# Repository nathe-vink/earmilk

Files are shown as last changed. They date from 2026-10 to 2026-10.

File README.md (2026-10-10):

# earmilk — handoff for renders and critic

Floorstanding hi-fi speaker shaped like a half-gallon gable-top milk carton. Concept is settled on the canvas; this repo exists to (1) produce photoreal renders the canvas cannot, (2) run the fresh-context critic against a studio bar, and (3) hold the spec so nothing drifts.

Canvas (source of truth for layout, copy and proportions): https://claude.ai/artifact/2XeD5nstYFumubxf6jdS1g

## The idea in four lines

- A serious passive three-way that is, unmistakably, a half gallon of milk — and a cabinet that outlives its skin. *Amended 2026-10-08: active, with a plate amplifier in the back; and a bookshelf sibling.*
- The treble fires forward from the throat of a concave bowl carved into the front gable panel. The bowl is the waveguide. *Amended 2026-10-08: the bowl is now a waveguide shaped by acoustic simulation, in an insert set into the roof.*
- The cabinet is birch; the carton is a two-piece sleeve of heavy printed board (tube + lid). Swap the sleeve, keep the speaker. *Amended 2026-10-02: no sleeve. The carton is the cabinet, finished in the flavour's colours; the colour is fixed per speaker. See Amendments, 2026-10-02.*
- Flavor is the colorway. Six flavors. One voicing. *(Five until 2026-10-08, when the owner added a green one: Matcha. Since 2026-10-09 a matcha-green body with British racing green on the gable, fin and plinth and in the tweeter's waveguide.)*

Voice: dairy deadpan. The spec sheet is an FDA-style Nutrition Facts panel. One joke per surface, maximum.

## Decisions already made (do not reopen)

- Tweeter lives in the gable, facing forward, set back in a **concave** bowl. Not square, not angled up, not sunk vertically.
- Gable and fin are the **same color as the body** (the lid covers them). Bare birch shows in exactly two places: the back window and the bowl's exploded/section views. *Amended 2026-10-01: on the white-board flavours (Whole, 2%, Skim) the lid is printed in the flavour's print colour; Chocolate and Oat stay one colour, lid included.* *Amended 2026-10-02: the same colours, now as a finish on the birch gable itself; the bare birch places are the back panel and the section views.*
- **No tuning concept.** No cap, no tuning plates, no swappable tweeter modules. Flavor = colorway only.
- Nutrition Facts are **engraved** on the birch back window, above the port, with the binding posts below. The printed label frame is a separate deliverable (the label artboard), not printed on the sleeve.
- The sleeve's back panel is a frame around the birch window. *Amended 2026-10-02: no sleeve; the birch panel stays, inset in the finished back, and carries the engraved wordmark above the Nutrition Facts.*
- Sleeve options are the five flavors; "Dairy / Kraft / Night" no longer exist as names. *Amended 2026-10-02: the five flavours are finishes, chosen once.*
- Pint (desk-size, six to a crate, crate = amp + charger) is **parked**. Render it only in the mixed-crate shot; do not design its electronics.

### Amendments, 2026-10-01

Made after the first render and critic rounds, from the explorations in `explore/`. They stand with the Decisions above.

- **Lids.** Whole, 2%, Skim and Matcha carry the lid (gable and fin) in the flavour's print colour. Chocolate and Oat stay one colour.
- **Band.** A printed band of the print colour, 110 mm tall, wraps the base of the sleeve (front and sides; on the back only the frame below the window). The wordmark sits in the band, reversed in the board colour, on the front and the right side. Nothing is printed under the gable.
- **Stand, optional.** A painted block in the print colour, 390 × 390 × 110, with a 6 mm reveal under the carton. It takes the band's job and its wordmark; a sleeve used on a stand is printed without the band. It does not swap with the sleeve. The speaker stays passive; if a version ever went active, the stand is where controls would live.
- **Owner's panel, optional.** A print-to-order "Have you heard me?" panel on the right side above the band, 300 × 330 mm, in the print colour: headline, a halftone portrait, four rows the owner fills in. Not on the default sleeve.
- **Dropped.** Print rings around the drivers and whole-side colour fields.
- Prices stay open: add `[STAND PRICE]` to the list.

### Amendments, 2026-10-02

Made on the v4 and v5 renders. They stand with the Decisions above and replace the 2026-10-01 amendments where the two disagree.

- **No sleeve.** The carton is the cabinet. The colourway is a finish on the birch: the body in the board colour, the gable and fin in the accent colour on Whole, 2%, Skim and Matcha, Chocolate and Oat one colour all over. The colour is fixed per speaker, so every edge and bevel takes it. Nothing swaps. `[SLEEVE PRICE]`, the board-stock question and the sleeve-swap shot go away.
- **Plinth.** The band and the stand are one thing: a built-in plinth, the bottom 110 mm of the cabinet on all four sides, in the accent colour, inside the 1,055 overall height, with a 3 mm shadow line where it meets the body. (The shadow line, and the plinth sitting inside the height rather than under it, are this repo's reading; say so if either is wrong.)
- **Wordmark.** On the front only, as cast metal letters: the wordmark itself standing in relief on the plinth's front, no plate behind it, the way the lettering sits on a La Marzocco machine. On the back, engraved in the birch above the Nutrition Facts panel. Nowhere else: not on the sides, not under the gable. *(A plate version was rendered first and withdrawn the same day.)*
- **Dropped.** The owner's panel. Other milk-themed marks that are not about the owner are explored in `explore/2026-10-02/` and are proposals, not spec.
- **Shots.** 07 (sleeve swap) is retired. 02 (two rooms) loses the swap that was its point; it is rendered meanwhile with the same Whole in both rooms and needs a new brief. In 03 the fold of the lid's die-cut becomes the finish's edge at the mouth; in 04 the sleeve frame becomes the finished back around the birch panel.
- Prices: `[PAIR PRICE]` and `[CRATE PRICE]` stay open. `[SLEEVE PRICE]` and `[STAND PRICE]` are gone.
- **Back panel, contained** *(later the same day)*. The bare birch field is the Nutrition Facts panel plus a 26 mm margin all round: `x` 36 → 354, `z` 504 → 796. The port, the binding posts and the engraved wordmark sit on the finish outside it; the wordmark is engraved through the lacquer and ink-filled in the panel's brown, baseline at `z` 812; the post plate moves up to `z` 150 so it clears the plinth's shadow line. The full-height field (`x` 26 → 364, `z` 140 → 830, the same 26 margin at the sides and above the plinth) is kept as an option; both are rendered in `explore/2026-10-02/r4-*`.
- **Marks** *(later the same day)*. Two carton lines are spec and nothing else is printed: OPEN OTHER SIDE with its arrow on the back slope of the gable, 27 mm caps in the gable's other colour (board colour on the white flavours, accent on Chocolate and Oat), and SHAKE WELL on the plinth's back face, 26 mm caps reversed in the body colour. The other proposals in `explore/` are dropped.
- **Facts border** *(later the same day)*. The engraved panel is 266 × 260: "Contains no milk." sits inside the border with the same 14 mm padding as every other side. The bronze plate grows with it to `z` 484 → 796.
- **Bronze plate** *(later the same day)*. The Nutrition Facts are an engraved bronze plate, not bare birch: the Facts panel plus a 26 mm margin (x 36 → 354, z 504 → 796), 3 mm thick, 1.5 mm proud of the finish, the engraving dark with patina. The wordmark above it is the same cast metal letters as the front (44 mm, 2.5 mm proud, centred at z 826). Bare birch now shows only in the section views.
- **Shot 02, rebriefed.** The two rooms are the same pair in two homes, years apart: a bright first apartment, then a darker older house. The point is no longer the swap but that the speaker outlives its rooms, the finish fixed and the birch back ageing with the house.

### Notes, 2026-10-03

Render notes, not product decisions. Nothing here changes the Geometry or the Decisions.

- **The render path is now path-traced.** Chat image models could not hold the carton (two hand-made attempts, in `explore/2026-10-03/`), and the free Gemini API tier refuses image calls. So the model built from `spec/geometry.md` is exported from the real-time scene and rendered in Blender's Cycles (`render/pathtrace.py`, the `-pt` frames): the same geometry and copy, real light. The real-time frames stay as the layout check.
- **Rooms and sets.** The three rooms are closed boxes now (ceiling, right wall, a wall behind the camera), so the only daylight is what the window admits; the studio floor sweeps up into a backdrop. Out of frame in every shot.
- **Eased arrises.** *Since 2026-10-07 the main arrises are rounded 3 mm in the model itself (Amendments 2026-10-07), and the shader eases what is left (the eave, the grooves' edges, the scoop's cut) by 1.5 mm.* Before that: the path tracer rounds the cabinet's edges by 6 mm in the shader (since v18; 4 mm from v15, about a millimetre before), the way lacquer on birch actually sits; the silhouette does not change. The radius scales with the cabinet: 1.5 mm on the pint (since v20; at 6 mm its 2 mm fin rounded right through and the cartons looked inflated). Since v18 each driver's hole in the finish sits 5 mm inside its flange, so the rounding no longer shades a grey ring round the driver. Until v16 the rounding never reached the corners: each panel of the finish is its own mesh and the bevel only sees its own object, so the path tracer now joins each cabinet's finish into one object first. The prompts' rule against softening edges is about the silhouette. *Say if the spec wants the arrises dead sharp.*
- **Critic notes that are spec, not render** (path-traced round 1): the spout reads as a lens barrel at room distance (02b); the crate's wall hides the pints' drivers (06); the chair is a massing model, not furniture (02a). None acted on.

### Notes, 2026-10-04: fabrication

Fabrication notes, not product decisions. Nothing here changes the Geometry or the Decisions.

- **`fab/` turns the spec into things a shop can make:** a parametric CAD model (STEP and STL for every part), DXF cut files for the 18 mm birch panels with a cut list and nesting (three 5 x 5 ft sheets for a pair), the gable as a laminated block split for 3-axis milling or as four printable pieces, the bowl test slice, a two-piece printed port, the cast-letter wordmark and its placing templates, the engraved Facts plate, the terminal plate, vinyl stencils for the two marks, shop drawings, an acoustic worksheet, a driver shortlist and a parts list. Start at `fab/README.md`.
- **The outside is the spec; the inside is proposed.** Joinery, the mid's 8.0 L chamber, the brace, the groove, the gable's split and the tweeter pocket are marked `PROPOSAL` in `fab/params.py` and listed in `fab/README.md`.
- **From the solids:** 88.1 L net for the woofer (inside the 85 to 90 L assumed), a 152 mm port for 32 Hz, 27 kg of wood per cabinet.
- **The label and the physics disagree on one line.** The engraved Facts say 91 dB; a woofer that reaches 32 Hz in this box is rated about 90 dB, and voiced flat on this baffle the speaker should measure 85 to 88 dB. Engrave after measuring. "8 ohm" may become 6: every tweeter that fits the bowl is 4 ohm. *2026-10-07: printed now, not engraved, and just as permanent under the clear, so print after measuring.*
- **The wordmark at 44 mm type is 172 mm wide,** as the renders show; geometry.md's "about 155" is an estimate the type size overrides. The fab files follow the type size.

### Amendments, 2026-10-05: the pint and the crate

Made by the owner on the v13 crate shot ("the top driver is missing … the crate itself can be improved"). They stand with the Decisions above; the pint stays parked otherwise.

- **The pint mirrors the floorstander's drivers.** A woofer low and a mid high on its face, the big one's heights scaled by the body ratio (woofer ø 68 at 67, mid ø 40 at 160, replacing the single full-range at 95), and a small dome tweeter at the throat of its bowl, as the floorstander's sits at the throat of its own: a faceplate filling the ø 17 throat and a dome of about ø 9. The owner chose this layout over keeping one driver on the face. Its electronics stay undesigned.
- **The crate is a dairy crate.** The same 340 × 250 × 130 and 2 × 3, now moulded in warm white instead of five boards: rounded corners, a rolled rim, latticed walls, a hand-hold in each short end, a floor. The long walls have one window per pint, sized and placed to frame each front pint's woofer whole, which the plain crate's wall hid (path-traced round 1 asked whether the wall should drop; the windows answer it without changing the height); the mids stand above the rim. Still a crate and nothing more: no ports, lights, cables or controls.
- **Render polish, not product decisions** (v14): the tweeters' faceplates carry a polished chamfer, so the driver deep in each bowl reads as a driver; the domes are coated textile, not black holes; the lacquer has a faint orange peel, the cones pressed paper, the floors grain and the walls plaster; the studio adds two tall strips behind the subject for edge lines; the chair is a dining chair, not a massing model.

### Amendments, 2026-10-06: the critics' design points

Made by the owner on four points the refinement critics raised (v14 to v16). They stand with the Decisions above.

- **Dark letters on the light plinths.** The cast letters on Chocolate's cream plinth and Skim's pale blue one are dark bronze (`#6B4A2C` faces, `#45301D` sides); polished, they read as white on white, as two critic rounds said of the line-up. The other three plinths keep polished letters. The back's letters are unchanged.
- **A polished lip at the scoop.** *Withdrawn 2026-10-07 (the owner): no lip, see below.* A stainless half-round lip rings the bowl's mouth over the finish's cut edge and the bowl's joint, 4.8 wide and 1.6 proud on the floorstander and scaled on the pint, the same on every flavour, so the opening reads as a made scoop and not a hole at room distance (every critic round read it as a hole, an eye or a lens).
- **A three-quarter back view.** Shot 04 has two frames: the straight-on back as before, and a three-quarter from the back-left with the gable's end, a side and the cabinet's shadow, which every critic round on the back asked for.
- **Chocolate's throat runs dark,** from the body brown at the mouth to a dark chocolate at the throat (`#5E3A1F` to `#2B170B`; it ran cream to tan, paler than the brown face around it).
- **Render polish, not product decisions** (v17): the tweeter's faceplate sits in a moulded ring where the throat ends (the close-up's critic saw no seat); the hero's window moves to the wall behind the camera so the sun takes the fronts; the bright room's window narrows so its beam lands on the cabinet; the older room's window widens so its patch shows on the back wall. v18 and v19: the hero's and the older room's back walls come nearer, so each cabinet's shadow climbs the wall in the sun's patch; the bright room gets a French door, so the cabinet's whole shadow lies on sunlit boards; the studio sweep turns to face the three-quarter back camera; the crate's rows sit 136 apart, so each woofer stands just behind its window; the tweeter's seat ring is satin metal (black, it vanished against the faceplate).

### Amendments, 2026-10-07: the Facts printed on the body

Made by the owner after the v17 to v19 critic rounds. They stand with the Decisions above and replace the 2026-10-02 bronze plate.

- **The Nutrition Facts are printed on the body, not on a bronze plate,** so the back reads like a real carton's. The same panel (266 × 260, top at z 770, the copy in `copy/label.md`) is printed directly on the back's finish: a warm near-black (`#1E1A17`) on the white flavours, the print colour on Chocolate (cream) and Oat (brown). The plate, its pocket and its patina go; the cast letters above and the port and posts below stay where they are.
- **It must not scratch off, so the ink goes under the clear.** The panel is printed on the cured colour coat and buried under the 2K clear that covers the whole cabinet, then flatted level, the way a guitar's headstock logo is sealed: a scratch has to cut through the clear before it reaches the ink. On the assembled cabinet that is a screen print with a catalysed (2K) ink, or a water-slide decal for a one-off; test the ink under the clear on a sprayed card first, as with the colours (`fab/README.md`, step 7). OPEN OTHER SIDE and SHAKE WELL are already in the paint, so all three printed marks now sit under the clear.
- **No lip at the scoop, and no bright metal.** The polished stainless lip of 2026-10-06 goes: the bowl's mouth is the finish's own cut edge, eased, and the tweeter's chamfer and seat are moulded black. Four options were rendered (`explore/2026-10-07/`); the owner chose this one, "it looks like a diner" being the polished lip's problem.
- **The edges are rounded in the model.** 3 mm on the body's four vertical corners and the gable's four hips, 1.5 mm on the fin's edges, scaled on the pint, so the corners catch a highlight and the outline softens by that much (it was dead sharp, with the rounding only in the shader; nearly every critic round called the edges knife-sharp). This replaces the render rule against softening edges.
- **A shadow line under the gable.** A 3 mm dark groove where the gable meets the body, `z` 857 → 860 on all four sides, like the plinth's at 110 → 113, so the gable reads as a separate, made part.
- **OPEN OTHER SIDE on the fin** (later the same day): the line and its arrow move from the back slope to the fin's back face, the top fold, centred on its visible height, the same 27 mm caps in the gable's other colour; the slope stays clean. Rendered both ways in `explore/2026-10-07/r7-*`; the owner chose the fin.
- **The back's letters centred between the edge and the Facts** (later the same day): set at `z` 813 (was 826), so their ink has 27 mm of white above it, to the shadow line under the gable, and 27 mm below, to the Facts' top border.
- The canvas still shows the bronze plate (since its version 13), the lip and sharp edges. It is not edited from here; say if it should be.
- **Render polish, not product decisions** (v22, v23): the rounds after the owner's geometry changed the sets, the lenses and how the finish is modelled, not the product. v22: one camera for both rooms of shot 02, as its brief asks, wider and level; the hero's camera further round and closer, its back wall 2.5 m behind the pair, so no carton's shadow climbs it; the bright room's sun lower, laying its patch on the wall behind the chair; the close-up's key a narrow strip and the bowl's paint flatter; the backs and the line-up on a darker set with the backdrop lit on its own; the crate whole on the left page. v23: the finish modelled as what it is, a colour coat with no gloss of its own under a full 2K clear (it was a glossy colour coat under a thin clear), and the clear takes the eased edges; AgX's very high contrast look in the studio, so the white reads white; an edge light on each corner the camera sees, seen only in reflections where a 3 mm round is a pixel or two wide; the straight-on back shot from 1.3 m, level, because from the panel's height the gloss roof mirrored the fin's OPEN OTHER SIDE upside down beneath it (a real lacquered carton would do the same); the port's tube a real black plastic's 3 % (it was 1 %, which read as a hole).

### Amendments, 2026-10-08: the critics' requirements

Made by the owner after the v21 to v23 critic rounds on the 2026-10-07 look ("address the additional critic requirements"): the five points those rounds raised and this repo put to the owner. They stand with the Decisions above.

- **The edges rounded 6 mm.** The body's four vertical corners and the gable's four hips 6 mm, the fin's edges 3 mm (3 and 1.5 on 2026-10-07): at room distance a 3 mm round is two pixels, and every critic in the batch still called the corners knife-sharp. Scaled on the pint.
- **The tweeter forward, on a seat.** The faceplate 125 behind the front face (it was 170) in a 74 throat (it was 66), whose end is a flat ring 6 wide in the throat's colour with the faceplate flush in it, its chamfer black. From 170, every camera off the axis saw the faceplate pushed into the far end of the mouth and cut by its rim, a lens or an eye. The mouth is unchanged, so the bowl is shallower: its lower lip still bounds the pattern, at about 17° below the axis (12° before); the upper lip no longer does (37° before). The tweeter reaches a seated listener 0.24 ms after the mid in the crossover model (0.37 before). The pint's bowl follows by its scaling rule (throat ø 19).
- **The drivers flush and finished.** Each frame sits in a rebate, a satin black trim ring over it and its screws, the ring's face level with the finish and a 0.8 reveal round it; the cones charcoal paper with pressed concentric ribs, the dust caps satin. Proud on bare frames with eight screws, every round read them as stock parts. The woofer moves up 30, to `z` 320, so its frame clears the plinth's shadow line by 52 (it was 22). The pint's woofer stays where its crate's windows frame it.
- **The cast letters 1.5 proud, their sides finished like their faces,** front and back (at 2.5 with darker satin sides they read as an extrusion with a drop shadow).
- **A recessed terminal cup.** The posts stand on the floor of a cup 18 deep; its 128 × 64 flange, 3 proud of the finish on four screws, is centred at `z` 175 (the flat plate at 150 sat 5 above the plinth's shadow line, its black post lost on it).
- **The Facts values in bold,** like the names (Regular read pale grey at every size short of full).
- **Two briefs change.** Shot 04a becomes a straight-on detail of the label, and shot 05 a raised three-quarter of the five with the frame's centre line between two cartons; every critic round asked for a three-quarter of each.
- **Render polish, not product decisions** (v24 to v26): every frame through Khronos PBR Neutral rather than AgX, whose looks turned a lit red salmon and a lit blue periwinkle; the indirect light clamped against fireflies; the studio's edge strips hidden from the camera, and in the line-up gone; figure in the floorboards' colour, broad enough to read across a room; lights seen only in reflections, placed where a round or a slope mirrors them into the camera, on the cartons' corners, the slopes and the cast letters (v26: thin lines, not bands); the clear polished (roughness 0.05, was 0.1) with less orange peel, so a light draws a line rather than a pink wash; the cast letters' planes cut down to their glyphs, so the denoiser draws no rectangle round them on a dark plinth; the label detail shot from 1.9 m, so the gloss slope no longer mirrors the fin's OPEN OTHER SIDE; the close-up on a 100 mm lens; in the rooms, a cool fill from the hero's camera side, the bright room's left wall given the skirting the back wall had, and the older room's back wall nearer, so the low sun lays a silhouette that reads as the carton. Found by the critics and fixed in the model: with 6 mm rounds the birch core's square corners stood through the finish, first at the rounds, then where the gable's shadow line meets them.

### Amendments, 2026-10-08 (later): active, the waveguide by simulation, the bookshelf

From the owner's request of 2026-10-08: the tweeter's job is to spread sound correctly, so its shape is optimised for
that whatever it looks like; build proofs of concept of a floorstander and a bookshelf; model the real equipment
that goes in them, built-in amplifiers included.

- **Active.** A Hypex FusionAmp plate amplifier in each speaker (FA253, three channels, in the floorstander; FA122,
  two, in the bookshelf) drives each driver from its own channel; its DSP is the crossover, delays and EQ. The plate
  sits flush in a rebate on the back, its module in its own sealed box. The passive network (`fab/crossover.py`) is
  gone; the DSP's starting setup is `fab/dsp.py`. The research is in `fab/research/amps.md`.
- **The waveguide replaces the bowl,** designed and checked by a boundary-element simulation of the whole roof
  (`fab/bem.py`): the floorstander's throat at 176 behind the face and 935 up holds about +-40 degrees horizontally
  from 2 to 8 kHz with the listening axis within a dB of the loudest direction; the owner's 125 / 903.5 beamed 30
  degrees up at 2 kHz. It is a separate insert in a pocket in the roof, the tweeter rear-mounted on it, held by
  magnets and unplugging at a connector in a bay behind it, so the tweeter can be serviced from the front.
  `fab/out/acoustics/waveguide/README.md`.
- **The drivers are named:** Dayton RSS315HF-4, SB Acoustics Satori MR16P-8 and TW29DN-B (its faceplate off) in the
  floorstander; SB Acoustics SB17NRX2C35-8 and Scan-Speak Illuminator D3004/602200 in the bookshelf
  (`fab/research/`). The renders' drivers and amplifier plates are modelled from their datasheets.
- **The bookshelf:** the same carton at 220 x 220 plan and 594 tall, a sealed two-way with the woofer high on the
  face, its own waveguide study (it crosses at 2.4 kHz), the Facts on its right side as on a real carton because the
  back holds the amplifier. Built from the same `fab/params.py` with `EARMILK_SIZE=bookshelf`, into
  `fab/out-bookshelf/`.
- **For the owner:** the Facts' "8 ohm" and "91 dB" mean nothing on an active speaker (the inputs are line level);
  the bookshelf's Facts already say power and inputs instead. Raising the mid to z 760 would widen the floorstander's
  vertical window at the crossover from about 14 to 20 degrees. Both are the owner's to decide.

### Notes, 2026-10-04: tools and the family

Tooling notes, not product decisions. Nothing here changes the Geometry or the Decisions.

- **From scratch.** `studio/setup.sh` installs every tool the repo uses on a bare machine (render/'s node modules, Blender's `bpy`, the CAD venv) and `python3 studio/doctor.py` runs each one for real. In a Claude Code cloud session the start hook does this before work begins. `studio/README.md` lists the tools: a path tracer for any product's scene, canvas-exact typesetting, a crossover designer, a product template.
- **Crossover, from models.** *Superseded 2026-10-08: the speakers are active and `fab/crossover.py` is gone; see the amendments above.* `fab/crossover.py` fits a three-way network to the shortlisted drivers (`fab/out/xover/`): Linkwitz-Riley targets at the label's 350 Hz and 2.2 kHz, 14 parts, the sum within about 2 dB from 150 Hz to 16 kHz in the model. Two numbers to carry: the tweeter, 170 mm back in the bowl, reaches a seated listener 0.37 ms after the mid; the network's impedance bottoms at 3.7 ohm, a 4 ohm speaker. *2026-10-08: 125 mm back, 0.24 ms and 3.5 ohm.* Fit the built network to measurements.
- **The family.** Two spin-offs are started in `spinoffs/`, each with its own brief, model, renders and critic log: **earworm**, wired headphones whose cable is an earthworm (the saddle is the remote), and **earwig**, earbuds whose flexible tails of overlapping plates end in forceps, with a case whose lid is split like an earwig's wing covers (the wig went, 2026-10-06). Proposals for the owner; neither touches earmilk's spec.

## Geometry (mm)

Floorstander — square plan, gable-top.
- Plan 390 × 390. Body 860 tall. Gable rise 150 (front edge → ridge). Fin 45 above the ridge, ~8 thick. Total height 1,055.
- Carton proportions match a US half gallon scaled ×4.1. Slope panel length along the slope: 246.
- Cabinet: 18 mm Baltic birch, braced. The gable is a solid carved birch block on top of the body (CNC).
- Front drivers (centers from floor, on the baffle centerline): 12 in woofer at 290 (frame ø ~310); 6.5 in mid at 690 (frame ø ~170). *Amended 2026-10-08: the woofer at 320; both flush, under satin black trim rings.*
- Tweeter: 1 in dome with a small faceplate (≤ 62 mm). Faceplate plane is 170 back from the front face; dome center height 903.5. *Amended 2026-10-08: 125 back.*
- Bowl: mouth is an ellipse on the front slope panel, 211 wide × 118 long along the slope, centered 79 up the 246 slope (from 20 to 138). Throat ø 66 around the faceplate at the 170 setback. Surface is a smooth loft from mouth ellipse to throat circle — no flats, no edges. As drawn the lower lip holds the pattern to ~12° below the tweeter axis and the upper lip to ~37° above. Deeper bowl = narrower; wider mouth = wider. *Amended 2026-10-08: throat ø 74 at the 125 setback, the faceplate seated flush on its flat floor; the lower lip holds the pattern to about 17° below the axis and the upper lip no longer bounds it.*
- Back (bare birch window inside the sleeve frame): window x 26→364, z 40→798. Engraved Nutrition Facts panel 266 wide × 240 tall, top at z 770 *(266 × 260 since 2026-10-02)*. Round port ø ~100 centered at z 405. Binding posts on a 128 × 64 plate centered at z 144. *Amended 2026-10-08: in a recessed terminal cup, its 128 × 64 flange centred at z 175.*
- Sleeve: tube 390 × 390 × 860 (open top and bottom, die-cut for woofer and mid, back panel is a frame), plus a lid covering gable + fin, die-cut at the bowl mouth. Both lock at the back seam. Board: heavy carton board / SBS, target ~1.2–1.5 mm; whether it holds a crisp fold at this size is an open test. *Amended 2026-10-02: no sleeve. The outer dimensions stay; the skin is the finish.*

Pint — 100 × 100 plan, body 200, gable 35, fin 12. Single full-range ø ~68 at 95; tiny bowl at the top. Crate 340 × 250 × 130, 2 × 3. *Amended 2026-10-05: a woofer ø 68 at 67 and a mid ø 40 at 160 on the face, a small dome tweeter at the bowl's throat; the crate is a moulded dairy crate whose windows frame the front pints' woofers.*

Stand (optional accessory, amended 2026-10-01) — 390 × 390 × 110 painted block, 6 mm reveal. With the stand: overall 1,171; tweeter axis 1,019.5. *Amended 2026-10-02: replaced by the built-in plinth, z 0 → 110 of the cabinet, accent colour, 3 mm shadow line at z 110 → 113; overall height stays 1,055.*

Wordmark on the plinth (amended 2026-10-02) — cast metal letters, no plate: Archivo Black at 44 mm type size, 2.5 mm proud (*1.5 since 2026-10-08*), centred on the plinth's front at z 55. Back wordmark engraved in the birch panel, 36 mm type size, baseline at z 788, centred; the birch panel now runs z 113 → 830 so it has room (x 26 → 364 as before).

## Target specs (label copy — marked as targets, not measured)

Sensitivity 91 dB (2.83 V / 1 m) · 32 Hz–20 kHz ±3 dB · 8 Ω · 40–250 W · crossover 350 Hz and 2.2 kHz · 36 kg each · 1,055 mm.
Footnote stays: "Contains no milk. Not a significant source of Bluetooth."

## Colorways (flavors)

White board unless noted. Print = wordmark on front and side. Throat = bowl interior, light at the mouth → dark at the throat. *Amended 2026-10-01: print = the lid on the white flavours, a 110 mm base band, and the wordmark in the band on the front and the right side; see Amendments.* *Amended 2026-10-02: "board" is the body finish and "print" is the accent finish (gable and fin on the white flavours, the plinth on all five); the wordmark is the badge and the back engraving, not print.*

| Flavor | Board | Print | Throat (mouth → throat) |
|---|---|---|---|
| Whole | #FFFFFF | #C62828 | #C62828 → #8E1B1B |
| 2% | #FFFFFF | #1F4FCF | #1F4FCF → #153792 |
| Skim | #FFFFFF | #6FA5DC | #8FBBE8 → #4F86BF |
| Matcha | #A4C26B matcha green | #004225 British racing green | the gable, fin, plinth and the tweeter's waveguide insert in the accent, as on the other flavours *(added 2026-10-08; the body matcha and the insert dark green since 2026-10-09, the owner)* |
| Chocolate | #5E3A1F (whole board) | #F1E3CC | #5E3A1F → #2B170B *(2026-10-06; was #E2CBA3 → #A97E4F)* |
| Oat | #D9BC92 unbleached | #2B2118 | #8E6A3E → #5C4224 |

Birch: #EAD8B0 face, #D4BE95 side, engraving #6B5232. Ground for flat compositions: #F8F7F4.

## Type

Archivo Black (wordmark, label title) over Archivo (everything else). The wordmark is lowercase "earmilk", tight tracking. Nutrition Facts panel follows FDA proportions: heavy title, 10 px rule, 1 px row rules, bold labels, right-aligned values.

## What this repo produces

### 1. Renders (image generation happens here, not in chat)

Photoreal, physically plausible materials: matte printed board with visible fold creases at the gable, birch end-grain at the back window, black paper cones, the throat as a smooth painted bowl. No grilles. No glossy plastic. Proportions exactly as the geometry above — the carton silhouette is the whole idea, so do not "improve" it.

Shot list, in priority order:
1. **Hero pair in a room.** Whole, late-afternoon window light, a chair or sofa arm in frame for scale, speakers ~2 m apart, 3/4 view, camera at 1.2 m with a ~50 mm look.
2. **Two rooms, years apart.** The same floor spot and the same speaker, once in Whole in a bright apartment, once in Oat in a darker, older room. This is the sleeve argument; it must read as one object that changed its skin. *Amended 2026-10-02: no sleeve, so no skin change. Rebriefed: the same pair in two homes, years apart, a bright first apartment and then a darker older house; the point is that the speaker outlives its rooms.*
3. **Bowl close-up.** Front 3/4 at gable height, the throat and the dome in focus, the fold of the lid's die-cut visible at the mouth edge. *Amended 2026-10-02: the mouth edge is the finish's edge on the carved gable.*
4. **Back.** Straight-on, engraved label legible, port and posts, the sleeve frame around the birch. *Amended 2026-10-02: the finished back with the bare birch field around the Facts panel only, the wordmark engraved above it, the port and posts on the finish below.* *Amended 2026-10-06: two frames, (a) straight-on as before and (b) a three-quarter from the back-left, about 33° off the back face and 10° up, with the gable's end, a side and the cabinet's shadow in frame.* *Amended 2026-10-07: the Facts printed on the finish, legible, no plate.*
5. **Six flavors lineup.** Flat ground, equal spacing, in flavor order.
6. **Mixed crate** on a desk, six pints, one of each flavor.
7. **Sleeve swap**, three frames: lid off, tube sliding, new flavor on. *Retired 2026-10-02: no sleeve.*

Keep every render's dimensions consistent; drift in the carton's proportions between shots is a failure.

### 2. Critic

Run after each render batch. Fresh context, screenshot only — the critic sees images, not the brief, not this file. Prompt it as a design-studio creative director with a shipping bar: name the three biggest gaps, say what a studio would fix first, score /10. Iterate at most three rounds per shot. Log each round in `critic/LOG.md` (shot, round, gaps, score, what changed).

### 3. Spec drift check

Before any render or edit, re-read the Geometry and Decisions sections. If a change to them seems necessary, stop and ask; do not improvise a new mechanism, a new flavor, or a new driver layout.

## Open questions (do not assume answers)

- Price points for the pair, a sleeve set, and the crate. Leave as `[PAIR PRICE]`, `[SLEEVE PRICE]`, `[CRATE PRICE]`, and since the amendments `[STAND PRICE]`. *Amended 2026-10-02: `[PAIR PRICE]` and `[CRATE PRICE]` only.*
- Driver selection and port tuning. The 32 Hz target assumes ~85–90 L net for the woofer; confirm before quoting it as more than a target. *2026-10-04: the CAD measures 88.1 L net; `fab/README.md` has a driver shortlist, the port (152 mm for 32 Hz) and a simulation. Proposals, not answers.*
- Whether the bowl works as a waveguide. The test is physical: one carved gable, one candidate tweeter, on/off-axis measurements vs. a flat baffle. Renders do not settle this. *2026-10-04: `fab/out/stl/gable-test-slice.stl` is that gable, printable in a weekend.*
- *Added 2026-10-04, from the crossover model:* whether the label's crossover points (350 Hz and 2.2 kHz) survive measurement, whether the 0.37 ms the bowl puts between mid and tweeter is handled passively or the tweeter comes forward, and whether the label can say 4 ohm. *2026-10-08: the tweeter came forward to 125 (the owner, for the look), which cuts it to 0.24 ms in the model.*
- *Added 2026-10-04, from fabrication:* whether the Facts should state targets or measured figures (91 dB and 8 ohm are unlikely as measured; the plate is permanent, and so is the print under the clear that replaced it on 2026-10-07); whether the gable may be printed and painted instead of carved birch; the letters' metal (silver as rendered: stainless or aluminium; or brass to sit with the bronze plate); whether the wordmark's width (172 mm at 44 mm type) or geometry.md's "about 155" is the one that matters.
- *Added 2026-10-03, from the path-traced critic rounds:* whether the pint crate's wall should drop so the drivers show; whether the spout's dome needs a different read at room distance (three rounds called it a lens barrel); whether the cast letters on Chocolate and Oat should be a darker metal, since polished metal on a cream plinth reads as blank in a pale studio; and whether the tweeter wants a visible flange in the bowl. All geometry or materials; none acted on in renders.
- *Added 2026-10-06, from the v17 to v19 critic rounds (the first two answered 2026-10-07: a 3 mm shadow line under the gable, and the arrises rounded 3 mm in the model):* a reveal where the gable meets the body (the plinth has its 3 mm shadow line; the gable has none), asked for in this batch and the last; whether the arrises may be eased in the model, rounding the silhouette by 6 mm (the render rules keep it sharp, and the shaded rounding has not cleared the critics' "knife edges" in any round); taller crate windows that also show the plinths, so each woofer reads as its carton's; whether the back's letters, polished on every flavour, should go dark on the white bodies as the light plinths' have; a narrower Facts table, since at a raking angle its right-aligned values read as one row low. The tweeter at the back of its throat has read as an eye, a lens or a webcam in most rounds since v14 (the 2026-10-03 question on the spout's dome stands). None acted on in renders.
- *Added 2026-10-08, from the critic rounds on the owner's 2026-10-07 look (v21 to v23):* the tweeter still reads as a lens or an eye from off its axis (the bright room: "the carton seems to watch the room"; the line-up: "pupil, pupil, pupil"), and in the line-up Chocolate's and Oat's darker throats hide it, so the row reads as two models; the woofer's frame sits close to the plinth's shadow line, which the critics call bottom-heavy; the cast letters' 2.5 mm sides read as a drop shadow on the light plinths; and the edges: at room distance a 3 mm round is two pixels, every critic in the batch still called the corners knife-sharp, and about 6 mm is what would read (3 mm was my recommendation). All spec, so left as they are. *Answered the same day by the owner: see Amendments, 2026-10-08.*
- *Added 2026-10-08, from the v24 to v26 rounds on the owner's answers:* the tweeter, seated 125 back, still sits against the scoop's upper lip from any camera above its axis (the crate from 21 degrees above: "a pupil rolled up"; the bright room: "a webcam lens or an eye"), because the throat's end is 15 mm behind the upper lip and from above projects at the top of the mouth; whether the close-up (03) and the label detail (04a) may be briefed as whole cartons on a floor, which every critic of both asked for in every round; the wordmark's tight tracking, at which the a's bowl all but touches the r's stem (cast letters that touch are cast as one, or the tracking opens a little); the Facts' band under the title, empty as drawn on the canvas, which a critic read as a missing row; Skim's dark bronze letters, which the line-up's critic read as Chocolate's brown.
- *Added 2026-10-10, from the engine's critic rounds:* the woofer's cone. The spec (2026-10-08) asks for charcoal paper cones with pressed concentric ribs; the floorstander's shortlisted woofer, Dayton's RSS315HF-4 (chosen for its Qts and Vas against the 88 L box and its excursion, `fab/research/drivers-floorstander.md`), has an aluminium cone, and the renders show that cone (critics have read it as anodised metal, blue or bronze by turns, from what it mirrors). Either the paper look moves to a paper-coned woofer (the research's alternative is the DS315-8, coated paper, with far less excursion) or the spec takes the aluminium cone. The trim rings, which rendered as a gunmetal the critics read slate-blue, were put back to the spec's satin black the same day.
- Board stock for the sleeve and whether the lock survives repeated swaps. *Gone 2026-10-02 with the sleeve. In its place: the finish system (lacquer, paint or laminate over the birch) and the badge's metal are open.*

## Suggested layout

```
spec/        geometry.md (this file's numbers, expanded), colorways.json
copy/        label.md, hero.md
prompts/     one file per shot, versioned
renders/     YYYY-MM-DD/shot-NN-vN.png
critic/      LOG.md
render/      the model, the real-time and path-traced renderers
fab/         fabrication: CAD, cut files, drawings, acoustics, crossover, parts list (fab/README.md)
studio/      the tools for any product: setup, doctor, path tracer, typesetting, crossover designer, template
spinoffs/    the rest of the family, one folder each: earworm (wired headphones), earwig (earbuds)
.claude/     the cloud session's start hook and the project skills (new-product, pathtrace, critic-round, fab-package)
```

## Deliver pass already applied (for context)

Cut: the cap and all tuning concepts; the four-way treble study (replaced by one section); printed Nutrition Facts on the side panel (now engraved on the back; side carries the wordmark); the flavor word under the wordmark; the Gallery sleeve; the Ingredients footnote; duplicate engravings; the full-carton sleeve (now tube + lid); the Dairy/Kraft/Night skins (folded into flavors).

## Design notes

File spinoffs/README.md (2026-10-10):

# The earmilk family

Products that share earmilk's rule: one joke, said once per surface, on a product that would be good without it.
Each folder holds a brief (`README.md`), its numbers (`params.py`), a parametric model (`model.py`, build123d), a
scene for the path tracer (`scene.py`), renders and a critic log. All of it is a proposal until the owner signs it.

| Product | What it is | The joke | Status |
|---|---|---|---|
| [earmilk](../README.md) | floorstanding three-way speaker | a half-gallon milk carton | spec, renders, fabrication package |
| [earworm](earworm/README.md) | wired over-ear headphones | the cable is an earthworm; its saddle is the remote | concept: model, printable cups, renders, critic |
| [earwig](earwig/README.md) | true-wireless earbuds | flexible tails of overlapping plates ending in forceps (pinch to play); a lid split like wing covers | concept: model, renders, critic |
| [earnest](earnest/README.md) | valve amplifier, by the pack of 6, 12 or 24 | an egg crate whose eggs are the valves; a white egg turns the volume | concept: model, renders |
| [barkhorn](barkhorn/README.md) | two-way hybrid horn loudspeaker, after Friendly Pressure | none: birch bark or eucalyptus bark, each horn painted from its bark's colours | concept: fab package (studio/fabkit), proof renders |

Start the next one with `python3 studio/new_product.py NAME --title NAME --kind "What it is"`, then follow the
`new-product` skill (`.claude/skills/new-product/SKILL.md`).

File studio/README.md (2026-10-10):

# studio: the tools, for any product in the family

Everything here works from a bare container: `studio/setup.sh` installs it and `python3 studio/doctor.py` proves it
runs. In a Claude Code cloud session the start hook (`.claude/hooks/session-start.sh`) runs `setup.sh` for you.

| Tool | What it does | Runs on |
|---|---|---|
| `setup.sh` | Installs everything the repo needs: render/'s node modules, Blender's `bpy` with numpy 1, the CAD venv `.venv-fab` with build123d, ezdxf, HarfBuzz, matplotlib, scipy. Idempotent: a few seconds when nothing is missing. `--doctor` runs the doctor after. | bash |
| `doctor.py` | Runs every tool for real at a tiny size: Chromium draws WebGL 2, Cycles renders a cube, build123d builds and exports a solid and HarfBuzz sets the wordmark, earmilk's spec check passes. Exits non-zero on any failure. | system Python |
| `fabkit/` | A fabrication package for any concept from one product file: each part a solid with how it is made (cut from sheet, printed, machined, bought) and finished. The kit reads the cut files (DXF layers by operation, nested on stock), checks clashes and print walls, writes the parts list with budgets, an A3 drawing set (arrangement, section, exploded view, every panel with a feature table, printed parts) and the render model with a proof shot for the engine. Speaker helpers: drivers from datasheet numbers, Thiele-Small boxes, horn profiles. See `fabkit/README.md`; the worked example is `fabkit/example/product.py`. | `.venv-fab` |
| `new_product.py` | Starts a product from `template/`: `python3 studio/new_product.py earworm --title earworm --kind "Wired headphones"` makes `spinoffs/earworm/` with a brief, `params.py`, `model.py`, `shots.json` and a critic log. | system Python |
| `engine/` | The render engine: a product's CAD (a GLB of named parts) and a shot file of named settings in, a photograph out, with the resolved settings, each part's place in the frame and a part-id mask beside it, so a critic can measure by part and prescribe changes the next render applies. Rooms and sweeps, sun, sky, lamps and glints, materials by part name, prints as decals under the finish, exploded views, cutaways, several products in one frame. See `engine/README.md`. | system Python (bpy) |
| `pathtrace.py` | Path-traces a product scene described in JSON with Blender's Cycles: CAD meshes, generated tubes (cables and worms: grooved rings or overlapping segments like a jointed toy snake, blended bands, radius by distance, flattening on a floor), Python hooks (hair), material presets, light rigs that size themselves to the subject with strips and pins, cameras with depth of field. | system Python (bpy) |
| `poses.py` | Lays small parts down on a floor: a part's up and length vectors, a heading, and it tilts until both ends rest (earbuds on a table). Returns the scene's translate and rotate, and maps points on the part into the world (where a cable leaves a bud). | any Python |
| `typeset.py` | Sets text exactly as the canvas does (HarfBuzz shaping, canvas-style tracking) and writes SVG, DXF and vector PDF: wordmarks, plates, stencils, debossed lettering in CAD. | `.venv-fab` |
| `xover/xover.py` | Passive crossover design: drivers from FRD/ZMA measurements or Thiele-Small models, any R/L/C network by nodal analysis, delays from where the drivers sit, a least-squares fit to Linkwitz-Riley or Butterworth targets, values snapped to parts you can buy, plots and a parts list. See `xover/README.md`. | `.venv-fab` |
| `template/` | The skeleton `new_product.py` copies. | |

Why two Pythons: Blender 5's `bpy` wheel needs numpy 1 and build123d needs numpy 2. `bpy` stays on the system Python
and the CAD stack lives in `.venv-fab`. Installing build123d into the system Python breaks the path tracer;
`setup.sh` puts numpy 1 back if that happens.

The workflows are written up as project skills in `.claude/skills/`: `new-product`, `pathtrace`, `critic-round` and
`fab-package`.

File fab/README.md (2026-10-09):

# Fabrication

Everything needed to have earmilk made, in two sizes, from one file of numbers (`params.py`): the **floorstander**, a
three-way, and the **bookshelf**, its two-way little sibling. Both are active: a Hypex FusionAmp plate amplifier in
the back drives each driver from its own channel, and its DSP is the crossover. Change a number, run `build.sh`, and
every cut file, model, drawing, chart and the renders' model follow. `fab/out/` holds the floorstander,
`fab/out-bookshelf/` the bookshelf.

The outside is the spec (`spec/geometry.md`; the bookshelf is the same carton at 0.564 scale with its own plinth and
type sizes). What is inside, and how it goes together, is this folder's **proposal**, marked `PROPOSAL` in `params.py`;
the bought parts' sizes are the research's, marked `PLACEHOLDER` until the parts are in hand.

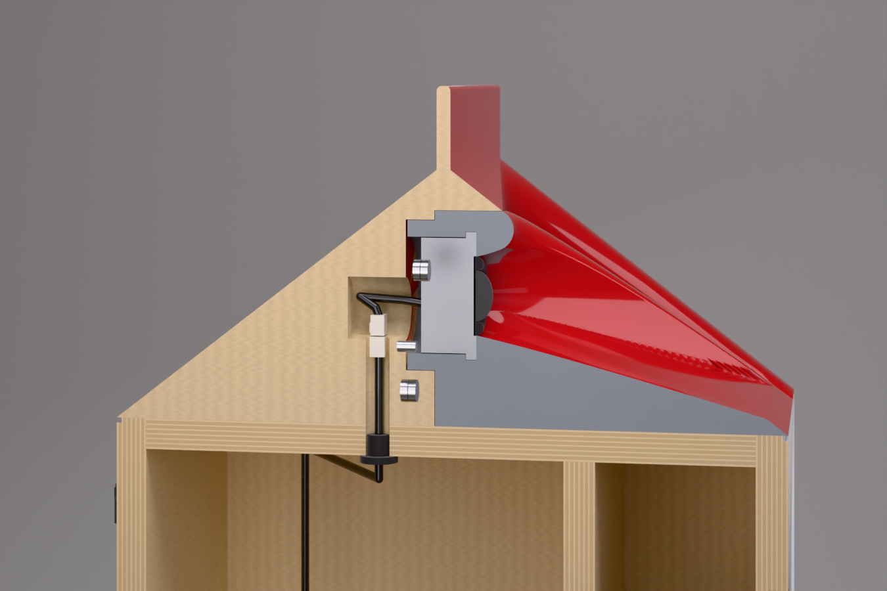
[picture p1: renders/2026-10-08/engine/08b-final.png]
The roof in section: the waveguide insert, the tweeter rear-mounted on it, the connector bay and the cable down to the amplifier


## The two speakers

| | Floorstander | Bookshelf |
|---|---|---|
| Size | 390 x 390 mm, 1,055 tall | 220 x 220 mm, 594 tall |
| Ways | three, active | two, active |
| Woofer | Dayton Audio RSS315HF-4, 12 in, in 81 L vented to 32 Hz (port 171 mm): f3 about 28 Hz | SB Acoustics SB17NRX2C35-8, 6.5 in, in 9.2 L sealed: f3 63 Hz, a DSP shelf takes it to 45 Hz |
| Mid | SB Acoustics Satori MR16P-8, 6.5 in, in its own 7.6 L sealed chamber | none |
| Tweeter | SB Acoustics Satori TW29DN-B, its faceplate off, rear-mounted on the waveguide insert | Scan-Speak Illuminator D3004/602200, its 62 mm faceplate on the insert's back |
| Waveguide | C22: throat 176 behind the face, 935 up; holds about +-40 degrees horizontally from 2 to 8 kHz | BkD: throat 95 behind the face, 517 up; about +-56 degrees at 2.5 kHz, +-32 from 6.3 kHz |
| Amplifier | Hypex FusionAmp FA253: 250 + 250 + 100 W into 4 ohm, DSP, on its side across the back's foot | Hypex FusionAmp FA122: 2 x 125 W into 4 ohm, DSP, upright on the back |
| Crossovers | 300 Hz and 2.8 kHz, Linkwitz-Riley 24 dB/octave | 2.4 kHz, Linkwitz-Riley 24 dB/octave |
| Wood | 24.8 kg of 18 mm Baltic birch | 6.0 kg |
| Drivers and amplifier, the pair | about $2,520 | about $1,330 |

The figures are simulations and datasheets (below); measure the built speakers before printing the Facts.

## Read this before ordering anything

- **Measure the bought parts first.** Every cutout, rebate and the tweeter's counterbore comes from the research
  (`research/`), which could not open the makers' drawings from this environment: the TW29DN-B's size with its
  faceplate off, the woofers' flanges, the FusionAmps' screw patterns. Buy one of each, measure, edit `params.py`, run
  `build.sh`. The CAD checks its own clearances on every build (`cad.json`, "checks") and stops if a change makes two
  parts collide.
- **The Facts' "8 ohm" and "91 dB" mean nothing on an active speaker.** Its inputs are line level, so impedance and
  sensitivity are not the buyer's business. The bookshelf's Facts already say power and inputs instead; the
  floorstander's should too (an owner's decision).
- **The floorstander's port runs out of air at full power.** At the amplifier's full 250 W near 30 Hz the port's air
  reaches about 50 m/s and will chuff; at a loud 100 dB it is 12 m/s and silent. Set the DSP's high-pass at about
  25 Hz and its limiter to the woofer's excursion.
- **The bookshelf's bass shelf costs excursion.** Its +8.3 dB shelf to 45 Hz needs a 35 Hz high-pass in the DSP.
- **Print the waveguide insert fine and tough.** Its walls are the acoustic surface the simulation was run on: 0.1 mm
  layers or finer, in a tough (ABS-like) SLA resin or MJF nylon, which hold the tweeter's screws in 2 mm walls; filled
  and sanded smooth before the paint. One piece from a service; the floorstander's halves only on a desktop printer.
- **The wordmark is 172 mm wide** at the spec's 44 mm type size (the spec says "about 155"); say if 155 matters and
  the type shrinks to 39.6 mm.

## The build, in order

The two sizes are built the same way; only the numbers differ. Drawings: `out*/drawings/earmilk-sheets.pdf`, nine
A3 sheets per size, numbered EM-FS-001 to 009 (floorstander) and EM-BS-001 to 009 (bookshelf), first-angle: (1) the
general arrangement, (2) the centre section, (3) the waveguide insert and the tweeter's mount and wiring, (4) the back,
the amplifier and the wiring, (5) the exploded view and the parts list, (6) the inner panels' details and the trim
rings' sections, (7) to (9) the notes, all 2.5 mm high: what to measure first (M1, M2, ...), what may be cut now, and
sheet 1's notes by number (1.1, 1.2, ...) on sheet 7; sheets 2 and 4 to 6's notes, the glue-up order (G1 to G7) and
the fixings (F1 to F3) on sheet 8; sheet 3's notes, fitting the tweeter and the insert, on sheet 9. Each sheet names the notes sheet its numbers point to.

0. **Buy and measure first.** Buy the drivers, the tweeters and the amplifiers (`bom.csv`) and the ply, and measure
   them before anything is cut or printed. Sheet 7's "Measure first" table lists every value the drawings assume and
   what it sets: the ply's thickness (the sides and inner panels are the plan less twice it); each driver's flange
   (the rebate is the flange + 1.0 of gasket + 3.0 of ring), frame, cut-out, hole circle and surround at its glue line
   (the trim ring's bore is that + 2); the TW29DN-B's front ring and motor (the insert's bore and the retaining cap), or the
   D3004/602200's faceplate, its hole circle and body, and whether its front is flat from ø34 to ø62 with the grille
   off; the dome and surround's diameter (the throat); the amplifier's plate, its corner radius, and its module offered
   to a test cut-out in scrap. Edit `params.py`, run `build.sh`, and check `cad.json`'s "checks" all pass.
1. **Prove the tweeter and its waveguide (a weekend).** First print the test bay (`stl/connector-test-bay.stl`), the
   gable block round the connector's bay: the boss's bore behind the pocket's back wall, the bay (ø36 x 35 for the
   floorstander, ø32 x 22 for the bookshelf) and its ø14 channel below. Hold it at the back of a box as deep as the
   pocket (200 for the floorstander, 113 for the bookshelf) and mate the Mini-Fit Jr. pair in it and release its latch by hand through the pocket, and measure the mated
   length (sheet 7, the connector's M): over the drawn 24, enter it and rebuild before the gable is printed. Print the gable (`stl/gable-print/`: six pieces for the
   floorstander, four for the bookshelf, each 120 or less on one side for a resin printer's 218 x 123 x 220, keyed by
   ø4 x 20 pins bonded with epoxy in ø4.2 holes 10.5 deep each side) and the insert (`stl/waveguide-insert.stl`) in a tough (ABS-like) SLA resin or MJF
   nylon, not standard resin and not MDF: the cap's screws and the bookshelf's knurled inserts need it. One piece from
   a print service is the default, with no seam in the waveguide. The floorstander's also comes in halves for a desktop
   printer (`-left`, `-right`, split at the centre plane and printed tilted, about 209 x 117 x 213), joined by two
   ø3 x 16 steel dowel pins epoxied in ø3.2 holes 8.5 deep each side, the seam filled and sanded flush (sheet 3). Dry-fit every
   pinned joint closed before mixing the epoxy: each hole is 0.5 deeper than half its pin, room for the epoxy. Hollow the gable's pieces to 3 mm walls
   with two ø3 drain holes each in the slicer, only in the outer slopes or the end faces, plugged with resin and filled before
   paint: none in the base, a joint face, the cable channel, the bay or the pocket, where a hole would let the woofer's box
   leak round the channel's seal. Bond every joint's full rim and seal the channel halves' seam along its length. The insert
   prints solid in MJF; in SLA solid, or hollow to 4 mm walls with two ø3 drain holes in its base face between the pins
   (sheet 9, the last of sheet 3's notes). Mount the tweeter on the insert (step 7), set the gable on a box of the
   right plan, and measure on the axis and every 15 degrees horizontally and vertically with a calibrated USB microphone
   and REW. Compare with `out*/acoustics/waveguide/*-polar.png`. If it holds, carry on; the simulation's levers are the
   throat's depth and height (`WAVEGUIDE` in `params.py`, then `bem.py`).
2. **Cut the panels.** `out*/dxf/` to a local CNC cabinet or sign shop or a makerspace ShopBot: front, back, two
   sides, top, bottom, the amplifier box's floor, lid and front; the floorstander adds the window brace and the mid
   chamber's shelf and divider. Each DXF layer names its operation (through cuts, the 3 mm shadow-line and rebate
   pockets, the drivers' and amplifier's rebates, the lid's gland holes and the counterbores for their nuts, cut from
   its underside). The amplifier's cut-out has R3 inside corners: a 6 mm cutter or smaller. No instant online service
   cuts 18 mm plywood.
3. **Glue up the box** (sheet 8, G1 to G7; G1 to G4 on the bookshelf), the front last, so every inner panel slides in
   from the open front. Lay the back face down and glue both sides and the bottom to it; then the amplifier's box, its
   lid's gland nuts epoxied into their counterbores first (20 AF or less), its floor, front and lid between the sides,
   the joints sealed; the floorstander's window brace at z 500; its mid chamber's shelf and divider to marks on the
   sides (the shelf's underside 554 above the bottom panel, the divider's front face 90 behind the sides' front
   edges), the chamber lined with 10 mm felt; the top panel, slid in from the front; and last the front, its M4 T-nuts
   pressed into its inside face first (flanges 12 or less across, or DIN 1624's 15 ground flat 6.0 from the centre on
   the side facing the cut-out; barrels 8, 6 and 7 or less for the floorstander's woofer and mid and the bookshelf's woofer). Titebond II or III, a clamp across the sides at every step
   and front to back at the last; check the diagonals. Cut the shadow lines across the front and back panels' edges
   at the side corners and round the four vertical corners (6 mm on the floorstander, 4 on the bookshelf).
4. **Make the gable.** Printed (step 1's pieces), filled and painted, or laminated birch (`dxf/gable-layer-*.dxf`)
   milled to `step/gable-block.step`. The insert's pocket is a prism along the depth and mills from the front with the
   block on its back, but its back wall is 200 deep and the connector bay 250: a 3-axis router needs that much reach
   (a long-series cutter or a 5-axis machine), or print the block. The pocket's profile corners may be R3; where its
   back wall meets the walls, sharp (a flat-ended cutter), as the insert's back edges are. Round the hips and the fin's edges. Before it goes
   on, sand the front panel's top edge flush with the top panel to within 0.1: the insert sits on both. Fix it on four
   10 x 28 mm dowels (holes 10 deep in the top panel, 20 in the block): a birch block with wood glue, a printed one
   with epoxy (3M DP420) on its scuffed base and the dowels, as wood glue does not hold cured resin.
5. **Finish, before anything is fitted.** Fill the grain and edges, 2K high-build primer, block flat, the body colour
   everywhere, mask the marks with the vinyl stencils (`out*/marks/`), the accent colour on the plinth and gable, peel;
   then the Nutrition Facts (`marks/facts-print.pdf`, on the back of the floorstander and the right side of the
   bookshelf) as a screen print in a 2K ink or a water-slide decal, and 2K clear over everything, flatted until the
   print's edge disappears. The insert is painted with the gable but on its face only: mask its sides, base and back,
   its seat, its magnet and pin holes, the pocket's walls and its floor, so the fit (the pocket +0.2/0, the insert
   0/-0.15) survives the paint. The trim rings satin black. Let the clear cure before step 6.
6. **Run the tweeter's cabinet lead** (sheets 3 and 4): round-sheathed 2 x 1.0 mm2, fed down the channel from the
   connector bay through the empty pocket and caught through the woofer's cut-out (it cannot be pushed up from inside),
   through the brace's window (floorstander, 30 mm in from its back edge) to its own gland in the amplifier box's lid.
   Its socket stands on the bay's floor: a Molex Mini-Fit Jr. two-circuit receptacle (39-01-2020, female terminals
   39-00-0077), the lead's end 77 mm above the top panel's underside (40 on the bookshelf), 10 past the floor. Seal the
   channel round the cable with 20 mm of neutral-cure silicone pushed in from the bay.
7. **Mount the tweeter and fit the insert** (sheet 3). Solder the tweeter's own lead to its tabs, 320 mm (220 on the
   bookshelf) of 2 x 0.75 mm2 silicone-insulated flex, twisted, with the connector's plug crimped on its end (39-01-2021,
   male terminals 39-00-0041), pin 1 red +. The
   floorstander's tweeter goes in from behind through its bore, its front ring on a 0.5 mm gasket on the throat's
   seat, held by the printed retaining cap bearing on its motor's back (`stl/tweeter-retainer.stl`) and three 3.0 x 12 thread-forming pan
   heads in the boss's back face (one on the horizontal at the speaker's right, the others 120 degrees on). The
   bookshelf's tweeter screws through its faceplate's own holes into three M2.5 knurled inserts bonded in the seat,
   M2.5 x 8 button heads. The magnets in the insert's back and their partners in the pocket's back wall, epoxied,
   opposite poles out; the two pins bonded in; a ribbon loop glued at the back of the groove under the insert's front
   edge, folded back into it between times. Hold the insert just clear of its pocket, reach in and plug its lead into
   the socket in the bay, and slide it home, feeding the spare into the bay as a loop.
8. **The glands, the cables, the drivers and the fill** (sheet 4). Screw the M16 glands' bodies into their nuts in the
   lid from above, one per cable. Inside the amplifier's box cut each of Hypex's harness pairs to about 150 mm and
   butt-splice the mid's and the tweeter's to their round cables (crimped splices under heat-shrink): only round cable
   passes the glands. Leave the woofer's cable end free in the box for step 9. Feed each cable through its own gland
   and tighten it: the woofer's box must be airtight, and the insert's pocket is open to the room through its 0.3 mm
   seam. Feed each run through the loose ties on the cable-tie mounts the glue-up left (floorstander note 4.6: eight a
   speaker, the highest about 180 above the woofer's cut-out, reached through it and the brace's window; bookshelf
   note 4.5) and pull them tight; putty the mid's cable into the divider's hole. Fill the woofer chamber lightly
   (about 150 g of polyester fibre, 60 g in the bookshelf), kept a port's diameter from the port's inner end and off
   the amplifier's box. The drivers on 1.5 mm foam gaskets in their rebates, M4 x 20 low-profile button heads (1.6
   high and 8 across or less) into the T-nuts, the trim rings over them on three dots of silicone (the floorstander's
   woofer and its ring after step 9).
9. **The port's tuning, then the amplifier** (sheet 2, note 2.5). The floorstander's port is tuned in the sealed box,
   with every other hole closed. Its tube (printed 10 mm long) is pushed in from the back dry, and its flare collar is
   slipped on from inside through the woofer's cut-out. Then the woofer goes in. Close the amplifier's cut-out with a
   scrap 360 x 135 board on the EPDM, and clip a DATS V3 (or a sound-card impedance jig) to the woofer cable's free end
   inside the amplifier's box, its leads out through a ø4 hole in the scrap sealed with putty. The minimum between the
   two impedance peaks is the port's tuning. To trim, take the woofer out (its 8 screws), the collar off and the tube
   out of the back, cut 2 mm off the tube's inner end, and refit, until that minimum sits at 32 Hz; then bond the
   collar on with epoxy, glue the flange to the finish, and fit the woofer and its ring for good. **The amplifier**:
   butt-splice its CH1 pair to the woofer's cable; its module goes through the back's cut-out into its sealed box, the
   plate on 3 mm EPDM tape flush in its 4.5 mm rebate; drill its holes ø3.5 through the 13.5 left under the rebate,
   from the plate in hand, and fix it with 4.3 x 16 self-tapping pan heads (8 or 10, to suit the plate; Hypex's
   4.3 x 25 kit also works).
10. **Metal.** The letters (each size's own `out*/metal/wordmark-letters.dxf`, polished stainless or aluminium,
    1.5 mm for the floorstander and 1.2 mm for the bookshelf; four sets of eight pieces a pair) glued on with epoxy
    from the size's own 1:1 templates (`out*/metal/wordmark-template-*.pdf`).
11. **Tune it** (`out*/dsp/*.md`). Load the channels and crossovers into Hypex Filter Design over USB (a USB mini-B
    cable, not supplied), then measure each driver on the tweeter's axis at 1 m (REW, a UMIK-1), set levels and delays
    from the measurements, check the reverse null at each crossover, and EQ the sum flat on axis. The files' numbers
    are where to start.

## Files and who gets them

| File (in `out/` and `out-bookshelf/`) | What | Goes to |
|---|---|---|
| `step/earmilk-*.step` | the whole speaker, every part in place | anyone, any CAD program |
| `dxf/*.dxf`, `dxf/sheet-*.dxf`, `dxf/sheets.svg` | flat panels, one per file, layers by operation; nested sheets | CNC shop or makerspace |
| `cutlist.csv` | every panel, size and operation for a pair | the shop, and you |
| `step/gable-block.step`, `dxf/gable-layer-*.dxf` | the gable: the milled block and its glue-up layers | CNC millwork or pattern shop |
| `stl/gable-print/` | the gable for printing | a printer |
| `stl/waveguide-insert*.stl`, `step/waveguide-insert.step` | the insert with the waveguide, the tweeter's bore, magnet and pin holes (the floorstander's halves too) | an SLA (tough resin) or MJF service |
| `stl/tweeter-retainer.stl`, `stl/trim-ring-*.stl` | the floorstander's tweeter retaining cap; the drivers' trim rings | a print service; a printer (the woofer's ring needs a 320 bed) |
| `stl/port-*.stl`, `step/port-tube.step` | the floorstander's port, two pieces | a printer |
| `drawings/earmilk-sheets.pdf` | the nine A3 sheets, from the same solids | the builder |
| `acoustics/waveguide/` | the waveguide study: candidates, polar maps, the choice | you |
| `dsp/*.md`, `dsp/*.json` | the DSP's starting setup: channels, crossovers, delays, levels, EQ | you, at Hypex Filter Design |
| `acoustics.json`, `acoustics/` | the box: volumes, port, simulated response | you |
| `marks/facts-print.pdf`, `marks/stencil-*.svg` | the Facts at 1:1; vinyl masks for the two marks | a screen printer or decal paper; a sign shop or Cricut |
| `metal/` | the letters and their 1:1 templates | SendCutSend, OSHCut, Xometry |
| `render/` (not in git) | the renders' model, one named part each (`render_model.py`) | the studio engine |
| `../bom.csv` | parts for a pair, both sizes, prices and sources | you |
| `../research/` | the sourcing research behind every bought part | you, before ordering |

## Proposals (not decisions)

None of these changes the outside; each is a choice someone had to make.

- **Joinery:** butt joints, plain 2D cuts any shop can make.
- **The waveguide insert:** the waveguide is a separate printed part in a pocket in the roof, so the waveguide's
  surface can be made finer than milled birch and the tweeter can be serviced: it slides out level, like a drawer,
  held by four magnets and located by two pins, with the tweeter on it and its lead unplugging at a connector in a bay
  behind it.
- **The amplifier's box:** FusionAmps are not airtight, so each module sits in its own sealed box of three 18 mm
  panels behind the plate, its leads out through a gland. In the bookshelf it also does the brace's job.
- **The floorstander's mid chamber:** a shelf and a divider close a 7.6 L sealed box behind the mid.
- **The brace:** one window brace in the floorstander (z 500); none in the bookshelf (above).
- **The drivers flush:** each frame in a rebate as deep as its flange plus a 3 mm printed trim ring over its screws,
  the ring level with the finish.
- **The bookshelf's Facts on its right side,** as on a real carton, because its back holds the amplifier.

## Acoustics

**The woofers.** From the solids, the floorstander's woofer chamber holds 85.1 L of air after the inside panels, the
port and the amplifier's box; less the driver, 81.1 L net. The RSS315HF-4 vented there at 32 Hz simulates to an f3
of 28 Hz at 90.7 dB/2.83 V (Dayton quotes 90.3). The bookshelf's 9.5 L is 9.2 L net: the SB17NRX2C35-8 sealed in it
has fc 73 Hz at Qtc 0.83 and f3 63 Hz, and a Linkwitz transform in the DSP moves the corner to 45 Hz (+8.3 dB).
`acoustics.py`, results in `out*/acoustics.json`.

**The waveguides.** The tweeter's waveguide is shaped for how it spreads sound, not for its looks: a boundary-element
simulation (`bem.py`, bempp-cl) of each candidate in the roof of the whole cabinet, at frequencies from 1 to 10 kHz,
for the horizontal and vertical response and the directivity index (`wg_study.py` compares candidates; `wg_polar.py`
draws the maps). The roof's slope tips the sound upward below about 2 kHz in the floorstander and 3.5 kHz in the
bookshelf; a deeper, higher throat brings control lower, and tipping the axis down did nothing. Each size crosses
where its waveguide's directivity comes nearest the cone below it and the listening axis is within about 1 dB of the
loudest direction: 2.8 kHz in the floorstander, 2.4 kHz in the bookshelf. Details:
`out/acoustics/waveguide/README.md` and `out-bookshelf/acoustics/waveguide/README.md`.

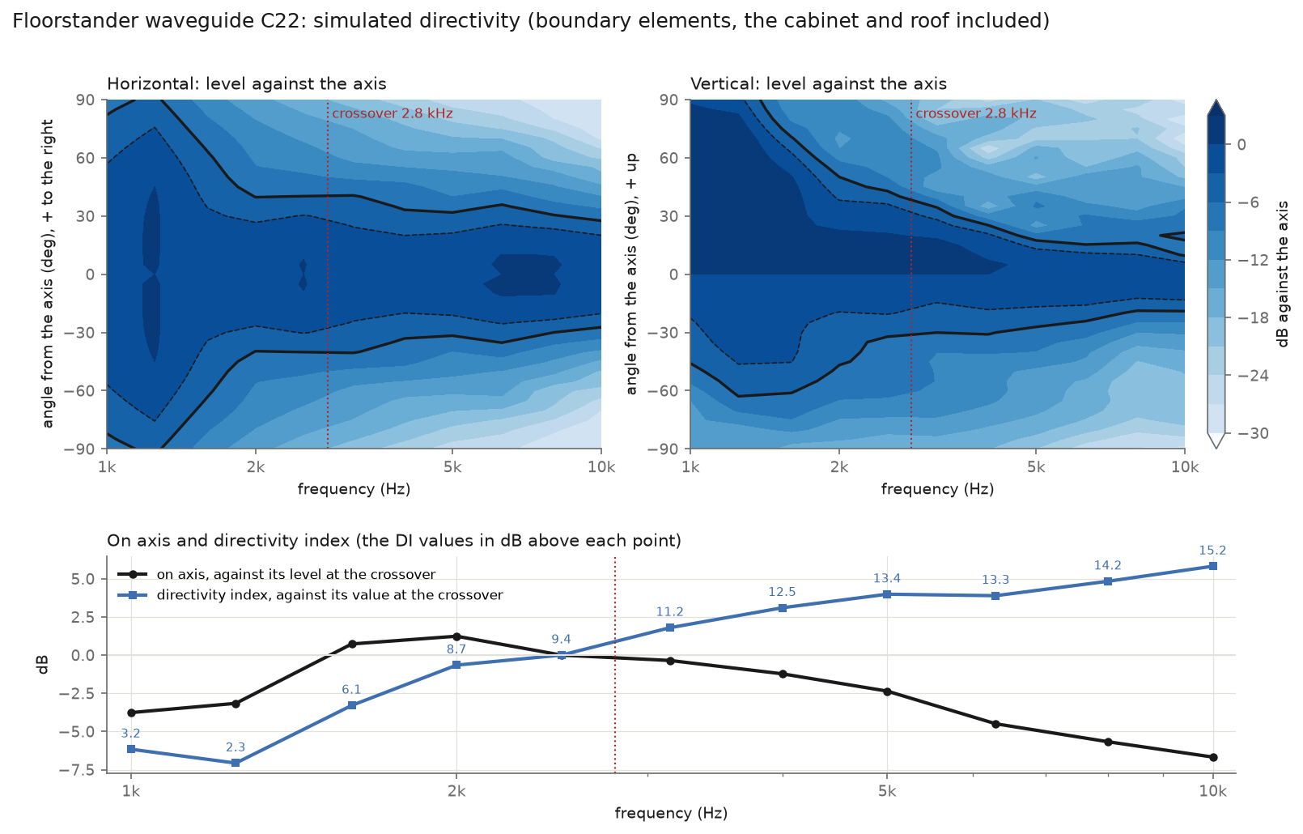
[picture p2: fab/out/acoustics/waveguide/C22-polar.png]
Floorstander waveguide

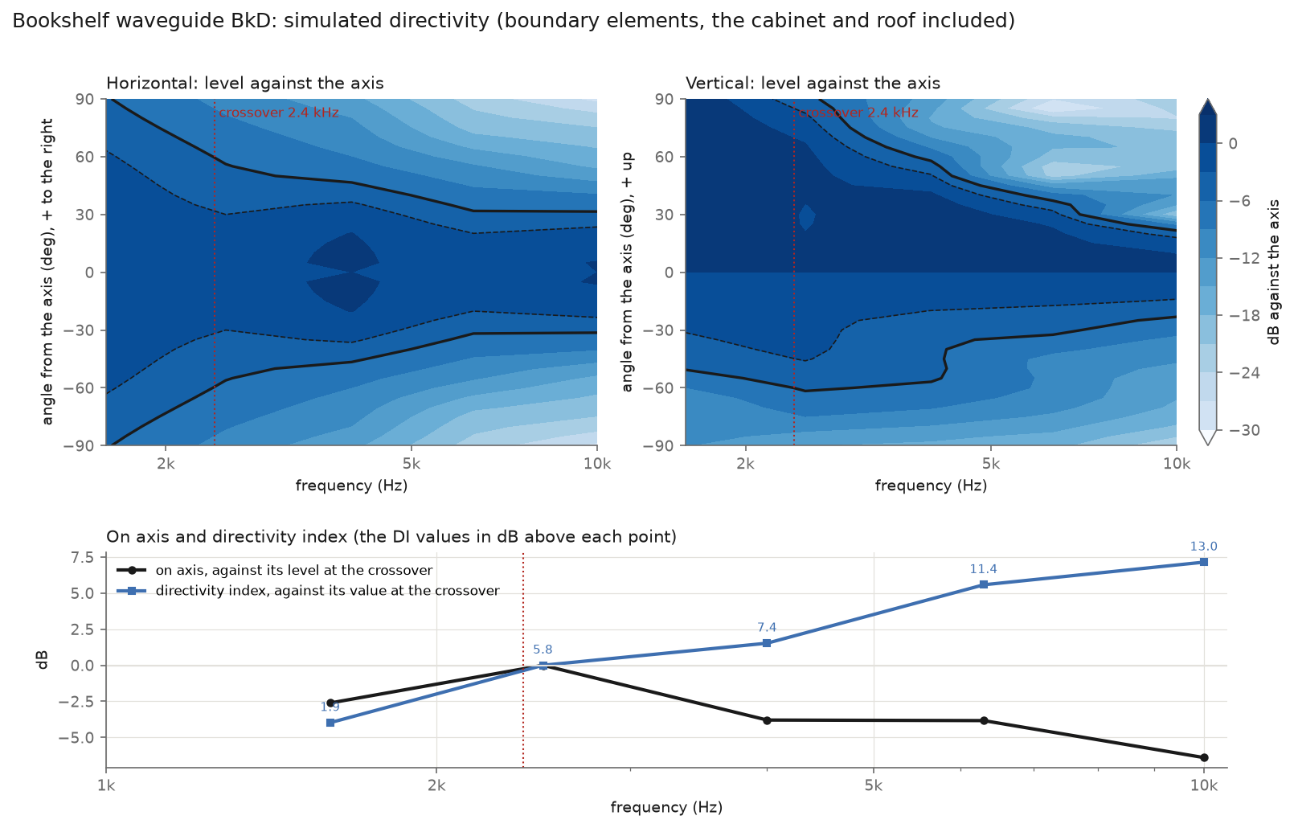
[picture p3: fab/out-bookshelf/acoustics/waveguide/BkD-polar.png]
Bookshelf waveguide


The simulation treats the tweeter as a flat piston across its dome and surround, which beams more than a dome does;
the on-axis fall above the crossover (about 7 dB to 10 kHz in the floorstander) is mostly that, and the DSP's shelf
takes out what the measurement shows. The TW29DN-B's 96.5 dB against the mid's 88 dB leaves 8.5 dB for it.

The insert's CAD is a ruled loft through the wall's meridians. Below the axis the coverage is narrowed so that every
wall meets the roof above the eave, which puts a crease in the wall (at 205 and 335 degrees in the floorstander, 199 and 341 in the bookshelf) and makes
neighbouring walls very different in length where the sides turn into the floor. A meridian lies on each crease and
more are added wherever neighbours differ by over 2 mm (`Waveguide.phis`: 256 in the floorstander, 160 in the
bookshelf); with 96 evenly spaced, the quads between
them twisted into a sawtooth along both creases, small on a print and plain in a gloss coat.

## The crossover (active, a starting point)

`dsp.py` writes each size's starting setup from the geometry and the datasheets (`out*/dsp/`):

| | Floorstander: woofer / mid / tweeter | Bookshelf: woofer / tweeter |
|---|---|---|
| crossovers | 300 Hz, 2.8 kHz, LR4 | 2.4 kHz, LR4 |
| acoustic centre behind the front | 54 / 34 / 172 mm | 32 / 91 mm |
| delay to start (as `out*/dsp/*.md`) | 0.344 / 0.404 / 0 ms | 0.171 / 0 ms |
| gain to start | -2.3 / 0 / -8.5 dB | 0 / -3.5 dB |
| woofer EQ | -3.3 dB at 37 Hz, Q 1.2 (the vented bump) | Linkwitz transform, 73 Hz Q 0.83 to 45 Hz Q 0.71 |

## Rough budget, the pair

Drivers and amplifiers: about $2,520 for the floorstanders ($1,294 of FusionAmps, $1,224 of drivers), about $1,330
for the bookshelves ($844 and $484). The rest (birch, CNC, printing, finish, metal, hardware) from the services
research: about $1,700 doing most of it yourself up to about $9,900 with everything outsourced for the floorstanders;
roughly a third of that for the bookshelves. Add the measurement kit (about $110 for a UMIK-1). `bom.csv` has the
lines.

## Regenerating

The CAD tools need numpy 2 and Blender's `bpy` needs numpy 1, so the CAD tools live in their own environment:

    python3 -m venv .venv-fab && .venv-fab/bin/pip install -r fab/requirements.txt
    fab/build.sh                      # both sizes; SIZES=bookshelf fab/build.sh for one
    EARMILK_SIZE=bookshelf .venv-fab/bin/python fab/cad.py     # any one step, for one size

`build.sh` runs, per size: `cad.py` (solids, STEP, STL, volumes, the clearance checks), `acoustics.py` (the box;
the floorstander's port settles in two passes with the CAD), `dsp.py` (the crossover's starting setup), `flats.py`
(DXF, nesting, cut list), `typeset.py` (letters, the Facts, stencils, templates), `sheets.py` (the drawings) and
`render_model.py` (the engine's model). The waveguide study is separate and slow (minutes per frequency):
`bem.py --throat Y Z --r0 R ...`, then `wg_study.py` and `wg_polar.py`.

## Checks the files pass

Every build checks, on the solids: the insert above the top panel and with material under the tweeter's bore, its
boss and fixings inside its own outline (so it slides into its pocket), 2 mm or more of insert over the bore and 3 of
gable over the pocket's bore, birch over the connector bay, the cap's screw heads clear of the bore's floor and its
pilots off the insert's split, the drivers' rebates clear of each other and of the shadow lines, the birch under each rebate 0.5 longer than its T-nuts' barrels, the tweeter's lead long enough to reach its socket with the insert held clear, the insert's pins clear of its magnets, the amplifier's plate
clear of the plinth's shadow line and inside the back, the glands 5 or more apart and inside the lid, the port clear
of the amplifier's box, the box clear of the brace (`cad.json`, "checks"; a failure stops the build).

The floorstander: overall 1,055; ridge 1,010; body 860; slope 246 at 37.6 degrees; fin 45 x 8; plinth 110 with the
groove at 110 to 113 and the gable's at 857 to 860; corners and hips R6, the fin R3; woofer at z 320, mid at 690;
the waveguide's mouth 279 wide, the insert 283; the Facts 266 x 260, top at z 770; port 100 at z 405; the FA253's
plate 360 x 135 at z 185. The bookshelf: overall 594, body 484, plinth 62, R4 and R2, the woofer at z 380, the mouth
156 wide and the insert 159, the Facts 150 x 147 on the right side, the FA122's plate 120 x 315 at z 235. All from
`params.py`, which follows `spec/geometry.md`; where they disagree, the spec wins, with two exceptions the owner's
later decisions made: the build is active, so the Hypex plate takes the back's foot where the spec's passive terminal
cup sat (z 175; `POSTS` and `TERMINAL_CUP` in `params.py` are kept for a passive build), and the tweeter's throat is at
y 176, z 935 from the waveguide study, not the spec's 125. Both are listed for the owner to confirm in the spec.

**Questions for the owner** (the drawing checks', rounds 2 to 8). Open: Hypex's manual (R4) allows the FA253 mounted
horizontal, tilted up to 45 degrees, in its own compartment (the module is not airtight): is a 90 mm sealed box enough for
its heat (the manual asks only that convection is not impeded; Hypex's FAQ mentions venting holes)? Is 1.5 mm
of insert under the bookshelf tweeter's bore strong enough, or should its throat rise 2.2 mm? Is the milled gable meant
for a shop with the reach, or is the printed one the default (the sheets assume either)? If the D3004/602200's body
measures over 48.3 mm (its hole circle less 5.7; the research allows 50), its faceplate's M2.5 heads no longer clear it: a printed
clamp like the floorstander's retaining cap (its boss wall thicker than 3 mm), or the faceplate bonded to the seat? SB's drawing gives the
SB17NRX2C35-8's flange as 6.5 (the 10.9 a shop lists is all that stands in front of the baffle), so the bookshelf's
10.5 rebate stands: confirm it on the part. A shop lists the D3004/602200 45.3 deep: if its body behind the faceplate is
over the 26 the bookshelf's bore holds, the roof leaves about 1.3 mm to move the boss back: lower the throat from z 517,
or choose a shorter tweeter (the Seas 27TFFNC/G, about 22 deep in the research)? Are feet, glides or spikes wanted (none
is drawn: the 2K-painted plinth's edges carry the speaker)? May each amplifier's sealed box be tested with an hour at
full power before the back goes on, since Hypex asks only that convection is not impeded? The floorstander's tweeter is now drawn from SB's drawing, one ø70.0 body 21.7 behind its 5.0 faceplate, in a ø70.4 bore that centres it, held by a printed cap on its back (18 long; the cap's screws have 3.0 of wall). SB's procedure lifts the faceplate slowly because glue at the diaphragm's rim can stick to it: if the rim is not held without the faceplate, may the unit take SB's adapter ring (it comes with the WG29-187) or a printed one on the faceplate's own screws, the bore and the boss growing to its outside diameter? Hypex's manual asks for the amplifier's compartment to be built of V-1 class material, with conductive parts earthed and 3 mm clear: line each birch box (a bonded aluminium sheet tied to the plate's earth, or a V-0 sheet), or is ply acceptable for a one-off? Is the milled gable (route A, which needs about 255 mm of reach along the depth) still wanted, or is the printed gable the build (its 22 and 14 layers would leave the nests)? The woofer's trim ring, its bore the surround + 2 (ø290), shows 1.5 mm of each of its eight screw heads (they reach in to ø287): black heads, or a ring bore of ø285 if the surround allows? Can the Mini-Fit Jr. pair be mated, and its latch released, by a hand reaching about 240 mm (the bookshelf 150) into the pocket, with 12 mm (8) above the mated pair in the bay? research/ holds no Molex drawing: a printed test bay before the gable is made would show it. The floorstander's port ends 60 to 70 mm from the woofer's motor, less than its 92 mm bore, with its axis at the motor's top edge: acceptable, or should the port fold or the tube shorten with a larger flare? A printed gable's pocket crosses bonded joints and a 195 mm resin piece can warp more than the pocket's +0.2: give the printed pocket 0.4 a side? Which T-nuts and screws (F1 gives limits: the mid's flange 12 or less, barrel 6 or less, the heads 1.6 high; a 15 mm flange on the mid's circle overhangs its cut-out)? Taken as proposals, for the owner to confirm: the bookshelf insert's outline rises about 3 mm at the
top so it covers the boss behind it (the waveguide is unchanged; its seam on the roof moves about 4 mm up the slope);
the insert is printed in a tough resin or MJF nylon, one piece from a service, the floorstander's halves only as a
fallback; the cabinet's tweeter lead ends at a socket standing on the bay's floor and the tweeter's own flexible lead,
320 mm (220 on the bookshelf), reaches it with the insert held clear of its pocket, its spare looped into the bay; the
bookshelf's bay grows from ø26 to ø32 for the connector; the insert comes out by a ribbon loop against its magnets
that folds back into its groove between times; the bookshelf's letters are 1.2 mm, the floorstander's 1.5; the gable's layers follow the measured ply (one more under 17.73 mm); the tweeter's cap is 0.25 longer than its gap, so its screws press the gasket; the insert's unpainted body is the resin's own colour (grey as rendered; a black or white resin would read as finished in an exploded view).

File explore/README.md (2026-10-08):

# Explorations

Not shots. Each folder is one design question, rendered with the same model as the shots so proportions stay exact. Nothing here changes the spec until a choice is made; the chosen option then goes to the canvas, `spec/`, `copy/` and the shot briefs together.

    cd render && node render.mjs --list explore --scale 2

## 2026-10-01: more colour on the carton, and the owner's side panel

Question raised after the v3 renders: the cartons read as mostly white, and the side could carry something people choose themselves, in the manner of the old "Have you seen me?" milk-carton panels.

Colour, one lineup each, flavour order left to right:

| File | Look | What it touches in the spec |
|---|---|---|
| `color-wordmark-as-spec.png` | As specified today: wordmark front and side, colour only in the throat. | Nothing. |
| `color-cap.png` | The lid (gable and fin) in the flavour's print colour. | Reopens the Decision "gable and fin are the same colour as the body". |
| `color-band.png` | A 110 mm band of print colour around the base. | The print line in Colorways. |
| `color-rings.png` | Print-colour rings around the woofer and the mid. | The print line in Colorways. |
| `color-side.png` | Both side panels in the print colour, wordmark reversed in the board colour. | The print line in Colorways. |

The side panel, with the lid in colour:

| File | What |
|---|---|
| `decal-side.png` | Whole, from the front-right: "HAVE YOU HEARD ME?", a halftone portrait placeholder, four rows the owner fills in. 300 x 330 mm below the side wordmark. |
| `decal-side-chocolate.png` | The same panel in Chocolate's cream ink. |
| `decal-pair.png` | The hero pair, each with a different panel, to show that the panel is chosen per speaker. |

Panel copy in these renders is placeholder, not approved: the headline is the one proposed; the rows are Name, Heard since, Last heard, If heard call; the footer line is a mock. The portrait is a generated halftone silhouette, not a photo of anyone.

## 2026-10-01, round 2: lids on the white cartons, the band as print or as a stand, wordmark in the band

Direction after round 1: coloured lids, but the darker cartons stay solid; the base band either as a default or as an optional stand; no rings; coloured sides dropped; the wordmark could move into the band; and a question about where physical controls would live.

    cd render && node render.mjs --list explore2 --scale 2

| File | What | What it touches in the spec |
|---|---|---|
| `r2-lineup-lids-white-only.png` | Lid in the print colour on Whole, 2% and Skim; Chocolate and Oat solid as today. | Reopens "gable and fin are the same colour as the body" for the three white flavours only. |
| `r2-lineup-band-logo.png` | Lids as above, a printed 110 mm base band in the print colour, the wordmark reversed in the board colour inside the band on the front and the right side, nothing printed under the gable. | The print line in Colorways, and the as-drawn wordmark placement in `spec/geometry.md`. |
| `r2-lineup-stand-logo.png` | Lids as above, no printed band; instead a separate 110 mm painted stand in the print colour with a 6 mm dark reveal under the carton, the wordmark on the stand. | Adds an object the handoff does not have. Overall height with the stand 1,171 mm; the tweeter axis rises to about 1,020 mm. |
| `r2-band-close.png`, `r2-chocolate-band-close.png` | The printed band close, on Whole and on Chocolate (cream band, brown wordmark). | As above. |
| `r2-stand-close.png` | The stand close: the reveal is what makes it read as a separate block. | As above. |
| `r2-pair-band-panels.png` | The hero pair with lids, printed band and the owner's panel on each. | As above, plus the panel. |
| `r2-whatif-knob-on-stand.png` | A what-if only: one knob on the stand's front. The floorstander is passive by Decision and has no controls; if it ever went active, the stand is where they would live. | Not proposed. |

## 2026-10-02, round 3: milk-carton marks that are not about the owner

Direction: no sleeve, the colour a finish on the birch, the band and the stand one built-in plinth, the wordmark a badge on the front and an engraving on the back, the owner's panel dropped. Asked for: other common milk-themed marks, as long as they are not about the owner. These are proposals, not spec; none of them is on the model by default.

    cd render && node render.mjs --list explore3 --scale 2

| File | What | Where it would live |
|---|---|---|
| `r3-open-other-side.png` | OPEN OTHER SIDE with the arrow, the line every gable-top carries on the slope that is not the spout. Here it points at the bowl. In the gable's other colour (white on Whole's red). | The back slope of the gable. Seen from behind and above, so a room shot would only catch it on the far speaker. |
| `r3-best-before.png` | BEST BEFORE  NEVER as an inkjet date stamp, dot matrix, black. | The front face of the fin, where the date goes on a carton. |
| `r3-grade-a.png` | A stamped roundel: GRADE A over PASTEURIZED · HOMOGENIZED, a big A in the middle, in the accent colour. | The right side, upper third, 130 mm across. The only one of these that puts anything on a side. |
| `r3-shake-well.png` | SHAKE WELL in caps, in the accent colour. | The right side, near the top. |
| `r3-volume.png` | 103 L (27 GAL), the cabinet's gross internal volume from `render/src/check-spec.mjs`, set small under the badge the way the net-contents line sits at the foot of a carton. | The plinth's front, under the badge. |
| `r3-all.png` | OPEN OTHER SIDE, the date stamp, the roundel and the volume line together, from high and to the right, to see how much is too much. | As above. |

Not rendered on purpose: anything with a name, a face, a date the owner fills in, or a phone number.

## 2026-10-02, round 4: the shape of the bare birch field on the back

Asked: must the birch fill the whole back, or only hold the Nutrition Facts, with the port, the posts and the wordmark outside it? Both, straight on and from the rear quarter. The contained field is the default from v9; the full field stays an option with its bottom lifted so the margin above the plinth matches the sides.

    cd render && node render.mjs --list explore4 --scale 2

| File | What |
|---|---|
| `r4-back-label-straight.png`, `r4-back-label-quarter.png` | The field is the Facts panel plus a 26 mm margin; the wordmark engraved on the finish above it, the port and the posts on the finish below. |
| `r4-back-full-straight.png`, `r4-back-full-quarter.png` | The field from 140 above the floor to 30 below the top, 26 in from the sides; everything inside it. |

## 2026-10-02, round 5: the back as decided, and three more marks

OPEN OTHER SIDE (back slope) and SHAKE WELL (first by the port, then moved onto the plinth's back) are spec now; the Facts are an engraved bronze plate; the back wordmark is cast letters like the front. The first two frames show that. The rest were proposals, none about the owner; all three were dropped the same day.

    cd render && node render.mjs --list explore5 --scale 2

| File | What | Where it would live |
|---|---|---|
| `r5-back-quarter.png`, `r5-back-close.png` | The back as decided: bronze plate, cast letters, SHAKE WELL under the port, OPEN OTHER SIDE on the slope. | Spec. |
| `r5-keep-room-temperature.png` | KEEP AT ROOM TEMPERATURE, the storage line, true of a speaker. | Right side, under the gable, accent colour. |
| `r5-return-for-deposit.png` | RETURN FOR DEPOSIT, small, reversed in the body colour. | The plinth's right side. |
| `r5-barcode.png` | A barcode whose digits are the spec's own numbers (390, 860, 1055, 103). | Right side, low, where a carton carries it. |
| `r5-all-new.png` | The three together with the two spec marks. | As above. |

## 2026-10-03: the hand-made photoreal attempts, and why the pass moved to a path tracer

Two chat image models were given the v11 hero frame and asked to change only light and materials. Both repainted the object instead: the proportions drifted (one pair squatter, one gable wider and taller), the cast letters came back as another word in caps in one and as mush in the other, and one swapped the black cones for tan paper. Kept here as the record of why editing models cannot carry this brief.

| File | What |
|---|---|
| `handmade-gemini-hero.jpg` | Gemini, by hand, from the v11 hero frame. |
| `handmade-chatgpt-hero.png` | ChatGPT, by hand, from the same frame. |

The photoreal pass is now `render/pathtrace.py`: the same model, exported to glTF and rendered in Blender's Cycles, so nothing drifts.

## 2026-10-07, round 6: the scoop's trim

The owner is not sure of the metal round the tweeter ("it looks like a diner"). Since 2026-10-06 the spec has a polished stainless lip on the scoop's mouth, and the renders give the tweeter a bright chamfer and a satin metal seat. Four options, each in the close-up's frame and nearer in the bright room. Proposals until the owner picks one.

    cd render && node render.mjs --list explore6 --glb render/out/glb
    python3 render/pathtrace.py --glb render/out/glb/r6-trim-tone-close-v1.glb --out explore/2026-10-07/r6-trim-tone-close-pt.png --samples 64 --bevel 6

| Files | What |
|---|---|
| `r6-trim-polished-*-pt.png` | As spec now: the polished stainless lip, the tweeter's bright chamfer and satin metal seat. |
| `r6-trim-black-*-pt.png` | The lip as spec; the tweeter's chamfer and seat moulded black, so the tweeter itself has no bright ring. |
| `r6-trim-tone-*-pt.png` | The lip in the gable's own lacquer, a rolled edge in the carton's colour; the tweeter's ring black. No bright metal at the scoop. |
| `r6-trim-none-*-pt.png` | No lip, as before 2026-10-06 (the critics read the bare cut as a hole); the tweeter's ring black. |

The close-ups are 1800 × 1200 at 64 samples, the nearer views 900 × 600: comparisons, not finals.

**Chosen 2026-10-07 by the owner: 4, no lip,** with the tweeter's ring black. It is spec now (README, Amendments 2026-10-07); the other three stay here as the record.

## 2026-10-07, round 7: where OPEN OTHER SIDE goes

The owner: "I think the open other side should be on the top fold rather than the angle, but I could be wrong." The round-2 three-quarter back, with the line on the back slope (`r7-open-slope-pt.png`, as spec until then) and on the fin's back face (`r7-open-fin-pt.png`), both with the back's letters centred between the edge and the Facts. **Chosen by the owner: the fin.**

    cd render && node render.mjs --list explore7 --glb render/out/glb

## 2026-10-08, round 8: the owner's changes up close

What the owner approved on 2026-10-08, close, on the batch's final model and finish: the recessed terminal cup at 175, its flange on four screws and the posts standing in it (`r8-cup-pt.png`); the woofer flush under its gunmetal trim ring, the cone ribbed charcoal paper, the cap satin (`r8-woofer-pt.png`); the tweeter forward to 125, its faceplate seated flush on the throat's flat floor (`r8-tweeter-pt.png`). A record of the spec, not options: 1800 × 1200 at 64 samples.

    cd render && node render.mjs --list explore8 --glb render/out/glb

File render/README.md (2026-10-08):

# render

One Three.js model of the carton speaker, built from `spec/geometry.md` through `src/spec.mjs`, one room and camera rig per shot brief in `prompts/`, screenshotted through headless Chromium. The same model renders every shot, so the proportions cannot drift between frames.

    cd render
    npm install
    npm run check                 # derived numbers against spec/geometry.md; fails on drift
    node render.mjs               # every shot, v1, into renders/<today>/
    node render.mjs --only 01,03 --v 2
    node render.mjs --scale 2     # supersample 2x and downscale (uses ImageMagick convert)

| File | What |
|---|---|
| `src/spec.mjs` | The numbers, in the frame `spec/geometry.md` defines. |
| `src/check-spec.mjs` | Prints the derived values and exits non-zero if any drift. |
| `src/model.mjs` | Cabinet, carved block, bowl loft, tweeter, drivers, sleeve tube and lid, print decals, back details; the pint and the crate. |
| `src/textures.mjs` | Canvas textures: wordmarks, the Nutrition Facts label (printed on the finish since 2026-10-07; engraved before), the bowl gradient, birch grain, floor planks. |
| `src/scene.mjs` | Rooms, lights and cameras. |
| `src/shots.mjs` | One entry per shot, plain data, matching `prompts/`. |
| `src/app.mjs`, `page.html` | The page that renders a shot config to a PNG data URL. |
| `render.mjs` | Node harness: static server plus playwright-core driving the preinstalled Chromium. |
| `fonts/` | Archivo and Archivo Black, SIL Open Font License. |

Rendering here runs on SwiftShader (software WebGL 2) at 1800 x 1200 in a few seconds per frame.

Assumptions the model makes beyond the spec, all also noted in `spec/geometry.md`: the sleeve board sits outside the spec dimensions, so the sleeved speaker is 393 mm wide, invisible at any shot scale; the pint's bowl is the floorstander's scaled by the plan ratio, with its throat closed, since the pint has one full-range driver and no tweeter; the pint's walls are 5 mm and its fin 2 mm.

## Photoreal pass (`photo.py`)

Sends a rendered frame to Google's Gemini image model as the layout and asks for light and materials only, writing `renders/<date>/shot-NN-vN-photo-X.png` beside it. The prompt is the shot's text-to-image paragraph under the constant block from `prompts/`. The key is read from `IMAGE_API_KEY` or the file named by `IMAGE_API_KEY_FILE`; keep it in the environment's settings, never in the repo.

    IMAGE_API_KEY=... python3 render/photo.py --shots 01,04 --variants 2 --date 2026-10-03

On a free-tier Google key the image models return "quota exceeded" (free daily limit of zero for image generation, as of 2026-10-03); the project needs pay-as-you-go billing for the call to succeed.

## Path-traced pass (`--glb` and `pathtrace.py`)

The real-time renderer hits a ceiling the critic named in every round: one light the whole frame obeys, penumbra, bounce, contact occlusion. The path-traced pass renders the same model in Blender's Cycles on the CPU, so nothing drifts.

    cd render && npm install          # three + playwright-core
    pip install bpy                   # Blender as a Python module, about 350 MB
    node render.mjs --v 11 --glb render/out/glb                    # export each frame as GLB + a sidecar with the light rig
    python3 render/pathtrace.py --glb render/out/glb/shot-01-v11.glb --out renders/2026-10-03/shot-01-v11-pt.png --samples 128

`--glb` exports the scene with its camera; fake contact-shadow decals are dropped and alpha-only decals become colour maps so glTF carries them. The sidecar lists the sun, area fills, hemisphere and point lamps, the exposure and the room's `skyGlow`; `pathtrace.py` rebuilds them in Cycles units (sun strength = the real-time intensity; area power = intensity × area × π; point power = candela × 4π; dome radiance = hemisphere ÷ π), keeps the glTF materials, and renders with denoising and the AgX view (or the shot's `view`; every frame from v25 uses Khronos PBR Neutral). `render/out/` is not committed.

What the path tracer does differently from the real-time scene, and why (round 1 of its critic, 2026-10-03):

- The rooms are closed boxes (`enclose` in `scene.mjs`), so the only daylight is the window's: the sun (at twice the real-time strength, because AgX keeps the highlights ACES clipped), the sky plane glowing outside the opening (`1.5 × sun × skyGlow`, the rig's suns being cinematic rather than solar) and the area fill inside it. Cycles bounces the rest; the dome stays outside. glTF marks the sky plane unlit and Blender's importer builds that as emission for camera rays only, mixed with transparency for every other ray, so it lit nothing until `pathtrace.py` rebuilt it as a plain emitter.
- The studio's directional lights become softboxes on the same axis (square area lamps, 2.6 m at 4.5 m for the key), its dome a vertical gradient from white overhead to the backdrop tone at the horizon, and the floor sweeps up into a backdrop (`sweep`), so lacquer and metal have something to reflect and there is no horizon seam.
- Materials named `finish*` and `bronze` get a shader-space bevel on their normals (eased arrises, silhouette unchanged): `--bevel` mm, 1.5 in the finals since the main arrises are rounded in the model (3 mm from 2026-10-07, 6 from 2026-10-08; the shader eased 6 before), times the shot's `bevelScale` (100/390 for the pints); since v23 the finish's clear coat takes the same bevel and orange peel (`--coat-normal 0` for the older look); `bronze` is rendered as a metal (the real-time renderer fakes it part-diffuse against one pale environment map); `*sky*` planes emit and cast no shadow.
- Per shot, in `shots.mjs` and so in the sidecar (2026-10-07 on): `camera.level` keeps the camera horizontal and shifts the lens to frame the look-at point, so verticals stay vertical; `glints` are edge lights, each a strip placed where one rounded edge's middle normal mirrors it into the camera, linked to the finish only, so the round draws a line of light and nothing else is lit; `look` picks the AgX look (`AgX - Medium High Contrast` by default; the studio frames use `AgX - Very High Contrast` from v23, so a white body reads white over its set); a glint with `specularOnly` is seen only in reflections, so a bright strip draws its line on a round without lifting the faces beside it.
- Per shot, 2026-10-08 on: `view` picks the view transform, and `Khronos PBR Neutral` keeps a base colour's hue up to the highlights (every AgX look turned a lit red salmon and a lit blue periwinkle; the look defaults to None under any other view); `peel` scales the finish's orange peel and `coatRoughness` sets its clear's roughness (`--peel` and `--coat-roughness` do the same for a proof); a glint with `position` is a small light at that point aimed at `at`, for a surface no mirror direction can reach, such as the far wall inside a port.
- Noise and props, 2026-10-08 on: the indirect light is clamped (`sample_clamp_indirect` 10), so a stray path through the lacquer no longer leaves white sparkles on a dark rim; the studio's edge strips are lights, hidden from the camera (one stood at the line-up's edge as a clipped white bar); the floors and desks carry a broad figure in their colour, board to board, under the grain, so planks read from across a room.
- Drivers (2026-10-08 on): materials named `cone*` get pressed concentric ribs, about a dozen from the rim to the cap, from the lathe's v coordinate, under the paper's fibre; `dustcap*` the same fibre, satin.
- Flags: `--samples`, `--scale`, `--time-limit`, `--sun-strength`, `--area-strength`, `--world-strength`, `--sky-strength`, all multipliers on the sidecar values. Full frames take about four minutes on four cores; `--scale 0.5 --samples 48` is a one-minute proof.
- Checks (2026-10-08): `--crop X0 Y0 X1 Y1` renders one part of the frame at full size (fractions from the top left), `--hide` leaves out objects by material name, `--denoise 0`, `--denoise-guides` and `--adaptive 0` take the denoiser and the adaptive sampler out of the question. The cast letters are alpha-masked planes; clear as they are outside the glyphs, the denoiser drew each as a faint rectangle on a near-black plinth, so the path tracer cuts them down to the cells their glyphs touch (`--trim-letters 0` keeps them whole).

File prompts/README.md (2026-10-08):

# Shot prompts

One file per shot, versioned: `prompts/shot-NN-vN.md`. A version is frozen once a render has been made from it. Changes go in the next version with a line at the top saying what changed and which critic round asked for it. The render a version produced is `renders/YYYY-MM-DD/shot-NN-vN.png`, same NN and vN; multi-frame shots add a letter (`shot-02-v1a.png`, `shot-02-v1b.png`). A path-traced render of the same version (see `render/README.md`) adds `-pt`: `shot-NN-vN-pt.png`.

| NN | Shot | Flavor(s) | Frames |
|---|---|---|---|
| 01 | Hero pair in a room | Whole | 1 |
| 02 | Two rooms, years apart | Whole in both: the same pair in two homes, a bright first apartment and a darker older house (rebriefed 2026-10-02) | 2 |
| 03 | Bowl close-up | Whole | 1 |
| 04 | Back, straight on | Whole | 1 |
| 05 | Five flavors lineup | all five, in order | 1 |
| 06 | Mixed crate on a desk (pints) | all five across six pints | 1 |
| 07 | Sleeve swap | Whole to Oat | 3 | retired 2026-10-02 with the sleeve; last render v5 |

Priority is the NN order.

## The constant block

Every prompt includes this unchanged. It is the part that must not drift. If the render path is the 3D model, the model is the constant block and a prompt file carries only camera, light, scene and the acceptance list.

> A floorstanding speaker that is exactly a half-gallon gable-top milk carton scaled up: square plan 390 mm, body 860 mm tall, a gable rising 150 mm to a centred ridge, a 45 mm fin on top, 1,055 mm overall. Two black paper-cone drivers on the front, a 12 in woofer low and a 6.5 in mid above it. On the front slope of the gable, an elliptical opening into a smooth, concave, painted bowl; a 1 in dome tweeter sits at the bowl's throat, 170 mm back, facing forward. The outer skin is matte printed carton board with visible fold creases at the gable and the fin. The only print is the lowercase wordmark "earmilk", on the front above the mid and larger on the side. No grille, no glossy plastic, no flavor word, no label on the sleeve. Birch shows only through the window on the back.

*Amended 2026-10-02 (v6 on): the skin is not board. The cabinet is birch finished in the flavour's colours, satin: the body in the board colour, the gable and fin in the accent colour on Whole, 2% and Skim, one colour all over on Chocolate and Oat, and the bottom 110 mm a built-in plinth in the accent colour with a fine shadow line above it. No creases, no folds, no print. The only wordmark is a cast metal badge with raised lettering, centred on the plinth's front, and an engraving on the bare birch back panel above the Nutrition Facts. Bare birch shows only on that back panel.* *Later the same day: the Facts are an engraved bronze plate on the finish, the back wordmark is the same cast letters as the front, and two printed marks are spec: OPEN OTHER SIDE with its arrow on the back slope, SHAKE WELL under the port. Bare birch shows nowhere on the product.* *2026-10-07: no plate; the Nutrition Facts are printed on the back's finish, black on the white flavours, like a carton's panel. No lip at the scoop and no bright metal there (the tweeter's ring black); the corners and the gable's hips rounded 3 mm; a 3 mm shadow line under the gable, like the plinth's; OPEN OTHER SIDE on the fin's back face, not the slope; the back's letters centred between the body's top edge and the Facts.*

Proportions come from `spec/geometry.md`, colors from `spec/colorways.json`, copy from `copy/`.

## What a render must not do

- Change the carton's proportions, soften its edges, taper it, or otherwise "improve" the silhouette. *2026-10-07 (the owner): the body's vertical corners and the gable's hips are rounded 3 mm and the fin's edges 1.5 mm, in the spec; nothing else is softened.*
- Add a grille, glossy plastic, a cap, tuning plates, or a second tweeter.
- Angle the tweeter up, square the bowl, or sink it vertically.
- Show bare birch anywhere but the back window and the exploded or section views (shot 07 is the exploded view). *2026-10-02: the back panel and the section views; there is no exploded view.*
- Put a flavor word under the wordmark, or a label on the sleeve.
- *2026-10-02:* put the wordmark anywhere but the badge and the back engraving, print anything on the cabinet, or show the colour as a wrap with a cut edge. *2026-10-07: the printed marks are the two above and the Nutrition Facts on the back; nothing else.*

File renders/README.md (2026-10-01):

# Renders

`renders/YYYY-MM-DD/shot-NN-vN.png`, where NN and vN match the prompt file that produced it (`prompts/shot-NN-vN.md`). Multi-frame shots add a letter: `shot-02-v1a.png`, `shot-02-v1b.png`, `shot-07-v1c.png`.

Keep every file under about 5 MB. Commit a render together with its prompt version and its row in `critic/LOG.md`.

Nothing here yet.

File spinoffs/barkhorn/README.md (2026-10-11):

# barkhorn (a working name): Friendly Pressure's horn speaker, in bark

The owner's idea of 2026-10-10 was speakers that look like their reference photograph of Friendly Pressure's horns
(`reference/friendly-pressure-owner-2026-10-10.jpg`, with two more of the same speakers in a bar and a studio beside
it). There are two finishes, birch bark and eucalyptus bark, each with a horn in its bark's colours.

Status: **concept, round 2**. The proportions follow the photograph. The sizes are scaled from its turntable (about
450 wide).

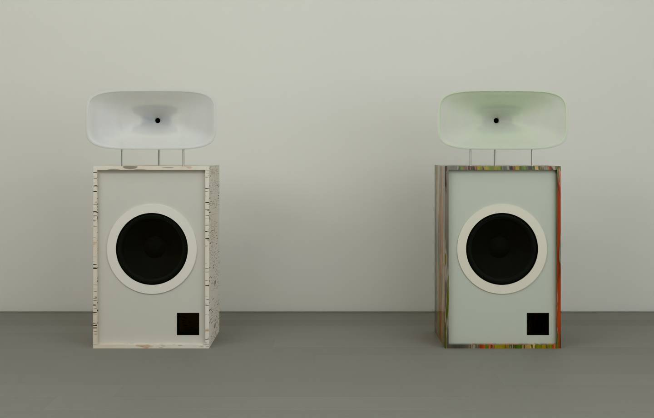
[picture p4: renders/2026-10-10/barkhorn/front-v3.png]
The two barks, front


## Round 2: the owner's notes of 2026-10-10

| the note | what changed |
|---|---|
| "It's interesting that you made the waveguides so thick. I kind of like that less of the innards are exposed that way potentially, but it does make it look less sleek and more pudgy." | The waveguide is now a **thin cast shell**. It is 6 mm thick and follows the flare outside as well as in, with a 10 mm rim at the mouth. Behind the throat, a round **pod** 148 across closes round the compression driver, and a cap closes the pod. Nothing inside shows, and the horn reads as one sheet bent into shape (`../../renders/2026-10-10/barkhorn/back-v3.png`). It uses about 1.5 L of resin. It stands on three rods (two under the mouth, one under the pod), each cut to meet the shell's underside. |
| "The eucalyptus looks too pastel and not like the long strips of peely camo-ish bark. Like a eucalyptus after rain." | The bark is redrawn as a smooth-barked gum sheds it, in **layers**. The fresh underbark is streaked deep green, olive, yellow and orange. Over it lie older layers in long vertical strips: straw, rust, grey, then brown. Each strip's edge lifts, with a dark shadow under it and a lit, curled lip. Everything is **wet**: deeper and more saturated, glossy, with rain-darkened runs (`../../renders/2026-10-10/barkhorn/eucalyptus-detail-v3.png`). |
| "Open to ideas on front panel covers" | **Five covers**, each built in the CAD with its own cut files and parts list, and rendered on both barks (below). |

## What the photograph shows, and how it is built here

| in the photograph | here |
|---|---|
| a bass cabinet about 1 : 1.6 | 560 wide, 880 tall, 420 deep, standing on felt glides |
| a thin walnut shell framing a pale front panel set back in it | The shell (sides, top, bottom, back) is 18 mm birch plywood faced in **bark**, wrapped round its front edges. The front panel is set back 24 mm and painted pale. 24 mm is deep enough for a cover to clear the cone. |
| a 15 in black cone in a wide off-white ring, its centre a little above the middle | FaitalPRO 15PR400-8 (treated paper cone, 99 dB), flush in its rebate, its centre 45.7 % down. A 6 mm MDF ring 436 across lies over its frame, with pockets behind for the screw heads. |
| a small square port at the bottom right | A 100 mm square printed port, bottom right, 53 long. The box is about 152 L net, tuned to 38 Hz; f3 is about 44 Hz in half space before room gain (`.venv-fab/bin/python spinoffs/barkhorn/product.py`). |
| a frosted, translucent rounded-rectangle waveguide, wider than the cabinet, the throat a dark dot at its centre | The waveguide's mouth is 612 x 272, filling its face (633 x 292 overall). Its flare is 170 deep, with the pod 70 behind it. It is a superellipse waveguide: round at the 1 in throat, squaring toward the mouth, covering about 120 x 75 degrees. It is cast in tinted translucent polyurethane and bead-blasted to frost. |
| it floats on thin rods | three 10 mm stainless rods, about 80 clear between the cabinet and the mouth's rim, M8 into inserts in the top and pads cast inside the shell |
| (not visible) | A BMS 4550-16 compression driver (polyester diaphragm, 113 dB) sits in the pod. A Hypex FusionAmp FA122 on the cabinet's back crosses at about 800 Hz and pads the HF channel about 14 dB. Part of the pad is a passive L-pad after the amplifier, so its hiss stays inaudible. |

## The two finishes (proposals)

| | shell | front panel | ring | waveguide |
|---|---|---|---|---|
| birch | paper birch: chalk white, dark lenticels in bands, a few scars, apricot where it has peeled | pale warm grey `#D8D5CD`, as photographed | off-white `#EEEAE2` | milk-white frosted resin `#F5F2EC`, warming to `#EFE5D3` where it is thick, as sap |
| eucalyptus | a smooth-barked gum after rain: underbark streaked green, olive, yellow and orange under strips of straw, rust, grey and brown, wet | pale sage grey `#CBCFC4` | cream `#E8E2D4` | sage frosted resin `#DEE6D4`, deepening to leaf green `#B9C9A9` |

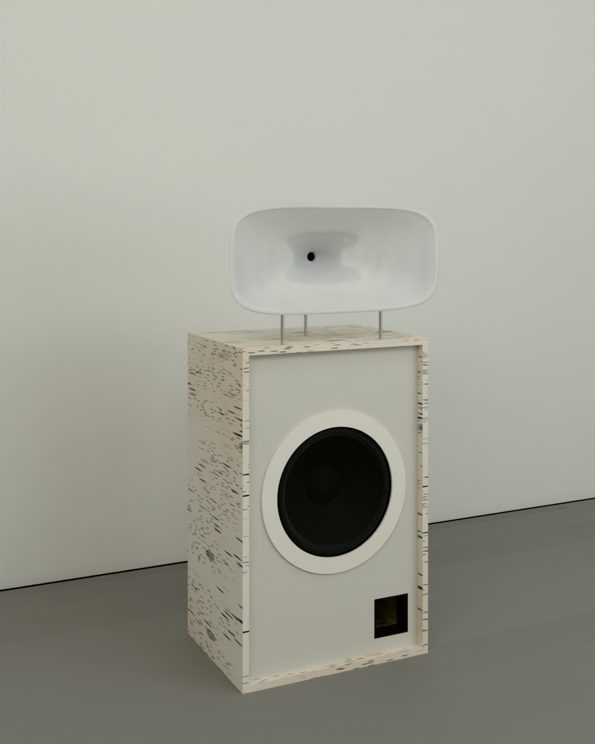
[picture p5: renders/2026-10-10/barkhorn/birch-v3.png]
The birch, three-quarter

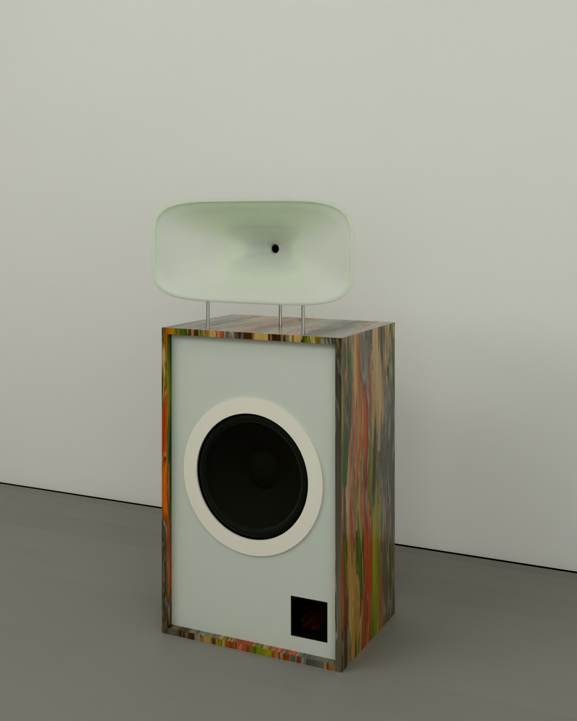
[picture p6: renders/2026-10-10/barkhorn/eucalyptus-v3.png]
The eucalyptus, three-quarter


- **The renders.**
  - Both barks are procedural materials (`birch_bark` and `eucalyptus_bark`).
  - The waveguides use a subsurface-scattering frosted resin (`frosted`), and the covers use `cloth` and `cork`.
  - All of them are in `studio/engine/materials.py`.
  - Photographed CC0 bark (Poly Haven, ambientCG) would need those hosts allowed in the environment's network
    settings.
- **The real finish.**
  - Birch: real bark sheet (*Betula papyrifera*, from fallen or felled trees) laminated with PVA in a vacuum bag and
    sealed matt.
  - Eucalyptus: the shed bark of a smooth-barked gum (a snow or spotted gum) pressed flat and laminated the same way,
    or a UV-printed veneer of it. The wet look is a satin or gloss sealer, which deepens bark's colours as rain does.

  Approve a sample board first.
- **The waveguide** is cast in a two-part silicone mould from a CNC-cut plug, and the cap in a small mould of its own.
  The parts list spreads a mould budget of $900 for the shell and $250 for the cap over the pair. Tinting the resin per
  finish costs nothing more.

## Front covers (options)

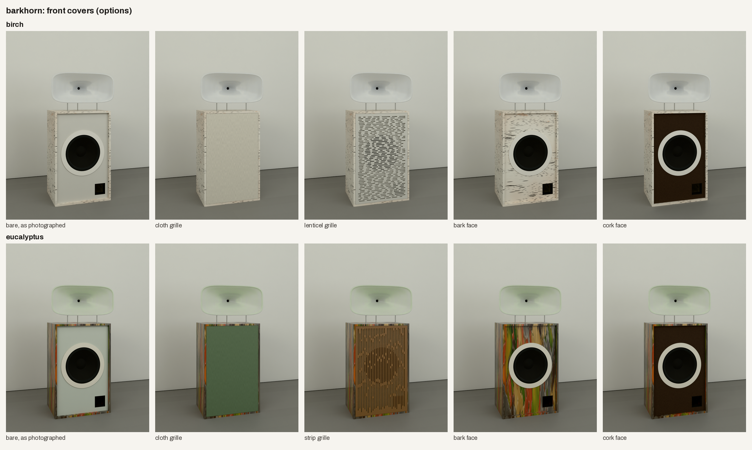
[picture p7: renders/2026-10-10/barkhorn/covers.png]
The covers on both barks


Each cover sits in the 24 mm recess, 1.5 clear of the shell all round. A grille stands flush with the shell's front on
four pegs into cups in the panel's corners. Its back stays at least 16 clear of the cone at rest, which leaves 4.5 mm
even at twice the woofer's Xmax. The woofer plays only below 800 Hz, so a slotted grille open about a quarter of its
face costs it nothing audible: the air behind it resonates in the slots near 1.9 kHz, over an octave above the
crossover.

| option | what it is | the look |
|---|---|---|
| bare (as now) | the painted panel, the ring and the cone, as photographed | the reference, unchanged |
| cloth grille | acoustically transparent knit stretched over a 6 mm MDF frame (sprayed black), its face 1 back from the shell's front; oatmeal `#DCD6C8` on birch, eucalyptus-leaf green `#6F7F66` on eucalyptus | calm and flat: the bark and the horn carry it alone |
| lenticel grille (birch's own) | 6 mm birch plywood sprayed the panel's colour, cut with 394 round-ended 6 mm slots in rows of short dashes of random length, as birch's lenticels; 24 % open | the woofer hidden behind the bark's own pattern: dark dashes on pale, as on the shell |
| strip grille (eucalyptus's own) | 6 mm spotted-gum plywood (a eucalypt hardwood face), oiled, cut with 124 long vertical slots in columns, bridged at random heights, as the bark's strips; 28 % open | warm timber under the wet bark: the tree's wood in front, its bark round it |
| bark face | the panel faced in the bark itself (1 mm), cut round the ring and the port | a log with a speaker in it; the boldest |
| cork face | 3 mm cork sheet laid on the panel round the ring and the port; dark, as smoked expanded cork | cork is bark too (the cork oak's): a third bark, dark behind the white ring |

The slot patterns are seeded, so a rebuild cuts the same panel. Their cut files are in `out/dxf/`, nested on sheets of
their own. The covers' materials are budgets only where the kit has a rate: the cloth, the pegs, the bark, the cork
sheet and the spotted-gum plywood show [PRICE] until a supplier's figure is entered. The woofer's roll height is
proportioned (the datasheet gives none). Confirm on a driver that its roll does not stand proud of its flange before a
grille is fitted.

**My picks:** the **lenticel grille on birch** and the **strip grille on eucalyptus**, each cover drawn from its own
tree. Bare stays the reference for both.

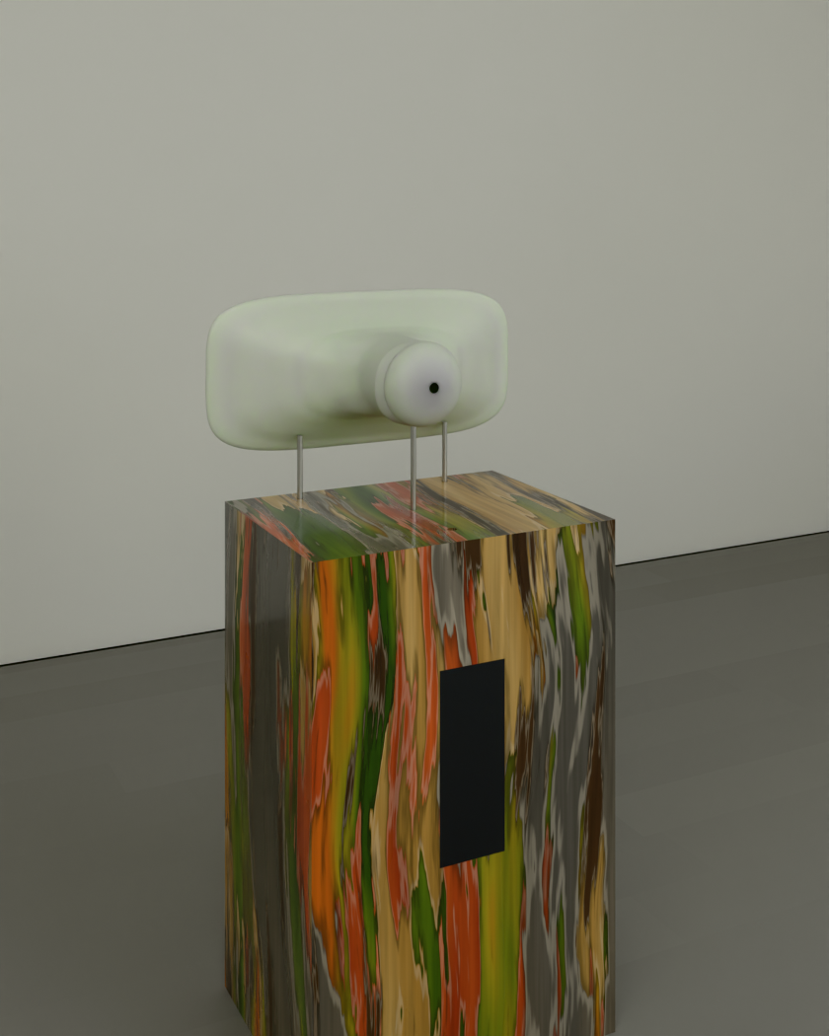
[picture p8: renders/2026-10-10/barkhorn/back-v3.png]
The eucalyptus from behind: the waveguide's pod and cap


## The fabrication package

Built with the fab kit (`studio/fabkit`):

    .venv-fab/bin/python studio/fabkit/build.py spinoffs/barkhorn/product.py
    python3 spinoffs/barkhorn/render_covers.py          # the covers' grid (one frame per bark and cover)

It writes `out/`:

- STEP and STL;
- DXF cut files for the plywood (three 1525 mm sheets), the MDF rings, and each cover on its own sheets;
- the checks (no clashes, covers included);
- the parts list (`bom.md`): about $3,430 for the pair at budget rates, before the few unpriced items, with each cover
  listed after it with its own subtotal;
- 17 A3 drawing sheets (`out/drawings/barkhorn-sheets.pdf`). The assembly sheets show the speaker without covers;
  each cover's cut panel has a sheet of its own, its slots as one pattern;
- the render model.

The shots are in `studio/shots/barkhorn/`:

- `front`: the pair, as photographed;
- `birch` and `eucalyptus`;
- `eucalyptus-detail`: the bark close to;
- `back`: the waveguide from behind;
- `covers/`: one shot per bark and cover.

## Open questions for the owner

1. **The waveguide.** Is the thin shell with its pod the sleek look you meant?
2. **The eucalyptus.** Is this the gum after rain you meant? A photograph of the tree you have in mind would let it be
   matched.
3. **The covers.** Pick per finish, or none. The grilles can also go the other way round (lenticels on eucalyptus,
   strips on birch), and any cover can take another colour.
4. **The colours above.** Keep them or swap. Options include a charcoal front panel on birch, or a salmon or amber
   waveguide on eucalyptus (as Friendly Pressure's amber).
5. **A name.** barkhorn is a placeholder.
6. **Price.** [PAIR PRICE] stays open.

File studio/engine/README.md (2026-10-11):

# The engine: CAD in, photographs out, every setting named

A product's CAD is the single source of its shape; a shot file is the single source of everything else in a
photograph. The engine joins the two in Blender's Cycles, and it writes beside every image what it did and where each
part landed, so a critic can measure the image by part and prescribe changes as settings, and the next render
applies them. No hand-tweaking happens anywhere in between.

```
fab/params.py ─► fab/cad.py, fab/components.py ─► fab/render_model.py ─► out/render/<product>.glb  (one named part each)
                                                                               │
studio/products/<product>.json  (materials by part name, flavours, prints) ───┤
studio/shots/<product>/<shot>.json  (camera, light, set, render) ─────────────┤
                                                                               ▼
                                     python3 studio/engine/render.py SHOT --out IMG [--masks]
                                                                               │
                                IMG.png  IMG.shot.json  IMG.report.json  IMG.mask.png/.json
                                                                               │
              critic/round.py stage ─► a fresh critic (critic/PROMPT.md) ─► critic/rounds/…/*.json
                                                                               │
                                     render.py SHOT --apply that.json [--save-shot SHOT] ◄───┘
```

## Running it

    python3 studio/engine/render.py studio/shots/earmilk/01.json --out renders/DAY/01-e1.png \
        [--set camera.lens_mm=85 --set lights.key.irradiance=2.5]     any setting, by its dotted path
        [--apply critic/rounds/DAY/shot-01-e1-r1.json [--only c1 c3]] a critic's prescribed changes
        [--save-shot studio/shots/earmilk/01.json]                    write the changed shot back
        [--samples 64 --scale 0.5] [--crop X0 Y0 X1 Y1]               a quick proof, or a region
        [--masks]                                                     the part-id mask, for measuring by part

It runs on the system Python with `bpy` (Blender 5); the CAD runs in `.venv-fab` (numpy 2). Lengths are metres, z up,
the product's footprint centred on the origin with its front toward -y.

## The shot file

A shot names its parts by path (`camera.position`, `sun.elevation_deg`, `set.windows.0.along`,
`materials.paint.coat_roughness`, ...), and `knobs.py` gives each path its unit, range and meaning: the vocabulary
`critic/card.py` prints for the critic and the only one the engine reads. `extends` chains a shot to defaults
(`base.json`). Relative changes are allowed: `"+0.5"`, `"x0.8"`, `"+15%"`. Setting a path that is missing makes it,
lists included (`glints.0` adds the first glint).

- **camera:** position and target, lens, `level` (look level and frame by lens shift, so verticals stay vertical),
  extra shift, roll, depth of field and focus.
- **sun and sky:** the sun by azimuth, elevation and irradiance (W/m2), its size and colour; a gradient or physical
  sky, a photographed environment (`sky.kind: "hdri"`, one of the Poly Haven CC0 maps in `studio/assets/hdri`, turned
  by `sky.rotation_deg`: real softboxes and windows for the gloss to mirror), or none.
- **lights:** area, spot and point lamps placed by orbit round the product or by position, aimed at a target, sized,
  in W or in irradiance at the target; light linking (`receivers`) to light only some parts; glints, small lamps set
  exactly where a surface would mirror them into the camera.
- **set:** a sweep (a cove of any size and colour, with flags and bounce cards) or a room (walls with real window
  openings, reveals, mullions and sills, skirting, wainscot, a ceiling, an oak floor by plank, plaster walls) and props
  (rug, table, books, sideboard with a turntable, vase with branches, floor lamp, sofa, sheer curtain, framed print).
- **product:** which product file, which flavour, how many copies where (`instances`), and:
  - `hide`: parts left out, by name pattern (on the product block for every copy, or on one instance for that copy);
  - `options`: the product's options this copy is fitted with (`"options": ["cloth"]` on an instance, or on the block
    for every copy). An option's parts (a cover, listed under `options` in the product file) are left out unless asked
    for;
  - `explode`: `[{"match": "waveguide-insert|magnets-insert", "offset_m": [0, -0.3, 0]}, ...]`, each part moved along
    its own fixing axis in the product's frame, for an exploded view;
  - `cutaway`: `{"box_m": [x0, y0, z0, x1, y1, z1], "skip": "cable-*", "sections": [{"match": "...", "color": "#..."}]}`,
    a boolean cut per part and the cut faces coloured by material (wood shows wood, a printed part its resin, a bought
    part its own material), for a technical cutaway. A part split into zone parts (`zone_parts`) is cut whole and split
    after, since a boolean caps an open mesh badly; a `skip` part stays whole, less any loose piece of it wholly inside
    the box.
- **products:** a list of product blocks instead of one, for a family shot (two sizes in one room).
- **render:** samples, adaptive threshold, denoise, clamp, bounces, the view transform (Khronos PBR Neutral keeps brand
  colours true), exposure, white balance.

## The product file

`studio/products/<product>.json`: the GLB, the CAD point that stands on the origin, the flavours (colour sets),
materials (`materials.py` presets: paint under a clear coat with a faint orange peel, metals, rubber, paper and
coated cones, birch, plastics, glass), `assign` rules from part names to materials, colour `zones` (a band of faces
by height), and `decals`: the print files themselves (the Nutrition Facts, the stencilled marks) laid inside a
material's colour coat, under its clear, exactly where the fab files put them.

## What it writes

- `IMG.shot.json`: the resolved shot, every setting as used.
- `IMG.report.json`: times, samples, the changes applied and any it could not, and `parts_2d`: each part's box and
  centre in the frame's pixels and its distance from the camera, so labels and callouts can be laid over the image
  exactly (a deck, an exploded view).
- `IMG.mask.png` and `.mask.json` (with `--masks`): a flat render where each part's pixels carry its id, so
  `critic/measure.py` measures `part:front-baffle` wherever the camera puts it.

## The meter

    python3 studio/engine/meter.py SHOT --part back-panel --region 783 440 805 620 --target 225

renders the shot small as a scene-linear EXR with its mask and prints each part's or region's true scene-linear
brightness, what the final image shows there now through the view, and the exposure change that would put it at the
target. Exposure is where a critic's prediction is most often wrong (a view transform's shoulder hides how far over a
white is); after applying a round, meter the faces the accept tests name and set the key or the exposure from the
reading, not from the guess. Regions are in the critic's staged image's pixels (0.75 scale).

## Exposing to the critic's tests

    python3 studio/engine/render.py SHOT --apply REPLY --save-shot SHOT --no-render     # apply and save only
    python3 studio/engine/autoexpose.py SHOT REPLY --save                              # one small EXR, then the exposure
    python3 studio/engine/render.py SHOT --out IMG --masks                             # the one full render

`autoexpose.py` reads every brightness and colour test in a critic's reply (lum_median, lum_mean, lum_p5, lum_p95,
r/g/b_median, delta_e) from one small scene-linear render, turned into the final image at each exposure by Blender's
own colour management (the shot's view, look and white balance), and sets the exposure within 1 EV of the shot's that
passes the most of them without clipping the product's whites, by a margin of a few levels, with the smallest change.
Colour counts: PBR Neutral's shoulder bleaches a lit red toward white (scene-linear 1.5, 0.1, 0.1 shows as 248, 91, 91),
so an exposure chosen for the whites alone undid 02b's lowered sun on its plinth (dE 5.6 in the proof, 10.9 after). A test only a bigger change
would pass is not exposure's (a glint that misses, a lamp too weak) and is left to fail. A critic's
relighting is usually right in shape and wrong by a fraction of a stop; this takes the fraction out before the
expensive render instead of after it.

## Tuning one setting by proof

    python3 studio/engine/tune.py SHOT REPLY c3 lights.roof_ramp.strength 0.5 1.5 --save
    python3 studio/engine/tune.py SHOT REPLY '{"region": {"part": "woofer-cone"}, "metric": "lum_p95", "op": "between",
        "value": [100, 150]}' glints.1.power_w,glints.2.power_w 12 24 --save

A critic names the setting and the reading the next image must have; how far to move the setting is a guess until
something is rendered. `tune.py` renders proofs at the critic's scale with the setting at two values, reads the test
exactly as `critic/round.py check` will, and follows the secant toward a reading a margin inside the test (the middle
of a "between"), three or four proofs in all, printing every other test of the reply on each proof. A test of your
own can stand in for the critic's (where its "expected" gives a band and its test only a floor), and several settings
can move together (a symmetric pair of glints). A value that breaks another of the reply's tests is set aside for one
that does not: the tests passing at its own first two proofs, and those the previous tune of the same reply left
passing at the shot as it stands (each saved tune logs them in the shot's `.tune.json` with the shot's hash), so tuning
one lamp after another cannot quietly undo an earlier one.

## The reflection probe

    python3 studio/engine/render.py SHOT --out IMG --probe 'woofer-cone' --scale 0.75

What a glossy part mirrors into the camera, from the scene itself: the camera's rays through the frame, reflected
about the surface's own normal at each hit on the part, followed to the first thing they meet, a lamp's face, a panel,
a surface of the set or the product, or the sky. It prints each thing's share of the part's pixels, the box of those
pixels in the frame and the band of directions they look along, so a card or a lamp is sized and placed to cover the
pixels that should light up (on 05 it showed the critic's 8 x 3 m card reaching 5 % of the cones, which mirror the
open sky in front). Nothing is rendered.

## The mirror map

Every mask pass (`--masks-only`, or `--masks --mirrors`) also writes `IMG.mirror.png`, `.json` and `.npz`: for one pixel
in four on the product, what the camera's ray meets after reflecting about the render's shading normal there (the hit
face's corner normals interpolated at the hit, so a smooth cone mirrors as it shades), followed as Cycles follows it:
past what gloss does not see (`visible_glossy` off: flags), past a panel's or a one-sided card's back, and through a
panel linked to its receivers, which is see-through (they see its light added to what lies behind it), to the first
surface, unlinked panel face or the sky; area lamps it crosses add their light. The label is the stack, brightest
first ("lamp fill + panel glint5 over world (sky)"); the .npz keeps each emitter's radiance at the pixel (a panel's
strength times its ramp there, a lamp's radiance times its specular share) and the world point where the nearest
layer was met. The critic's card prints each part's shares, its measuring tool answers `mirrors X0 Y0 X1 Y1` (or
`part:NAME`) with the shares, radiances and world points, and `critic/round.py save` warns when a change grades a
reflection-only panel its test's region does not mirror.

On 03's round 8 the waveguide wall's flat band was the fill (0.45 after its 0.1 specular share) plus the see-through
glint5 panel (0.25), both even across it, so the rim panel the critic ramped and the panel it then wanted in front of
glint5 could not grade it; an opaque panel between the wall and the fill can (precheck: 99 % of the band mirrors it).

    python3 critic/round.py precheck REPLY --shot-id shot-07 --version e11

applies a reply's changes to a copy of the judged frame's shot and runs the map alone (about 40 s, no render): for each
reflection-only panel prescribed, the share of its test's region that mirrors it, its radiance there and the stack the
region sees. 07's round 10 placed its bowl panel where 15 % of the bowl looked; with the map the critic moved it to
where 98 % does, before a proof was rendered.

## The retouch

    "retouch": {"enabled": true, "match": 1.0, "lightness": 0.5, "neutral": 1.0}

A path tracer reproduces a paint's swatch only in the even white light the view transform is built for; under a
studio's lamps a red lacquer's lit face mirrors a dark room, and PBR Neutral's toe takes its green and blue to nothing
(#C62828 rendered as (182, 14, 15), dE 4 to 9 off the swatch on most shots of 2026-10-09's critic rounds). The retouch
does what a retoucher does before a product shot ships. The mask pass renders a swatch mask (each product pixel's
paint and copy, from the materials a flavour colours: body, accent, insert); `retouch.py` reads each paint's lit face
off the frame (the pixels between the 40th and 90th percentile of its lightness that carry at least its median
chroma) and corrects every pixel of it, weighted by how much it is the paint (the mask softened over its edge, times
its chroma against the face's), so highlights and edges move less:

- a white loses the share `neutral` of its cast (1 in a studio; 0 for 02b's late sun, whose warm white is the
  picture);
- a colour takes the swatch's hue and chroma by the share `match`, as the swatch reads under the light the copy's own
  white shows (Bradford adaptation from D65), and the share `lightness` of its lightness, as a gain on its light.

The raw frame stays as `IMG.raw.png`, the render's report lists each paint's lit face before and after in dE2000,
the critic's card prints that table and the `retouch.*` settings, and every test reads the retouched frame. A
`--masks-only` pass retouches a frame already rendered (from its raw when there is one), so a shot can be retouched
without rendering it again. On 01 e11: the reds from dE 7.2 to 9.5 to 3.2 to 5.1 (the rest is the half of the
lightness left), both whites from 2.4 and 3.5 to 0.

## The CAD's normals

The GLB carries the CAD's normals: flat on every face, turning on the 6 mm rounds. Blender's importer sets them as
custom normals. Marking the faces smooth afterwards (which the terminator offset needs) re-reads those normals in new
spaces. Before 2026-10-10 that bent the flat faces' corners up to 6.3 degrees toward the rounds (p95 3.1 degrees on
the back panel). A big face's triangles spread the tilt across the face, so the white panels mirrored as faintly
curved card, and no card with an edge could land on them straight. 04a's round 13 read it in the back's reflections.
`import_model` now reads the imported normals, carries them through the transform and sets them again. A flat face's
corners are then within 0.02 degrees of its normal (p95), and everything rendered since has flat lacquer panels.

## The finish

    "finish": {"enabled": true, "white_in": 213, "white_out": 236, "contrast": 0.12, "clarity": 0.08,
               "sharpen": 0.35, "sharpen_px": 0.7}

A frame out of the view transform has no white. Every blind critic from 2026-10-08 to 10 read the white lacquer as
"flat grey", and the frames bear it out: the white paint's lit face at 205 to 218 of 255 on every shot, under 0.4 %
of any frame above 235. Lights cannot fix it: the view transform's shoulder starts near 200, so a brighter key
flattens the face before it whitens it, and the critics' own tests held the faces under 216 to keep their gradients.
A photographer sets the white point in post. `finish.py` does the same, in the order a retoucher works:

- **tone**, on the raw frame: a mild S about mid-grey (`contrast`), then a gain on luminance that takes `white_in`
  (the white paint's lit face as rendered) to `white_out`, with a smooth shoulder above it into `white_out` to `peak`
  (251), so nothing clips; the gain is applied to all three channels in linear light and lowered wherever it would
  take a channel past the peak, so colours keep their hue and a saturated light (the amplifier's cyan LED) its colour;
  then `clarity`, local contrast at a large radius in the midtones only;
- **the retouch**, on the toned frame, so the paints still land on their swatches;
- **sharpen**, last: an unsharp mask on luminance at `sharpen_px` (scaled with the frame's width from 1350 px), cored
  (differences under `sharpen_core` levels are noise) and clamped to each pixel's 3 x 3 neighbourhood, so an edge
  gets crisper without a halo either side.

A **dodge** is a retoucher's masked lift: `finish.dodge` lists rules such as `{"parts": ["tweeter-frame",
"tweeter-dome"], "lift_ev": 1.0, "below": 70, "knee": 15, "feather_px": 3}`. Each named part's pixels (from the frame's
part mask) that are darker than `below` gain up to `lift_ev` stops in linear light, fading to none over `knee` levels
above it. The mask is eroded, then feathered inside the parts' edges, so the neighbours move by two levels at most.
08b's round 9 asked for it: the tweeter's matte black parts, crushed at 3 to 37, had nothing on the card to separate
them without lighting the cut faces around them. On 08b e11 it took the retainer from 22 to 34 and the frame's crush
from 27 % to 5 %.

`python3 studio/engine/finish.py calibrate IMG` reads the white paint's lit face off `IMG.raw.png` (its 75th
percentile of luminance, from the swatch mask) and prints the `white_in` that puts it at `white_out`, the gain capped
at 1.12 so a white the light leaves in shade is not dragged up to a lit one. The tuner treats `finish.*` like
`retouch.*`: one proof is rendered, the rest only rerun the post chain on its raw frame. A `--masks-only` pass
re-finishes a frame from its raw without rendering it again.

Blind A/B judges (critic/ab/2026-10-10-finish.md), the same frame with and without: 04b 7.0 against 6.0, 09 6.2
against 5.3, the first version; its faults (a shoulder that clipped the top of 04b's face, halos, the LED bleached,
grain up 40 %) are what the shoulder, the cap, the clamp and the coring above take out.

## Lamp shares

A lamp's `diffuse` and `specular` (0 to 1) are made with ray visibility, which Cycles honours in light sampling too:
a share of 0 hides the lamp from that ray type, and a fraction goes to a twin lamp in the same place at that share of
the power with the other ray type off (as a panel's fractions do); a glint lamp is specular only the same way. Cycles
ignores a lamp's diffuse and specular factors, which are EEVEE's (a test scene renders the same at 0 and at 1), so
until 2026-10-10 every share rendered at full strength: a fill at specular 0.1 mirrored at its whole radiance (03's
waveguide band), a lamp at specular 0 laid a pale plate across 08b's bowl (gone with the fix), and every glint lamp lit
its part as well as glinting on it. The shares are the default (`EARMILK_LAMP_SHARES=0` keeps the old rendering).

## How light reads as a photograph

Fifteen rounds held the blind scores at 5 to 6 while each round fixed what it measured, and the blind impressions kept
naming the same things: a white that reads as flat grey card, lacquer that reads as paint, a product that glows or looks
pasted. Three causes ran through the frames, and the card now spells them out in each frame's own lamps:

- **Lamps linked to one part.** A lamp with `receivers` and a diffuse share lights its parts and nothing round them, so
  the part brightens while its floor, wall and shadow do not: 05 carried seven such lifts, 09 and 10 read as
  "self-glow". The card lists them and puts turning them off in scope; `receivers` belongs to reflection-only cards
  and glints.
- **The polariser.** Four studio frames (04a at 0.97, 04b, 05, 08b) carried one, and it removes the very reflections
  that tell lacquer from paint: in a 05 proof the white fronts gained 13 levels of reflection when it came off.
- **Reflection strength.** A clear coat mirrors 4 to 5 % head-on, so a card shows on a white only at many times the
  white's own radiance: 05's floor card at strength 1.55 (exposure -1.35) added 5 levels, invisible. The card gives the
  arithmetic (strength x 0.045 x 2^exposure) and the warning that goes with it.

The warning is measured. A relit 05 (a coherent five-lamp rig, the dome and the polariser off, the floor card at strength
7 for every copy) lost a blind side-by-side to the frame it replaced, 4.0 to 5.0: the white fronts gained their
reflections, but the same card blew the Matcha and Oat fronts out to white, turned the Chocolate pink and the plinths'
sides a frosted grey, and "a colourway the shot exists to sell, shown wrong" outweighed the gloss. Reflections are
calibrated per face, a dark or coloured face taking a fraction of a white's, and that is the critic's to prescribe with
the mirror map's radiance in front of it.

## What the engine makes exact

- **Glints** are placed from the surface the camera sees at their point, with that surface's own normal (the camera's
  ray through `at`, else the nearest receiving surface that faces the camera); a glint whose lamp would have to sit
  behind the floor or inside the product is skipped, because that surface mirrors the floor there, and the render's
  report and the next critic's card say so. The test for what hides the lamp ignores the surface itself: a hit within
  2 mm, a face seen from behind (a connector's bezel sunk in its module), and the parts in `occlusion_ignore`.
- **Flags**: a reflect-only flag (`set.flags`, `reflect_only`) is one-sided, seen only from the side its normal faces,
  so a card laid on the floor shows in the product's lacquer while the floor's own gloss, looking at its back, sees
  through it; two-sided it printed a straight-edged patch on the sweep.
- **The sun through a window**: `sun.aim` `{"at": [x, y, z], "window": 0, "through": [0.5, 0.5]}` sets the azimuth
  and elevation that send the sunlight through that point of the window onto `at`.
- **Panels**: `{"type": "panel", ...}` is an emissive rectangle the camera cannot see, its brightness ramped along a
  world axis, lighting one side, casting no shadow, with `diffuse: false` seen only in reflections and with
  `receivers` only in the parts named: a graduated scrim for a lacquered roof, a reflection card for a cone. `diffuse`
  and `specular` take a fraction too (0.15: a reflection at full strength that lights at 15 %): a second panel in the
  same place, unseen by the camera, carries the fraction, because Cycles samples an emitter's light without a ray type,
  so a Light Path node in the panel's shader would change what reflections see and leave its light at full strength.
- **Zone parts**: with `product.zone_parts` true, a colour zone that names a `part` in the product file (the plinth
  band) is split off each panel as a part of its own, `back-panel.plinth`, its faces, materials and normals as they
  were. A lamp with `"receivers": ["*.plinth"]` then lights the red band and not the white above it, which no other
  lamp can (04b's round 11: the band 7 to 12 dE dark while the roof sat at 3.5). A part's patterns still take its
  zones, in receivers and in `measure.py` (`part:back-panel` is the panel with its band; `part:*.plinth` the bands).
- **Contact core**: `set.contact.core_strength` and `core_distance_m` add a second, tight ambient-occlusion term to the
  sweep's contact shadow, multiplied with the first: the dark line right where a base meets the floor, which a wide
  term at its ceiling only spreads into a halo.
- **The inside**: in a cutaway or an exploded view, the faces inside the product (a cavity's walls, a face another
  part covers) take the product's `interior` materials (raw birch, bare resin), found by rays from each face against
  the assembled product before it is opened; a shadow line's walls stay painted.
- **Sections**: a cut face takes its rule's section material. A plywood panel's (a birch rule, a part thinner than
  40 mm) shows its veneers: 1.4 mm each across its thickness, long and end grain alternating, a glue line between; a
  driver cut through shows bare steel (the motor) and aluminium (the basket).
- **True surfaces**: a part made by a ruled loft through polygon rings (the waveguide) takes its shading normals from
  its analytic surface sampled finely (`normals_from`, the grid from `fab/horn_grid.py`), interpolated linearly across
  each grid triangle; `refine` cuts its facets and sets the new corners on that surface, and `skin` lays the surface
  itself over the facets a hair into the air, because a concave bowl mirrors its own far wall and its facets show in
  reflections however its normals are set. None of that cured the teeth along the bowl's floor; the mesh did. Where
  the side walls turn into the floor, neighbouring meridians differed in length by 10 to 15 mm, so stations at the same
  fraction of each wall sat at different depths and the ruled quads between them twisted; and the wall has a true
  crease there (in the floorstander at 205 and 335 degrees, where the coverage starts to be narrowed). The CAD now puts
  a meridian on each crease and adds them wherever neighbours differ by more than 2 mm (`Waveguide.phis`: 256 instead
  of 96 in the floorstander, 160 in the bookshelf), and the teeth are gone. A reflection that breaks into teeth is the mesh's parameterisation before it is the shading's.
- **Real blacks**: the products' black paint, rubber, plastic and anodising reflect 3 to 4 %, as real ones do; at
  under 1 % no light can model a driver's basket or an amplifier's plate.
- **Oak boards**: each board is its own piece of wood. A second brick texture gives every board a random number that
  offsets its grain (the grain stops at the seams, where laminate's runs on), sets its sheen and its cut: flat-sawn
  boards show their growth rings as cathedral arches, rift-sawn ones as straight lines, the latewood a thin dark line.
  Each row is slid along by its own random amount, so the end joints fall at random (a brick texture's regular offset
  lined them up in every other row, a column of joints the 01 critic found).
- **A polarising filter** (`camera.polariser`: `strength` 0 to 1, `angle_deg` the pass axis from horizontal). A clear
  coat's reflection is polarised: across the plane of incidence (s) it reflects more than in it (p), and at Brewster's
  angle (56 degrees off the normal for a 1.5 lacquer) only s reflects. The filter scales each camera ray's specular
  on every dielectric (coat and specular level; not metals or glass) by 2 (Rs cos2 a + Rp sin2 a) / (Rs + Rp), from
  the Fresnel terms at that ray's angle and the angle a between s and the pass axis, and leaves the diffuse alone,
  the exposure made good. So it clears the veil a bright room lays over a lacquered red on a roof slope or a plinth's
  side, as it does on a camera, and does nothing head-on. Only camera rays see it: what the surfaces light and mirror
  for each other is unchanged. On 03 at full strength, the axis vertical, the lit roof went from dE 6.5 to 4.0 off
  #C62828 and the horn's floor from 75 to 55, darker than the roof, as a recess reads; the dome's highlight and the
  left wall's band, at other angles, stayed (`renders/2026-10-09/engine/polariser-03-proof.png`, without and with).
- **A wainscot's sheen** (`set.wainscot.roughness`, 0.38 satin by default): a satin dado mirrors a lamp's panel as a
  soft halo behind the product, a backlight no light in the room explains (the 02b critic's round 5); at 0.7, eggshell,
  it blurs the lamps into its own shade, so a reflection panel can stay on for the lacquer.
- **Part positions after a masks-only pass**: `render.py --masks-only` evaluates the scene before it reads where each
  part lands in the frame. Without a render nothing had moved the exploded parts or the camera into place, and 07-e6's
  report put its parts behind the camera; the deck's callouts read these positions.

The critic may also move and turn the product within its set (`product.instances.N.position`, `.rotate_z`), set how
far an exploded part is drawn out along its own axis (`product.explode.N.offset_m`), and dress a room with the
engine's props (`set.props.N`: rug, table, books, sideboard, vase, lamp, sofa, curtain, frame; `off` takes one out).
The product's geometry, flavour, marks and what is cut stay fixed.
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

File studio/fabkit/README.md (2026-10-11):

# fabkit: one product file in, a fabrication package out

The kit builds any concept's whole fabrication package from one Python file that says what the parts are. The concept
can be a speaker, a lamp or a valve amp. The product file gives its numbers and a function that turns them into
parts. Each part is a solid (build123d, placed where it sits), how it is made, and how it is finished. Everything
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

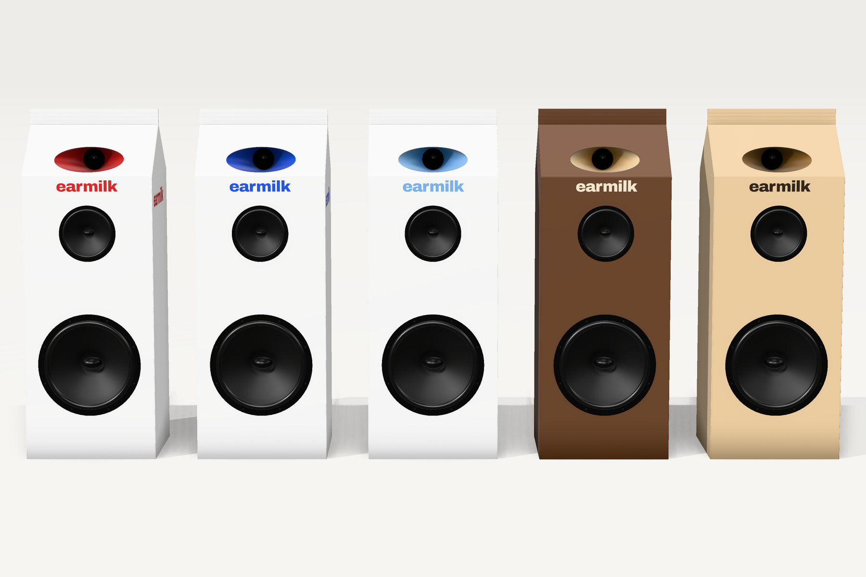
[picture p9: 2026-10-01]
explore/2026-10-01/color-wordmark-as-spec.png

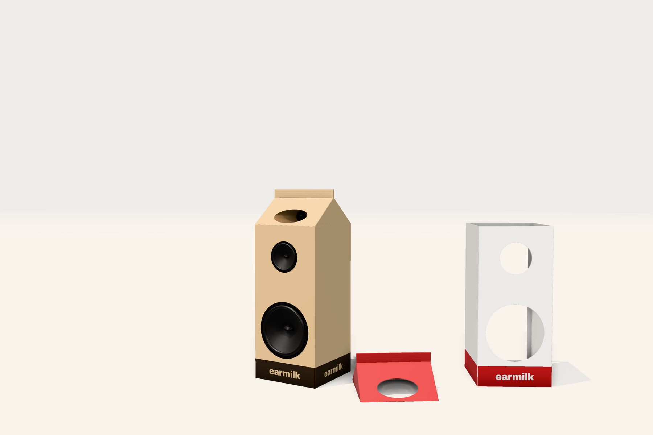
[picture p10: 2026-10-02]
renders/2026-10-01/shot-07-v5c.png

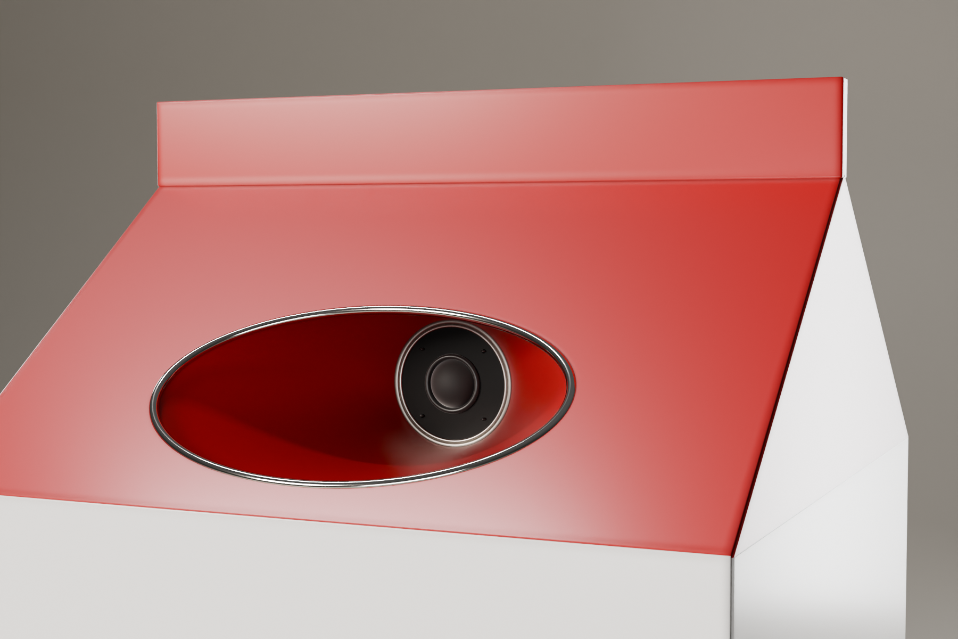
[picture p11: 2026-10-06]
renders/2026-10-06/shot-03-v19-pt.png

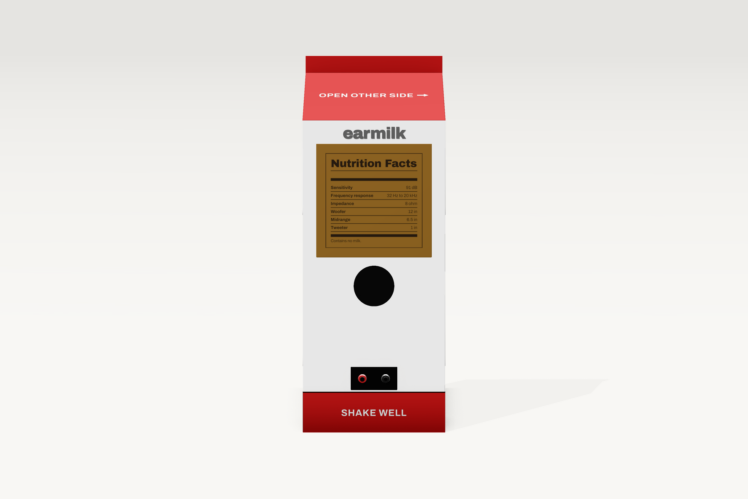
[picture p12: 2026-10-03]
renders/2026-10-03/shot-04-v12.png

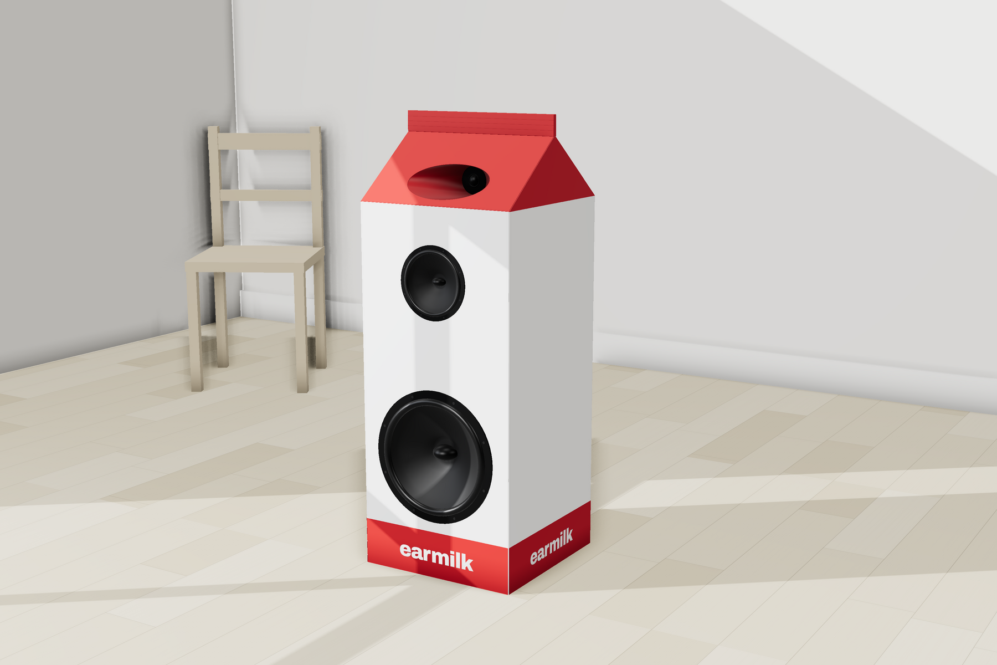
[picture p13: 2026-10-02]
renders/2026-10-01/shot-02-v5a.png

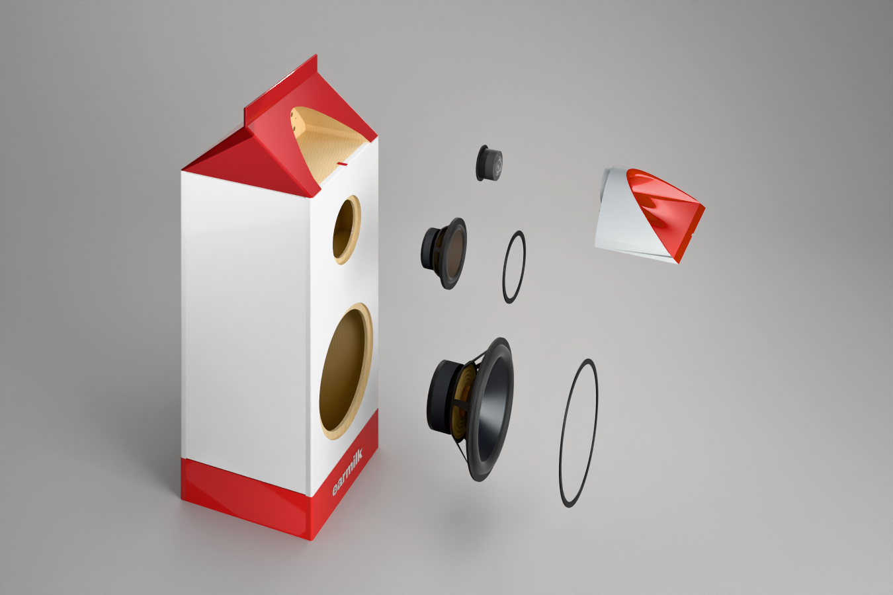
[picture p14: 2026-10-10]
renders/2026-10-10/finished/07-e14.png

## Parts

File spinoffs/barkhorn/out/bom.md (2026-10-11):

# barkhorn: parts for 2 (Two-way horn loudspeaker after Friendly Pressure, in birch bark or eucalyptus bark)

| item | make | qty | what | size | each, USD |
|---|---|---|---|---|---|
| left, right | cut | 4 | 18 mm Baltic birch plywood, BB/BB | 420 x 880 | 26.80 |
| top | cut | 2 | 18 mm Baltic birch plywood, BB/BB | 524 x 420 | 15.96 |
| bottom | cut | 2 | 18 mm Baltic birch plywood, BB/BB | 524 x 420 | 15.96 |
| front-panel | cut | 2 | 18 mm Baltic birch plywood, BB/BB | 524 x 844 | 32.06 |
| back | cut | 2 | 18 mm Baltic birch plywood, BB/BB | 524 x 844 | 32.06 |
| brace | cut | 2 | 18 mm Baltic birch plywood, BB/BB | 524 x 360 | 13.68 |
| woofer-ring | cut | 2 | 6 mm MDF | 436 x 436 | 4.28 |
| port | print | 2 | ASA, FDM (outdoor, paintable) | 89 cm3 | 14.22 |
| woofer | buy | 2 | FaitalPRO 15PR400-8 15 in woofer (treated paper cone, neodymium, 8 ohm) | 393 frame, 356 cut-out, 165 deep | 194.00 |
| amp-plate | buy | 2 | Hypex FusionAmp FA122 DSP plate amplifier, 2 x 125 W into 4 ohm | 315 x 120 x 55 plate, 291 x 96 recess | 422.40 |
| waveguide | cast | 2 | Tinted polyurethane casting resin, translucent | 1513 cm3, 643 x 250 x 302 | 521.55 |
| waveguide-cap | cast | 2 | Tinted polyurethane casting resin, translucent | 117 cm3, 158 x 65 x 158 | 135.16 |
| hf | buy | 2 | BMS 4550-16 compression driver, 1 in exit, polyester diaphragm, 16 ohm | 123 across, 52 deep, 2 x M6 on 76.2 | 154.00 |
| rod-1, rod-2 | lathe | 4 | Stainless steel 304 | 20 x 20 x 125 | 16.50 |
| rod-3 | lathe | 2 | Stainless steel 304 | 20 x 20 x 162 | 26.94 |
| bark | buy | 4 | Bark for laminating, a square metre: paper birch (Betula papyrifera) sheet from fallen or felled trees, or a smooth-barked gum's shed bark pressed flat (or a UV-printed veneer of it); approve a sample board first |  | [PRICE] |
| woofer-fixings | buy | 2 | M6 x 25 button heads (A2) with M6 T-nuts, a set of 8 (the 15PR400's eight holes on 375) |  | [PRICE] |
| hf-fixings | buy | 2 | M6 x 25 socket caps with washers (the compression driver to the horn's flange), a pair |  | [PRICE] |
| gasket | buy | 4 | 1.5 mm closed-cell foam gasket strip, 1 m |  | 5.00 |
| damping | buy | 4 | Polyester fibre fill, 150 g |  | 8.00 |
| amp-fixings | buy | 2 | Hypex 4.3 x 16 self-tapping pan heads and 3 mm EPDM tape, a plate's set |  | 10.00 |
| cable | buy | 6 | Round-sheathed speaker cable 2 x 1.5 mm2, 1 m |  | 2.00 |
| terminals | buy | 8 | 6.3 mm insulated push-on terminal |  | 0.50 |
| hf-pad | buy | 2 | Resistor L-pad for the HF channel, about -10 dB at 16 ohm (lowers the amplifier's hiss through a 113 dB driver) |  | [PRICE] |
| glides | buy | 2 | Felt glides 30 mm, screw-in, a set of 4 |  | [PRICE] |

| | USD |
|---|---|
| buy | 1,629 |
| cast | 1,313 |
| cut | 335 |
| lathe | 120 |
| print | 28 |
| total | 3,426 |

No price yet for: Bark for laminating, a square metre: paper birch (Betula papyrifera) sheet from fallen or felled trees, or a smooth-barked gum's shed bark pressed flat (or a UV-printed veneer of it); approve a sample board first; M6 x 25 button heads (A2) with M6 T-nuts, a set of 8 (the 15PR400's eight holes on 375); M6 x 25 socket caps with washers (the compression driver to the horn's flange), a pair; Resistor L-pad for the HF channel, about -10 dB at 16 ohm (lowers the amplifier's hiss through a 113 dB driver); Felt glides 30 mm, screw-in, a set of 4.

## Options (each for 2, on top of the total above)

### cloth: about $20 before the unpriced

| item | make | qty | what | size | each, USD |
|---|---|---|---|---|---|
| cloth-frame | cut | 2 | 6 mm MDF | 520 x 840 | 9.83 |
| grille-cloth | buy | 2 | Acoustically transparent speaker cloth (a knit sold for grilles), about 0.6 x 0.95 m a grille, in the finish's colour |  | [PRICE] |
| grille-pegs | buy | 2 | Grille pegs and cups, a set of four (push-fit; the cups in 10 mm holes 12 deep in the panel's corners) |  | [PRICE] |

No price yet for: Acoustically transparent speaker cloth (a knit sold for grilles), about 0.6 x 0.95 m a grille, in the finish's colour; Grille pegs and cups, a set of four (push-fit; the cups in 10 mm holes 12 deep in the panel's corners).

### lenticel-grille: about $64 before the unpriced

| item | make | qty | what | size | each, USD |
|---|---|---|---|---|---|
| grille-lenticel | cut | 2 | 6 mm Baltic birch plywood, BB/BB | 521 x 841 | 31.77 |
| grille-lenticel-pegs | buy | 2 | Grille pegs and cups, a set of four (push-fit; the cups in 10 mm holes 12 deep in the panel's corners) |  | [PRICE] |

No price yet for: Grille pegs and cups, a set of four (push-fit; the cups in 10 mm holes 12 deep in the panel's corners).

### strip-grille: [PRICE]

| item | make | qty | what | size | each, USD |
|---|---|---|---|---|---|
| grille-strips | cut | 2 | 6 mm Spotted gum-veneered plywood (a eucalypt hardwood face) | 521 x 841 | [PRICE] |
| grille-strips-pegs | buy | 2 | Grille pegs and cups, a set of four (push-fit; the cups in 10 mm holes 12 deep in the panel's corners) |  | [PRICE] |

No price yet for: 6 mm Spotted gum-veneered plywood (a eucalypt hardwood face); Grille pegs and cups, a set of four (push-fit; the cups in 10 mm holes 12 deep in the panel's corners).

### bark-face: [PRICE]

| item | make | qty | what | size | each, USD |
|---|---|---|---|---|---|
| bark-face | buy | 2 | Bark for laminating, a square metre: paper birch (Betula papyrifera) sheet from fallen or felled trees, or a smooth-barked gum's shed bark pressed flat (or a UV-printed veneer of it); approve a sample board first |  | [PRICE] |

No price yet for: Bark for laminating, a square metre: paper birch (Betula papyrifera) sheet from fallen or felled trees, or a smooth-barked gum's shed bark pressed flat (or a UV-printed veneer of it); approve a sample board first.

### cork-face: [PRICE]

| item | make | qty | what | size | each, USD |
|---|---|---|---|---|---|
| cork-face | cut | 2 | 3 mm Cork sheet, agglomerated | 523 x 843 | [PRICE] |

No price yet for: 3 mm Cork sheet, agglomerated.

Budget figures: bought parts from the component library (dated retailer listings), made parts from the kit's stock rates: 25 % offcut on sheet parts, a handling charge a print, and a setup a machined line spread over its pieces. A shop's quote replaces them.

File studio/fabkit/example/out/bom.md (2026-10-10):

# Birch Box: parts for 2 (Two-way active bookshelf speaker (the kit's example))

| item | make | qty | what | size | each, USD |
|---|---|---|---|---|---|
| left, right | cut | 4 | 18 mm Baltic birch plywood, BB/BB | 260 x 400 | 7.54 |
| top, bottom | cut | 4 | 18 mm Baltic birch plywood, BB/BB | 194 x 260 | 3.66 |
| baffle | cut | 2 | 18 mm Baltic birch plywood, BB/BB | 194 x 364 | 5.12 |
| back | cut | 2 | 18 mm Baltic birch plywood, BB/BB | 194 x 364 | 5.12 |
| waveguide | print | 2 | Tough (ABS-like) SLA resin | 202 cm3 | 78.82 |
| woofer | buy | 2 | SB Acoustics SB17NRX2C35-8 6.5 in Norex (paper cone) | 171 frame, 144.9 cut-out, 75 deep | 76.70 |
| tweeter | buy | 2 | Scan-Speak Illuminator D3004/602200 26 mm dome | 62 faceplate | 165.00 |
| amp-plate | buy | 2 | Hypex FusionAmp FA122 DSP plate amplifier, 2 x 125 W into 4 ohm | 315 x 120 x 55 plate, 291 x 96 recess | 422.40 |
| foot-1, foot-2, foot-3, foot-4 | lathe | 8 | White oak, solid | 40 x 40 x 22 | 10.63 |
| woofer-fixings | buy | 2 | M4 x 20 low-profile button heads (A2) with M4 T-nuts, a driver's set of 4 | M4 | 4.00 |
| gasket | buy | 2 | 1.5 mm closed-cell foam gasket strip, 1 m |  | 5.00 |
| damping | buy | 2 | Polyester fibre fill, 150 g |  | 8.00 |
| amp-fixings | buy | 2 | Hypex 4.3 x 16 self-tapping pan heads and 3 mm EPDM tape, a plate's set |  | 10.00 |
| cable | buy | 2 | Round-sheathed speaker cable 2 x 1.5 mm2, 1 m |  | 2.00 |
| terminals | buy | 8 | 6.3 mm insulated push-on terminal |  | 0.50 |

| | USD |
|---|---|
| buy | 1,390 |
| cut | 65 |
| lathe | 85 |
| print | 158 |
| total | 1,698 |

Budget figures: bought parts from the component library (dated retailer listings), made parts from the kit's stock rates: 25 % offcut on sheet parts, a handling charge a print, and a setup a machined line spread over its pieces. A shop's quote replaces them.

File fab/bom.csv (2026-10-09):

group | item | size | for a pair | unit price USD | source | status | note
Electronics | Hypex FusionAmp FA253 plate amplifier: 3 channels (250 + 250 + 100 W into 4 ohm), DSP crossover and EQ, mains in | floorstander | 2 | 647 (EUR 649) | Parts Express (US), Hypex direct (EU) | researched | Lies on its side across the back's foot, flush in a 4.5 mm rebate on 3 mm EPDM tape; the module sits in its own sealed box (fab/out/drawings sheet 4). Load the crossover with Hypex Filter Design over USB (fab/out/dsp/floorstander.md).
Electronics | Hypex FusionAmp FA122 plate amplifier: 2 channels (2 x 125 W into 4 ohm), DSP crossover and EQ, mains in | bookshelf | 2 | 422 (EUR 429) | Parts Express (US), Hypex direct (EU) | researched | Stands upright on the back, flush in a 4.5 mm rebate on 3 mm EPDM tape, module in its own sealed box (fab/out-bookshelf/drawings sheet 4; fab/out-bookshelf/dsp/bookshelf.md).
Drivers | Woofer: Dayton Audio RSS315HF-4, 12 in Reference HF, aluminium cone, 4 ohm | floorstander | 2 | 239.98 | Parts Express | researched | Cutout 282, frame 314, depth 146 (fab/research/drivers-floorstander.md). Confirm the cutout and the flange on the part before cutting the baffle.
Drivers | Mid: SB Acoustics Satori MR16P-8, 6.5 in papyrus cone | floorstander | 2 | about 207 (EUR 180-190) | Madisound, Willys Hi-Fi, Soundimports | researched | Cutout 140.3, frame 165, depth 75.6, in the 7.6 L sealed chamber.
Drivers | Tweeter: SB Acoustics Satori TW29DN-B, 29 mm dome, 4 ohm, faceplate removed (SB documents it) | floorstander | 2 | about 165 (EUR 150) | Willys Hi-Fi, Masori, Madisound | researched | Rear-mounted on the waveguide insert. Buy one first and measure its diaphragm and body: the insert's counterbore and the waveguide's r0 22.5 are drawn from the research's estimates.
Drivers | Woofer: SB Acoustics SB17NRX2C35-8, 6.5 in Norex paper cone | bookshelf | 2 | 76.70 | Madisound, Solen | researched | Cutout 144.9 (unconfirmed), frame 171, depth 75, sealed 9.2 L net with a DSP shelf to 45 Hz.
Drivers | Tweeter: Scan-Speak Illuminator D3004/602200, 26 mm dome, 62 mm faceplate | bookshelf | 2 | about 165 (CAD 222.71) | Solen, Madisound (order), Scan-Speak dealers | researched | Its faceplate screws to the insert's back (3 screws). Fs 440 Hz; crossed at 2.4 kHz (the bookshelf's waveguide study).
Wiring | Speaker cable, round-sheathed (H05VV-F). Floorstander pair: 1.4 m of 2 x 2.5 mm2 (woofers), 2.4 m of 2 x 1.5 (mids), 2.9 m of 2 x 1.0 (tweeters). Bookshelf pair: 1.0 m of 2 x 1.5 (woofers), 1.4 m of 2 x 1.0 (tweeters) | both | per size, as listed (about 20 % over the runs) | 1-3 per m | any electrical supplier | estimate | Round, about 9.0, 8.0 and 6.4 across, so the gland's seal grips it (zip cord will not seal). Runs and lengths: drawings sheet 4 and 8 (floorstander a speaker 0.6, 1.0 and 1.2 m; bookshelf 0.4 and 0.6 m). The cabinet's tweeter cable is fed down its channel from the bay and ends in the connector's socket standing on the bay's floor, 77 mm past the top panel's underside (40 on the bookshelf). Hypex's harness pairs are cut to about 150 mm inside the amplifier's box and butt-spliced to these: only round cable passes the glands.
Wiring | Tweeter lead: 2 x 0.75 mm2 silicone-insulated flexible wire, twisted | both | 0.7 m | about 2 | any | estimate | Soldered to the tweeter's tabs, 320 mm long (220 on the bookshelf), the connector's plug on its end: it reaches the socket in the bay with the insert held clear of its pocket, and its spare loops into the bay when the insert is home (drawings sheet 3).
Wiring | Connector, Molex Mini-Fit Jr., 2 circuits: receptacle housing 39-01-2020 with female terminals 39-00-0077 (16 AWG, the cabinet's 1.0 mm2 lead); plug housing 39-01-2021 with male terminals 39-00-0041 (18 to 24 AWG, the tweeter's 0.75 mm2 lead) | both | 2 pairs | about 3 | Digi-Key, Mouser | estimate | The tweeter's lead plugs into the cabinet's lead in the connector bay behind the insert, so the insert comes out with the tweeter (drawings sheet 3). Female contacts on the amplifier's side; pin 1 red +; mated 24 mm or less. Check the terminals' wire range against the Molex drawings and crimp with the matching tool.
Wiring | Neutral-cure silicone sealant (a small tube) | both | 1 | about 8 | any | estimate | Seals the tweeter cable in its channel, 20 mm deep from the bay (sheet 3), and holds the trim rings on three dots each.
Wiring | Cable glands, M16 x 1.5, long thread (15 mm), nylon, one per cable, clamping about 4.5 to 10 mm, each with a lock nut 20 AF or less (23 across corners), 5 thick | both | 6 (floorstander: 3 a speaker), 4 (bookshelf) | about 2 | any | estimate | One gland per cable: the 9.0, 8.0 and 6.4 mm round cables would not seal in one multi-hole insert. In ø16.5 holes on 35 mm centres in the amplifier box's lid. Each lock nut is epoxied into its ø24 x 8 counterbore under the lid before the lid goes in (glue-up G2): sunk 3 deep, no spanner reaches it. Check the clamping range against the cable you buy.
Wiring | Adhesive cable-tie mounts, 20 x 20 mm, and 2.5 mm ties | both | 16 (floorstander: 8 a speaker), 4 (bookshelf: 2 a speaker) | under 0.2 | any | estimate | Floorstander (note 4.6): three on the amplifier box's lid, one on the brace's top face, two on the right side and two on the divider's back face, each stuck on its panel before that panel goes in; none under the top panel, where the tweeter's run hangs from its channel's seal. Bookshelf (note 4.5): one on the lid, one on the box's front face; the tweeter's 60 mm run needs none.
Hardware | Neodymium disc magnets N42: 12 x 4 mm (floorstander), 8 x 3 mm (bookshelf) | both | 16 (8 per speaker) | about 0.5 | K&J Magnetics, first4magnets | estimate | Four in the insert's back and four facing them in the pocket's back wall, opposite poles out; epoxy.
Hardware | Steel dowel pins: 6 x 10 mm (floorstander), 4 x 8 mm (bookshelf) | both | 4 | under 1 | McMaster-Carr, any | estimate | Two in the insert's back locate it in the pocket: bonded with epoxy in the insert (0.1 over), a slip fit in the pocket's wall (0.2 over).
Hardware | Tweeter fixings: floorstander, 3 x 3.0 x 12 thread-forming screws for plastics (WN 1411 / PT K30, pan head) for the retaining cap; bookshelf, 3 x M2.5 x 8 button heads (ISO 7380, A2) into M2.5 x 4 knurled brass inserts, 3.5 or less outside diameter, for bonding with epoxy | both | 6 screws (floorstander); 6 screws and 6 inserts (bookshelf) | under 1 | any | estimate | Floorstander: into ø2.4 x 10 pilots on ø78.8 in the boss's back face. Bookshelf: inserts in ø3.6 x 5 holes on ø54 in the seat; heat-set inserts will not melt into cured resin. Measure the tweeters first (sheet 3).
Hardware | Gaskets: 0.5 mm closed-cell foam (tweeter); 1.5 mm closed-cell foam strip, 1.0 compressed (woofer and mid flanges) | both | 1 sheet and 2 m | 10 | any | estimate | The tweeter's under its flange at the throat's seat; the drivers' under their flanges in the rebates, which allow 1.0 for it.
Hardware | Driver fixings: M4 x 20 low-profile (wafer) button heads, A2, head 1.6 or less high and 8 or less across; M4 T-nuts, flange 12 or less across (or DIN 1624's 15, each flange ground flat 6.0 from its centre on the side facing the cut-out), barrel 8 / 6 / 7 or less | both | 12 a speaker (floorstander), 4 (bookshelf) | 10-20 | any | estimate | ISO 7380 button heads are 2.2 high: too tall for the trim ring's 2 mm channel. The T-nuts' flanges must stay off the cut-outs (sheet 8, F1).
Wood | Baltic birch plywood 18 mm, 5 x 5 ft sheet (B/BB) | both | 3 (floorstander), 1 (bookshelf) | 90-154 | plywood dealer, Rockler, MakerStock | estimate | Nesting: fab/out/dxf/sheets.svg (floorstander); the bookshelf's panels fit one sheet. Measure the real thickness before CNC work.
Wood | CNC cutting of the panels (2D profiles and pockets) | both | 1 job each size | 300-700 (floorstander), 150-300 (bookshelf) | local CNC cabinet or sign shop, makerspace ShopBot | estimate | Layers in each DXF name the operation. No instant online service cuts 18 mm plywood.
Wood | Gable, route A: laminated birch block, CNC-milled from the front for the insert's pocket | both | 2 | 400-1200 each | local CNC millwork or pattern shop | estimate | fab/out/step/gable-block.step. The pocket is a prism along y, so it mills from the front face with the block on its back.
Wood | Gable, route B: printed in pieces for a 218 x 123 x 220 resin printer (six for the floorstander, four for the bookshelf), SLA resin, filled and painted | both | 2 | 60-120 resin each | any | estimate | stl/gable-print/: every piece 120 or less on one side, keyed at each joint by two 4 x 20 steel pins in 4.2 holes and bonded with epoxy. Hollow to 3 mm walls with drain holes in the slicer.
Wood | Wood glue (Titebond II or III), 10 mm fluted dowels x 28 mm for the gable | both | 1 bottle, 8 dowels | 10 | any | estimate | The holes are 10 deep in the top panel and 20 in the block. A printed gable goes on with the epoxy below instead, its base scuffed: wood glue does not hold cured resin.
Printed | Waveguide insert: SLA tough (ABS-like) resin or MJF nylon, one piece from a service; or halves on a desktop resin printer | both | 2 | 150-350 (floorstander, 2.5 L solid); 40-80 (bookshelf, 0.4 L) | JLCPCB 3D, Craftcloud, Xometry | estimate | Not MDF: the floorstander's cap screws thread into 1.5 mm walls of it. One piece needs a build of 290 x 220 x 130 or more (floorstander); halves fit a 218 x 123 x 220 printer only tilted, joined by two 3 x 16 pins and epoxy. MJF prints solid; SLA solid, or hollow to 4 mm walls with two ø3 drain holes in the base face between the pins, plugged with resin (none in the waveguide, the seat or the bore). Quote the floorstander's at its volume: 1257 cm3 a half.
Printed | Driver trim rings, PETG or ASA, sprayed satin black | both | 4 (floorstander), 2 (bookshelf) | 5-10 each | printer | estimate | stl/trim-ring-*.stl: outside the rebate - 1.6, inside the surround at its glue line + 2 (PLACEHOLDER: measure the drivers and print last), a channel 8.5 to 9 wide and 2 deep in the back over the screw heads; held by three dots of neutral-cure silicone. The floorstander woofer's ring is 314 across: a 320 mm bed or a print service.
Printed | Port: tube with flange and flare collar, PETG or ASA | floorstander | 2 sets | 10-20 | printer | estimate | stl/port-tube-with-flange.stl is printed 10 mm long: push in dry, collar on from inside, measure the impedance minimum with the DATS in the sealed box, trim the inner end to 32 Hz, then bond (fab/README.md step 9).
Damping | Acoustic damping: polyester fibre fill; 10 mm wool or polyester felt; spray adhesive | both | about 300 g fill and 0.5 m2 felt (floorstander), 120 g fill (bookshelf) | 20-40 | Parts Express, any | estimate | Line the floorstander's mid chamber with the felt before its top panel goes in (glue-up G5: the divider, the shelf, the sides between them, the top's underside). Fill the woofer chamber lightly, about 150 g a speaker (60 g in the bookshelf), kept a port's diameter from the port's inner end and off the amplifier's box.
Finish | 2K high-build primer, colour coats in the flavour's colours, 2K clear | both | 1 kit | 150-300 DIY; 800-2,500 a body shop for a pair | auto-paint supplier or body shop | estimate | RAL 9016 or 9003 white; RAL 3028 for Whole's red. Approve a sprayed card.
Finish | Nutrition Facts print under the clear: water-slide decal (one-off) or a screen print in 2K ink | both | 2 | 10-60 | laser decal paper; screen printer | estimate | fab/out/marks/facts-print.pdf (floorstander, on the back); fab/out-bookshelf/marks/facts-print.pdf (bookshelf, on the right side).
Finish | Paint stencils (Oramask 813): OPEN OTHER SIDE, SHAKE WELL | both | 2 sets | 10-25 | sign shop or a Cricut | estimate | Each size its own: fab/out/marks/stencil-*.svg (floorstander, 26 and 27 mm type), fab/out-bookshelf/marks/stencil-*.svg (bookshelf, 15 mm)
Metal | Cast-letter wordmark, stainless or aluminium sheet, polished: 1.5 mm (floorstander), 1.2 mm (bookshelf) | both | 4 sets of 8 pieces | 30-80 a set | SendCutSend, OSHCut, Xometry | estimate | Each size its own: fab/out/metal/wordmark-letters.dxf (172 wide), fab/out-bookshelf/metal/wordmark-letters.dxf (98 wide). The i's dot is under some services' minimum part size.
Metal | Letter mounting: epoxy (3M DP420 or Devcon) | both | 1 | 20 | any | estimate | 1:1 placing templates, each size its own: fab/out/metal/wordmark-template-*.pdf, fab/out-bookshelf/metal/wordmark-template-*.pdf. The same epoxy bonds a printed gable to the body.
Tools | Measurement: miniDSP UMIK-1 microphone and REW (free); Dayton DATS V3 impedance meter (or a sound-card impedance jig) | both | 1 each | about 110 + 100 | Parts Express, miniDSP | researched | The microphone for the DSP's levels, delays and EQ after the first power-up (fab/out/dsp/). The DATS is required for the floorstander: the port is trimmed until the woofer's impedance minimum sits at 32 Hz (step 9, note 2.5); REW and a microphone cannot measure impedance.
Hardware | Ribbon pull loop for the insert (grosgrain, 10 mm) | both | 2 | under 1 | any | estimate | Glued in the 12 x 1.5 groove under the insert's front edge; the insert pulls out against its magnets.
Hardware | Amplifier plate screws: 4.3 x 16 self-tapping pan heads (Hypex's 4.3 x 25 kit also works), and 3 mm closed-cell EPDM tape | both | 8 or 10 a speaker (to suit the plate), 2 m tape | about 10 | Hypex, or any | estimate | Drill ø3.5 through the 13.5 left under the plate's rebate, from the plate in hand, centred in its flange (sheet 4, note 4.1): no pilot depth to guess.
Printed | Tweeter retaining cap (floorstander), MJF nylon or SLA tough resin | floorstander | 2 | 5-20 via a service | JLCPCB 3D, Craftcloud | estimate | fab/out/stl/tweeter-retainer.stl: a ring ø70 / ø58 x 18.05 (the boss's back less the measured unit's depth, 21.7 by SB's drawing) on a ø85 x 3 flange, bearing on the unit's back rim; three 3.0 x 12 thread-forming screws into the boss (sheet 9, note 3.2).
Hardware | Steel dowel pins 3 x 16 (the floorstander insert's halves, if printed in halves), 4 x 20 (the printed gable's joints) | both | 4 and 24 (floorstander), 16 (bookshelf) | under 1 | any | estimate | Bonded with epoxy in ø3.2 x 8.5 and ø4.2 x 10.5 holes (each side of the joint); dry-fit each joint closed first. The bookshelf's gable has four joints of two pins each.
Electronics | USB mini-B cable | both | 1 | about 5 | any | estimate | For Hypex Filter Design; Hypex does not supply one (fab/research/amps.md).
Wiring | 6.3 mm push-on terminals (insulated, for 2.5 and 1.5 mm2), to suit the drivers' tabs | both | 8 (floorstander), 4 (bookshelf) | under 1 | any | estimate | The woofer's and mid's leads (note 4.2); check each driver's tab width first (some take 4.8 mm).
Wiring | Crimp butt splices and heat-shrink, for 1.0 to 2.5 mm2 | both | about 12 | about 5 | any | estimate | Inside the amplifier's box: each of Hypex's harness pairs cut to about 150 mm and butt-spliced to its round cable (note 4.6).
Hardware | Non-setting sealing putty (butyl or speaker putty) | floorstander | a stick | about 5 | any | estimate | Seals the mid's cable through the divider's 12 mm hole (note 4.3).
Hardware | Letter pins: 2 mm stainless rod (optional), cut 10 long, two a letter, bonded in 2 x 10 holes | both | about 32 a pair | under 2 | any | estimate | Locate the cast letters with the 1:1 templates (note 1.6): drill through the template's pin marks, then bond letters and pins with epoxy after the clear coat.
Hardware | PU sealant (one-part polyurethane) | floorstander | a cartridge | about 8 | any | estimate | A 5 mm fillet along the corner between the mid divider's front face and the top panel's underside, run from the open front after the top panel slides in dry over the divider (glue-up G6): the mid's chamber's fourth wall.

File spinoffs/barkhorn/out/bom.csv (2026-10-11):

item | kind | qty | what | size | mass_g | usd_each | finish | supplier | price_date | source | option
left, right | cut | 4 | 18 mm Baltic birch plywood, BB/BB | 420 x 880 | 4524 | 26.8 | bark |  |  | cut file dxf/left.dxf
top | cut | 2 | 18 mm Baltic birch plywood, BB/BB | 524 x 420 | 2688 | 15.96 | bark |  |  | cut file dxf/top.dxf
bottom | cut | 2 | 18 mm Baltic birch plywood, BB/BB | 524 x 420 | 2694 | 15.96 | bark |  |  | cut file dxf/bottom.dxf
front-panel | cut | 2 | 18 mm Baltic birch plywood, BB/BB | 524 x 844 | 3879 | 32.06 | panel |  |  | cut file dxf/front-panel.dxf
back | cut | 2 | 18 mm Baltic birch plywood, BB/BB | 524 x 844 | 5040 | 32.06 | bark |  |  | cut file dxf/back.dxf
brace | cut | 2 | 18 mm Baltic birch plywood, BB/BB | 524 x 360 | 767 | 13.68 | raw |  |  | cut file dxf/brace.dxf
woofer-ring | cut | 2 | 6 mm MDF | 436 x 436 | 235 | 4.28 | ring |  |  | cut file dxf/woofer-ring.dxf
port | print | 2 | ASA, FDM (outdoor, paintable) | 89 cm3 | 95 | 14.22 | port |  |  | stl/port.stl
woofer | buy | 2 | FaitalPRO 15PR400-8 15 in woofer (treated paper cone, neodymium, 8 ohm) | 393 frame, 356 cut-out, 165 deep | 3600 | 194 | 99 dB 1 W/1 m (Faital); Xmax 5.75 mm (6 by another source) | Thomann (US storefront; EUR 198 in the EU) | 2026-10-10 | https://www.thomannmusic.com/faitalpro_15pr400_8_ohms.htm
amp-plate | buy | 2 | Hypex FusionAmp FA122 DSP plate amplifier, 2 x 125 W into 4 ohm | 315 x 120 x 55 plate, 291 x 96 recess | 815 | 422.4 |  | Parts Express 221-006 | 2026-10-08 | https://www.hypex.nl/
waveguide | cast | 2 | Tinted polyurethane casting resin, translucent | 1513 cm3, 643 x 250 x 302 | 1664 | 521.55 | horn |  |  | step/waveguide.step
waveguide-cap | cast | 2 | Tinted polyurethane casting resin, translucent | 117 cm3, 158 x 65 x 158 | 129 | 135.16 | horn |  |  | step/waveguide-cap.step
hf | buy | 2 | BMS 4550-16 compression driver, 1 in exit, polyester diaphragm, 16 ohm | 123 across, 52 deep, 2 x M6 on 76.2 | 2250 | 154 | 113 dB 1 W/1 m on a horn; BMS recommends crossing at 800 Hz or above | Toutlehautparleur (EUR 142) | 2026-10-10 | https://en.toutlehautparleur.com/compression-driver-bms-4550-16-ohm-1-inch-exit.html
rod-1, rod-2 | lathe | 4 | Stainless steel 304 | 20 x 20 x 125 | 72 | 16.5 | rod |  |  | step/rod-1.step
rod-3 | lathe | 2 | Stainless steel 304 | 20 x 20 x 162 | 95 | 26.94 | rod |  |  | step/rod-3.step
bark | buy | 4 | Bark for laminating, a square metre: paper birch (Betula papyrifera) sheet from fallen or felled trees, or a smooth-barked gum's shed bark pressed flat (or a UV-printed veneer of it); approve a sample board first |  |  |  |  | a bark craft supplier | 2026-10-10
woofer-fixings | buy | 2 | M6 x 25 button heads (A2) with M6 T-nuts, a set of 8 (the 15PR400's eight holes on 375) |  |  |  |  | any | 2026-10-10
hf-fixings | buy | 2 | M6 x 25 socket caps with washers (the compression driver to the horn's flange), a pair |  |  |  |  | any | 2026-10-10
gasket | buy | 4 | 1.5 mm closed-cell foam gasket strip, 1 m |  |  | 5 |  | any | 2026-10-08
damping | buy | 4 | Polyester fibre fill, 150 g |  |  | 8 |  | Parts Express, any | 2026-10-08
amp-fixings | buy | 2 | Hypex 4.3 x 16 self-tapping pan heads and 3 mm EPDM tape, a plate's set |  |  | 10 |  | Hypex, any | 2026-10-08
cable | buy | 6 | Round-sheathed speaker cable 2 x 1.5 mm2, 1 m |  |  | 2 |  | any electrical supplier | 2026-10-08
terminals | buy | 8 | 6.3 mm insulated push-on terminal |  |  | 0.5 |  | any | 2026-10-08
hf-pad | buy | 2 | Resistor L-pad for the HF channel, about -10 dB at 16 ohm (lowers the amplifier's hiss through a 113 dB driver) |  |  |  |  | any | 2026-10-10
glides | buy | 2 | Felt glides 30 mm, screw-in, a set of 4 |  |  |  |  | any | 2026-10-10
cloth-frame | cut | 2 | 6 mm MDF | 520 x 840 | 395 | 9.83 | black |  |  | cut file dxf/cloth-frame.dxf | cloth
grille-cloth | buy | 2 | Acoustically transparent speaker cloth (a knit sold for grilles), about 0.6 x 0.95 m a grille, in the finish's colour |  |  |  |  | any | 2026-10-10 |  | cloth
grille-pegs | buy | 2 | Grille pegs and cups, a set of four (push-fit; the cups in 10 mm holes 12 deep in the panel's corners) |  |  |  |  | any | 2026-10-10 |  | cloth
grille-lenticel | cut | 2 | 6 mm Baltic birch plywood, BB/BB | 521 x 841 | 1354 | 31.77 | grille-paint |  |  | cut file dxf/grille-lenticel.dxf | lenticel-grille
grille-lenticel-pegs | buy | 2 | Grille pegs and cups, a set of four (push-fit; the cups in 10 mm holes 12 deep in the panel's corners) |  |  |  |  | any | 2026-10-10 |  | lenticel-grille
grille-strips | cut | 2 | 6 mm Spotted gum-veneered plywood (a eucalypt hardwood face) | 521 x 841 | 1322 |  | grille-timber |  |  | cut file dxf/grille-strips.dxf | strip-grille
grille-strips-pegs | buy | 2 | Grille pegs and cups, a set of four (push-fit; the cups in 10 mm holes 12 deep in the panel's corners) |  |  |  |  | any | 2026-10-10 |  | strip-grille
bark-face | buy | 2 | Bark for laminating, a square metre: paper birch (Betula papyrifera) sheet from fallen or felled trees, or a smooth-barked gum's shed bark pressed flat (or a UV-printed veneer of it); approve a sample board first |  |  |  |  | a bark craft supplier | 2026-10-10 |  | bark-face
cork-face | cut | 2 | 3 mm Cork sheet, agglomerated | 523 x 843 | 201 |  | cork |  |  | cut file dxf/cork-face.dxf | cork-face

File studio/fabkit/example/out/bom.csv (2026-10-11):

item | kind | qty | what | size | mass_g | usd_each | finish | supplier | price_date | source | option
left, right | cut | 4 | 18 mm Baltic birch plywood, BB/BB | 260 x 400 | 1273 | 7.54 | birch |  |  | cut file dxf/left.dxf
top, bottom | cut | 4 | 18 mm Baltic birch plywood, BB/BB | 194 x 260 | 617 | 3.66 | birch |  |  | cut file dxf/top.dxf
baffle | cut | 2 | 18 mm Baltic birch plywood, BB/BB | 194 x 364 | 521 | 5.12 | birch |  |  | cut file dxf/baffle.dxf
back | cut | 2 | 18 mm Baltic birch plywood, BB/BB | 194 x 364 | 492 | 5.12 | birch |  |  | cut file dxf/back.dxf
waveguide | print | 2 | Tough (ABS-like) SLA resin | 202 cm3 | 233 | 78.82 | waveguide |  |  | stl/waveguide.stl
woofer | buy | 2 | SB Acoustics SB17NRX2C35-8 6.5 in Norex (paper cone) | 171 frame, 144.9 cut-out, 75 deep | 1560 | 76.7 | black Norex paper cone; bolt circle 159, 4 x 4.3 holes | Madisound | 2026-10-08 | https://sbacoustics.com/
tweeter | buy | 2 | Scan-Speak Illuminator D3004/602200 26 mm dome | 62 faceplate |  | 165 | faceplate not removable; Fs 425 to 440 Hz | Solen (CAD 222.71), Madisound | 2026-10-08 | https://www.scan-speak.dk/
amp-plate | buy | 2 | Hypex FusionAmp FA122 DSP plate amplifier, 2 x 125 W into 4 ohm | 315 x 120 x 55 plate, 291 x 96 recess | 815 | 422.4 |  | Parts Express 221-006 | 2026-10-08 | https://www.hypex.nl/
foot-1, foot-2, foot-3, foot-4 | lathe | 8 | White oak, solid | 40 x 40 x 22 | 6 | 10.63 | oak |  |  | step/foot-1.step
woofer-fixings | buy | 2 | M4 x 20 low-profile button heads (A2) with M4 T-nuts, a driver's set of 4 | M4 |  | 4 |  | any | 2026-10-08
gasket | buy | 2 | 1.5 mm closed-cell foam gasket strip, 1 m |  |  | 5 |  | any | 2026-10-08
damping | buy | 2 | Polyester fibre fill, 150 g |  |  | 8 |  | Parts Express, any | 2026-10-08
amp-fixings | buy | 2 | Hypex 4.3 x 16 self-tapping pan heads and 3 mm EPDM tape, a plate's set |  |  | 10 |  | Hypex, any | 2026-10-08
cable | buy | 2 | Round-sheathed speaker cable 2 x 1.5 mm2, 1 m |  |  | 2 |  | any electrical supplier | 2026-10-08
terminals | buy | 8 | 6.3 mm insulated push-on terminal |  |  | 0.5 |  | any | 2026-10-08

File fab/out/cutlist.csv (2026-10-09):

part | qty per speaker | qty for a pair | width mm | height mm | thickness mm | material | operations | note
front-baffle | 1 | 2 | 390.0 | 860.0 | 18 | Baltic birch plywood, B/BB, 18 mm nominal: measure the sheet first (sheet 7, M1) | cut inside; pocket 3 mm deep; pocket 9 mm deep (woofer); pocket 11.5 mm deep (mid); drill ø5.5 through (M4 T-nuts from inside; measure the frame first) | HOLD until the drivers are measured (M2, M3, sheet 7); outer face up; round the two vertical outer edges 6 mm after glue-up; cutouts and rebates sized for woofer rss315hf-4, mid mr16p-8, tweeter tw29dn-b (flush under trim rings): re-cut for other drivers
back-panel | 1 | 2 | 390.0 | 860.0 | 18 | Baltic birch plywood, B/BB, 18 mm nominal: measure the sheet first (sheet 7, M1) | cut inside; pocket 3 mm deep; pocket 4.5 mm deep (amplifier plate) | HOLD until the amplifier is measured (M5, sheet 7); outer face up (seen from behind); round the two vertical outer edges 6 mm after glue-up; the Hypex FusionAmp FA253's module goes through its 336 x 111 cutout, its plate on 3 mm EPDM tape flush in the 4.5 mm rebate; the cut-out's corners R3 (a 6 mm cutter or smaller); the plate's screw holes drilled ø3.5 through the 13.5 left under the rebate, from the plate in hand, centred in its flange; the Facts are printed on this face after the colour coat, under the clear
side | 2 | 4 | 354.0 | 860.0 | 18 | Baltic birch plywood, B/BB, 18 mm nominal: measure the sheet first (sheet 7, M1) | pocket 3 mm deep | outer face up; finish the groove across the front and back panels' edges after glue-up
top-panel | 1 | 2 | 354.0 | 354.0 | 18 | Baltic birch plywood, B/BB, 18 mm nominal: measure the sheet first (sheet 7, M1) | cut inside; drill ø10, 10 deep | upper face up, FRONT EDGE to the open front (the ø14 hole 215.5 from it and 138.5 from the back): turned round, the channel opens under the insert and the dowels miss the gable; dowels register the gable block; the tweeter cable's hole is sealed with silicone from the bay after wiring
bottom-panel | 1 | 2 | 354.0 | 354.0 | 18 | Baltic birch plywood, B/BB, 18 mm nominal: measure the sheet first (sheet 7, M1) | outline only | either face
window-brace | 1 | 2 | 354.0 | 354.0 | 18 | Baltic birch plywood, B/BB, 18 mm nominal: measure the sheet first (sheet 7, M1) | cut inside | sits at z 500 to 518, glued to all four walls
mid-shelf | 1 | 2 | 354.0 | 108.0 | 18 | Baltic birch plywood, B/BB, 18 mm nominal: measure the sheet first (sheet 7, M1) | outline only | z 572 to 590, from the baffle back to under the divider
mid-divider | 1 | 2 | 354.0 | 251.0 | 18 | Baltic birch plywood, B/BB, 18 mm nominal: measure the sheet first (sheet 7, M1) | cut inside | seen from the front (the mid chamber's side), its top edge up: the hole 57 from its left end; y 108 to 126, z 590 to 841, 1 short of the top panel (G6's PU fillet closes it); seal the wire hole after wiring
amp-box-floor | 1 | 2 | 354.0 | 108.0 | 18 | Baltic birch plywood, B/BB, 18 mm nominal: measure the sheet first (sheet 7, M1) | outline only | the amplifier box's floor, z 99.5 to 117.5, against the back
amp-box-lid | 1 | 2 | 354.0 | 108.0 | 18 | Baltic birch plywood, B/BB, 18 mm nominal: measure the sheet first (sheet 7, M1) | cut inside; then pocket 8 mm deep from the underside with amp-box-lid-underside.dxf: turn the panel over left to right (its FRONT EDGE still nearest you) and centre each pocket on its hole; cut both before the lid goes in (G2 epoxies the gland nuts into these counterbores) | the amplifier box's lid, z 252.5 to 270.5, its FRONT EDGE over the box's front; the glands and their nuts: note 4.7
amp-box-front | 1 | 2 | 354.0 | 135.0 | 18 | Baltic birch plywood, B/BB, 18 mm nominal: measure the sheet first (sheet 7, M1) | outline only | the amplifier box's front, between floor and lid, 90 in front of the back's inner face; glue and seal all round
gable-layer-01 | 1 | 2 | 398.0 | 398.0 | 18 | Baltic birch plywood, B/BB, 18 mm nominal: measure the sheet first (sheet 7, M1) | outline only | gable glue-up, layer 1 of 11 (z 860 to 878); centre on y = 195
gable-layer-02 | 1 | 2 | 398.0 | 351.2 | 18 | Baltic birch plywood, B/BB, 18 mm nominal: measure the sheet first (sheet 7, M1) | outline only | gable glue-up, layer 2 of 11 (z 878 to 896); centre on y = 195
gable-layer-03 | 1 | 2 | 398.0 | 304.4 | 18 | Baltic birch plywood, B/BB, 18 mm nominal: measure the sheet first (sheet 7, M1) | outline only | gable glue-up, layer 3 of 11 (z 896 to 914); centre on y = 195
gable-layer-04 | 1 | 2 | 398.0 | 257.6 | 18 | Baltic birch plywood, B/BB, 18 mm nominal: measure the sheet first (sheet 7, M1) | outline only | gable glue-up, layer 4 of 11 (z 914 to 932); centre on y = 195
gable-layer-05 | 1 | 2 | 398.0 | 210.8 | 18 | Baltic birch plywood, B/BB, 18 mm nominal: measure the sheet first (sheet 7, M1) | outline only | gable glue-up, layer 5 of 11 (z 932 to 950); centre on y = 195
gable-layer-06 | 1 | 2 | 398.0 | 164.0 | 18 | Baltic birch plywood, B/BB, 18 mm nominal: measure the sheet first (sheet 7, M1) | outline only | gable glue-up, layer 6 of 11 (z 950 to 968); centre on y = 195
gable-layer-07 | 1 | 2 | 398.0 | 117.2 | 18 | Baltic birch plywood, B/BB, 18 mm nominal: measure the sheet first (sheet 7, M1) | outline only | gable glue-up, layer 7 of 11 (z 968 to 986); centre on y = 195
gable-layer-08 | 1 | 2 | 398.0 | 70.4 | 18 | Baltic birch plywood, B/BB, 18 mm nominal: measure the sheet first (sheet 7, M1) | outline only | gable glue-up, layer 8 of 11 (z 986 to 1004); centre on y = 195
gable-layer-09 | 1 | 2 | 398.0 | 23.6 | 18 | Baltic birch plywood, B/BB, 18 mm nominal: measure the sheet first (sheet 7, M1) | outline only | gable glue-up, layer 9 of 11 (z 1004 to 1022); centre on y = 195
gable-layer-10 | 1 | 2 | 398.0 | 16.0 | 18 | Baltic birch plywood, B/BB, 18 mm nominal: measure the sheet first (sheet 7, M1) | outline only | gable glue-up, layer 10 of 11 (z 1022 to 1040); centre on y = 195
gable-layer-11 | 1 | 2 | 398.0 | 16.0 | 18 | Baltic birch plywood, B/BB, 18 mm nominal: measure the sheet first (sheet 7, M1) | outline only | gable glue-up, layer 11 of 11 (z 1040 to 1058); centre on y = 195

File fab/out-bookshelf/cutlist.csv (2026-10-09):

part | qty per speaker | qty for a pair | width mm | height mm | thickness mm | material | operations | note
front-baffle | 1 | 2 | 220.0 | 484.0 | 18 | Baltic birch plywood, B/BB, 18 mm nominal: measure the sheet first (sheet 7, M1) | cut inside; pocket 3 mm deep; pocket 10.5 mm deep (woofer); drill ø5.5 through (M4 T-nuts from inside; measure the frame first) | HOLD until the drivers are measured (M2, sheet 7); outer face up; round the two vertical outer edges 4 mm after glue-up; cutouts and rebates sized for woofer sb17nrx2c35-8, tweeter d3004-602200 (flush under trim rings): re-cut for other drivers
back-panel | 1 | 2 | 220.0 | 484.0 | 18 | Baltic birch plywood, B/BB, 18 mm nominal: measure the sheet first (sheet 7, M1) | cut inside; pocket 3 mm deep; pocket 4.5 mm deep (amplifier plate) | HOLD until the amplifier is measured (M4, sheet 7); outer face up (seen from behind); round the two vertical outer edges 4 mm after glue-up; the Hypex FusionAmp FA122's module goes through its 96 x 291 cutout, its plate on 3 mm EPDM tape flush in the 4.5 mm rebate; the cut-out's corners R3 (a 6 mm cutter or smaller); the plate's screw holes drilled ø3.5 through the 13.5 left under the rebate, from the plate in hand, centred in its flange; the Facts go on the right side
side | 2 | 4 | 184.0 | 484.0 | 18 | Baltic birch plywood, B/BB, 18 mm nominal: measure the sheet first (sheet 7, M1) | pocket 3 mm deep | outer face up; finish the groove across the front and back panels' edges after glue-up; the Facts are printed on the right side's outer face
top-panel | 1 | 2 | 184.0 | 184.0 | 18 | Baltic birch plywood, B/BB, 18 mm nominal: measure the sheet first (sheet 7, M1) | cut inside; drill ø10, 10 deep | upper face up, FRONT EDGE to the open front (the ø14 hole 119 from it and 65 from the back): turned round, the channel opens under the insert and the dowels miss the gable; dowels register the gable block; the tweeter cable's hole is sealed with silicone from the bay after wiring
bottom-panel | 1 | 2 | 184.0 | 184.0 | 18 | Baltic birch plywood, B/BB, 18 mm nominal: measure the sheet first (sheet 7, M1) | outline only | either face
amp-box-floor | 1 | 2 | 184.0 | 88.0 | 18 | Baltic birch plywood, B/BB, 18 mm nominal: measure the sheet first (sheet 7, M1) | outline only | the amplifier box's floor, z 61.5 to 79.5, against the back
amp-box-lid | 1 | 2 | 184.0 | 88.0 | 18 | Baltic birch plywood, B/BB, 18 mm nominal: measure the sheet first (sheet 7, M1) | cut inside; then pocket 8 mm deep from the underside with amp-box-lid-underside.dxf: turn the panel over left to right (its FRONT EDGE still nearest you) and centre each pocket on its hole; cut both before the lid goes in (G2 epoxies the gland nuts into these counterbores) | the amplifier box's lid, z 390.5 to 408.5, its FRONT EDGE over the box's front; the glands and their nuts: note 4.6
amp-box-front | 1 | 2 | 184.0 | 311.0 | 18 | Baltic birch plywood, B/BB, 18 mm nominal: measure the sheet first (sheet 7, M1) | outline only | the amplifier box's front, between floor and lid, 70 in front of the back's inner face; glue and seal all round
gable-layer-01 | 1 | 2 | 228.0 | 228.0 | 18 | Baltic birch plywood, B/BB, 18 mm nominal: measure the sheet first (sheet 7, M1) | outline only | gable glue-up, layer 1 of 7 (z 484 to 502); centre on y = 110
gable-layer-02 | 1 | 2 | 228.0 | 181.2 | 18 | Baltic birch plywood, B/BB, 18 mm nominal: measure the sheet first (sheet 7, M1) | outline only | gable glue-up, layer 2 of 7 (z 502 to 520); centre on y = 110
gable-layer-03 | 1 | 2 | 228.0 | 134.4 | 18 | Baltic birch plywood, B/BB, 18 mm nominal: measure the sheet first (sheet 7, M1) | outline only | gable glue-up, layer 3 of 7 (z 520 to 538); centre on y = 110
gable-layer-04 | 1 | 2 | 228.0 | 87.6 | 18 | Baltic birch plywood, B/BB, 18 mm nominal: measure the sheet first (sheet 7, M1) | outline only | gable glue-up, layer 4 of 7 (z 538 to 556); centre on y = 110
gable-layer-05 | 1 | 2 | 228.0 | 40.8 | 18 | Baltic birch plywood, B/BB, 18 mm nominal: measure the sheet first (sheet 7, M1) | outline only | gable glue-up, layer 5 of 7 (z 556 to 574); centre on y = 110
gable-layer-06 | 1 | 2 | 228.0 | 14.0 | 18 | Baltic birch plywood, B/BB, 18 mm nominal: measure the sheet first (sheet 7, M1) | outline only | gable glue-up, layer 6 of 7 (z 574 to 592); centre on y = 110
gable-layer-07 | 1 | 2 | 228.0 | 14.0 | 18 | Baltic birch plywood, B/BB, 18 mm nominal: measure the sheet first (sheet 7, M1) | outline only | gable glue-up, layer 7 of 7 (z 592 to 610); centre on y = 110

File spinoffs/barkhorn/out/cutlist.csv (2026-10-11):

part | qty per set | width mm | height mm | thickness mm | material | through cuts | pockets (depth mm) | underside pockets (depth mm) | not in the 2D file
left | 2 | 420.0 | 880.0 | 18 | baltic-birch | 0
right | 2 | 420.0 | 880.0 | 18 | baltic-birch | 0
top | 2 | 524.0 | 420.0 | 18 | baltic-birch | 1 | 15
bottom | 2 | 524.0 | 420.0 | 18 | baltic-birch | 0
front-panel | 2 | 524.0 | 844.0 | 18 | baltic-birch | 10 | 11
back | 2 | 524.0 | 844.0 | 18 | baltic-birch | 1 | 4.5
brace | 2 | 524.0 | 360.0 | 18 | baltic-birch | 1
woofer-ring | 2 | 436.0 | 436.0 | 6 | mdf | 1 |  | 4
cloth-frame | 2 | 520.0 | 840.0 | 6 | mdf | 2
grille-lenticel | 2 | 521.0 | 841.0 | 6 | baltic-birch | 394
grille-strips | 2 | 521.0 | 841.0 | 6 | spotted-gum-ply | 124
cork-face | 2 | 523.0 | 843.0 | 3 | cork | 2

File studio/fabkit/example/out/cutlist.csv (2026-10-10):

part | qty per set | width mm | height mm | thickness mm | material | through cuts | pockets (depth mm) | underside pockets (depth mm) | not in the 2D file
left | 2 | 260.0 | 400.0 | 18 | baltic-birch | 0
right | 2 | 260.0 | 400.0 | 18 | baltic-birch | 0
top | 2 | 194.0 | 260.0 | 18 | baltic-birch | 0
bottom | 2 | 194.0 | 260.0 | 18 | baltic-birch | 0
baffle | 2 | 194.0 | 364.0 | 18 | baltic-birch | 6 | 5 7.5
back | 2 | 194.0 | 364.0 | 18 | baltic-birch | 1 | 4.5

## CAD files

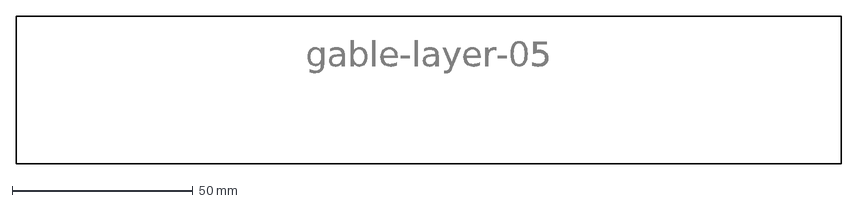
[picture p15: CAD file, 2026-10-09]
fab/out-bookshelf/dxf/gable-layer-05.dxf
gable-layer-05

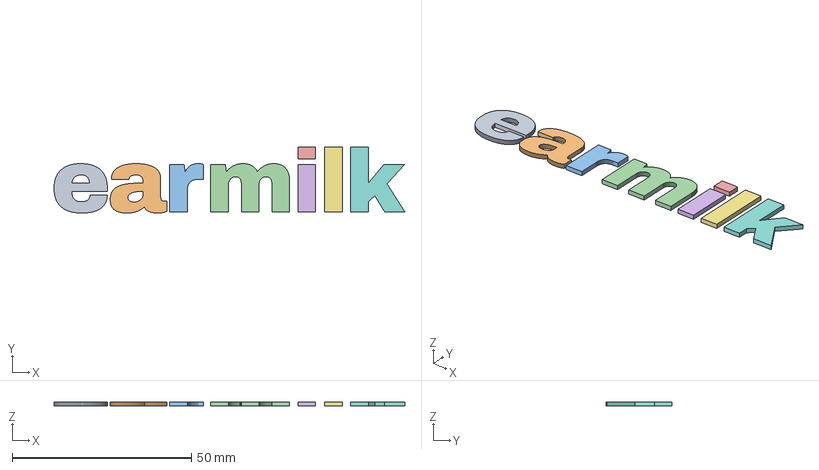
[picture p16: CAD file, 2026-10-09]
fab/out-bookshelf/metal/wordmark-letters.step
97.8 x 18.4 x 1.20 mm

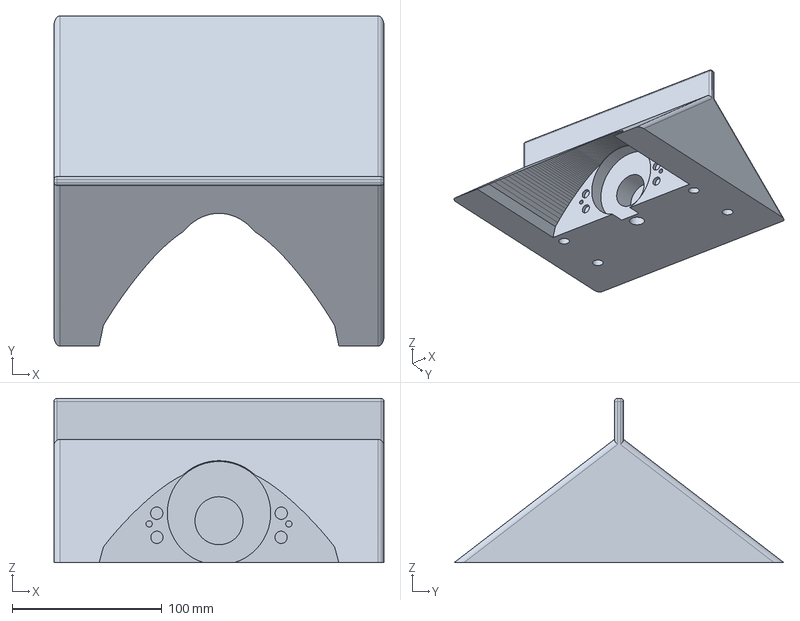
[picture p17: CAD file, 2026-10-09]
fab/out-bookshelf/step/gable-block.step
220.0 x 220.0 x 109.6 mm

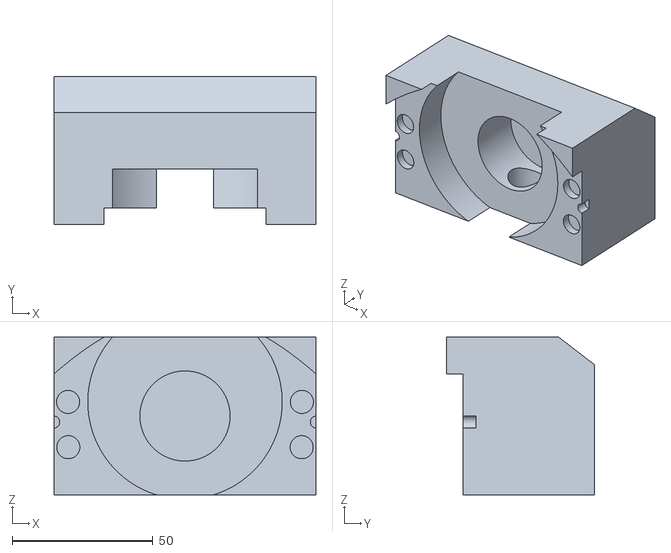
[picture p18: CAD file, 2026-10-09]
fab/out-bookshelf/stl/connector-test-bay.stl
93.0 x 52.7 x 56.0

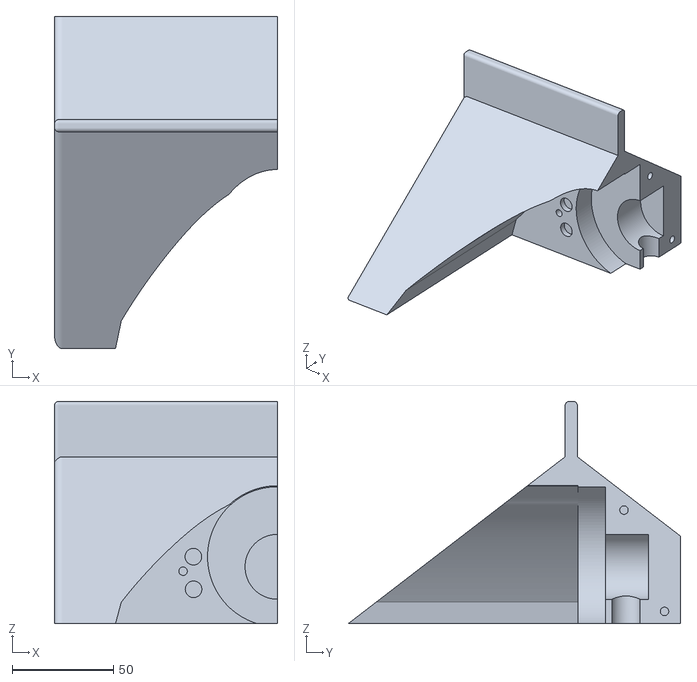
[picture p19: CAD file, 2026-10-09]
fab/out-bookshelf/stl/gable-print/gable-print-front-left.stl
110.0 x 164.0 x 109.6

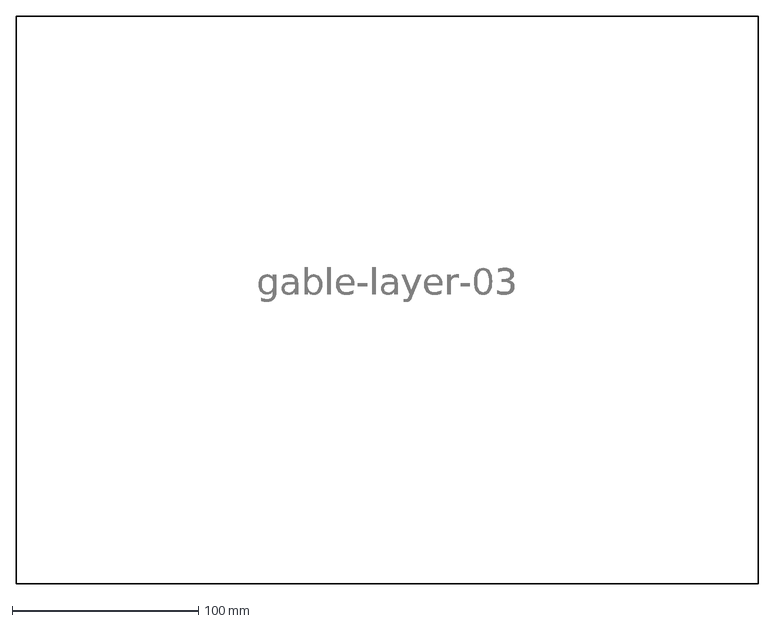
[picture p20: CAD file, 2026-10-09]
fab/out/dxf/gable-layer-03.dxf
gable-layer-03

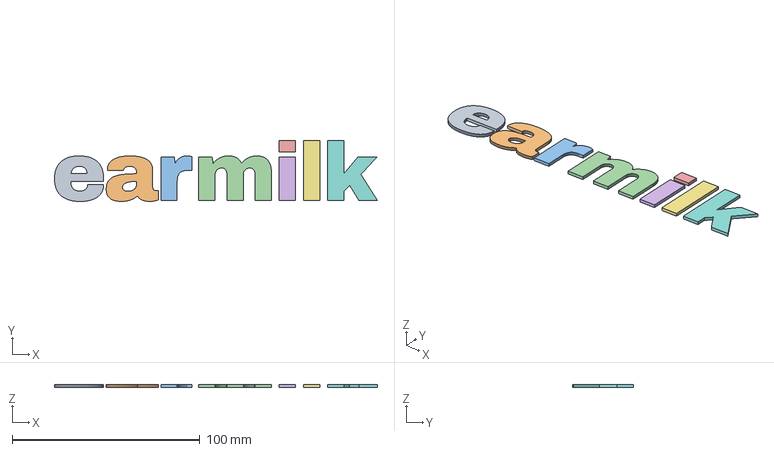
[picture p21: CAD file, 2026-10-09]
fab/out/metal/wordmark-letters.step
172.2 x 32.5 x 1.50 mm

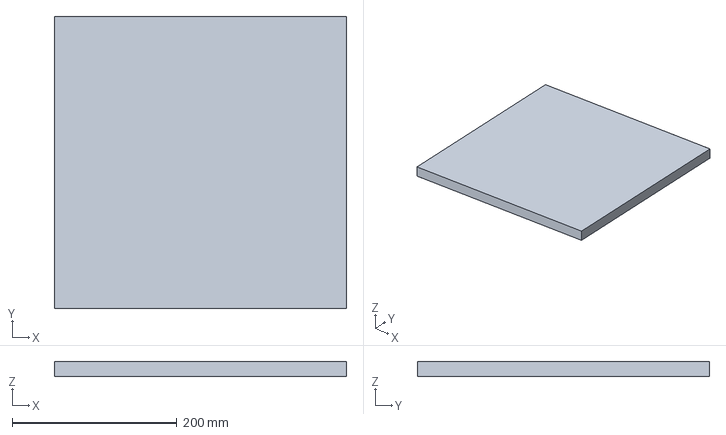
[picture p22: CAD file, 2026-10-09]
fab/out/step/bottom-panel.step
354.0 x 354.0 x 18.0 mm

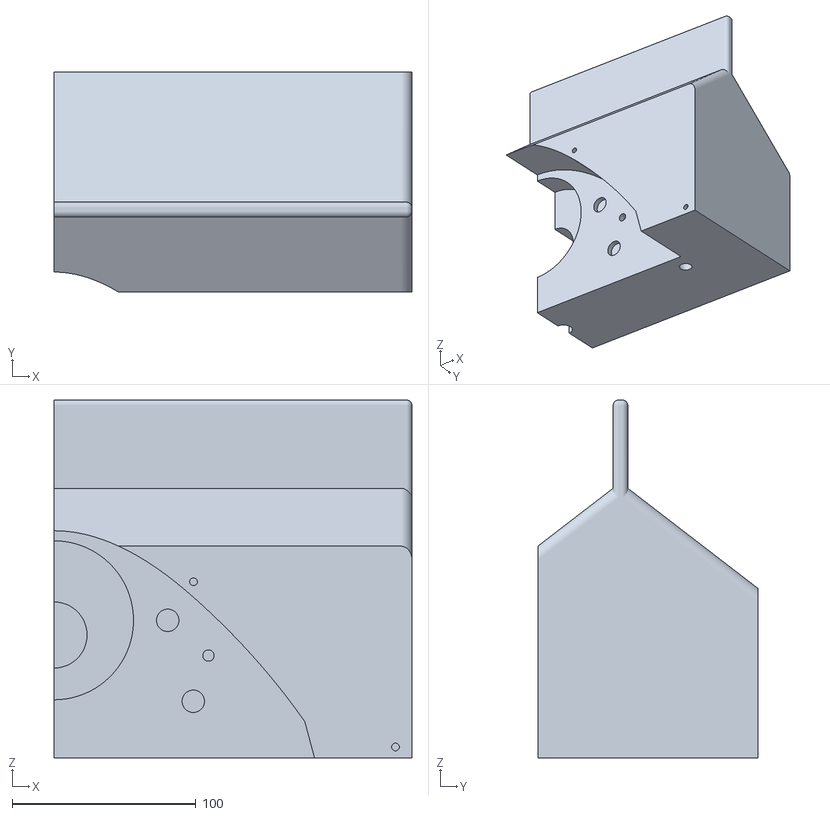
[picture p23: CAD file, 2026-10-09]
fab/out/stl/gable-print/gable-print-mid-right.stl
195.0 x 120.0 x 195.0

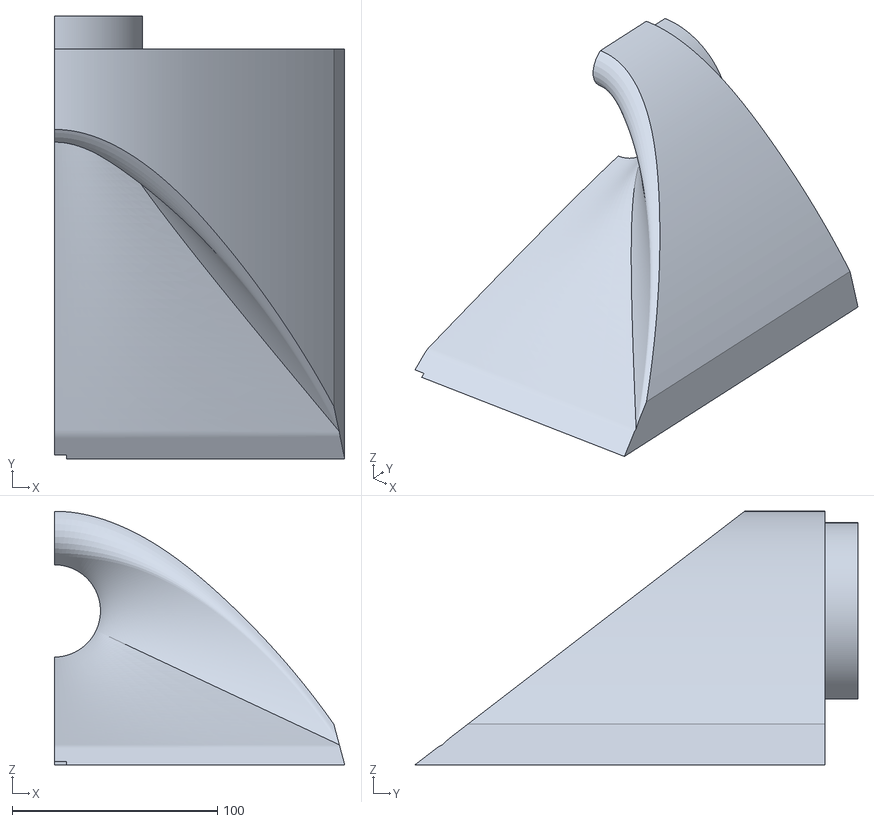
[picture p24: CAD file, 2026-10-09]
fab/out/stl/waveguide-insert-right.stl
141.6 x 216.0 x 123.6

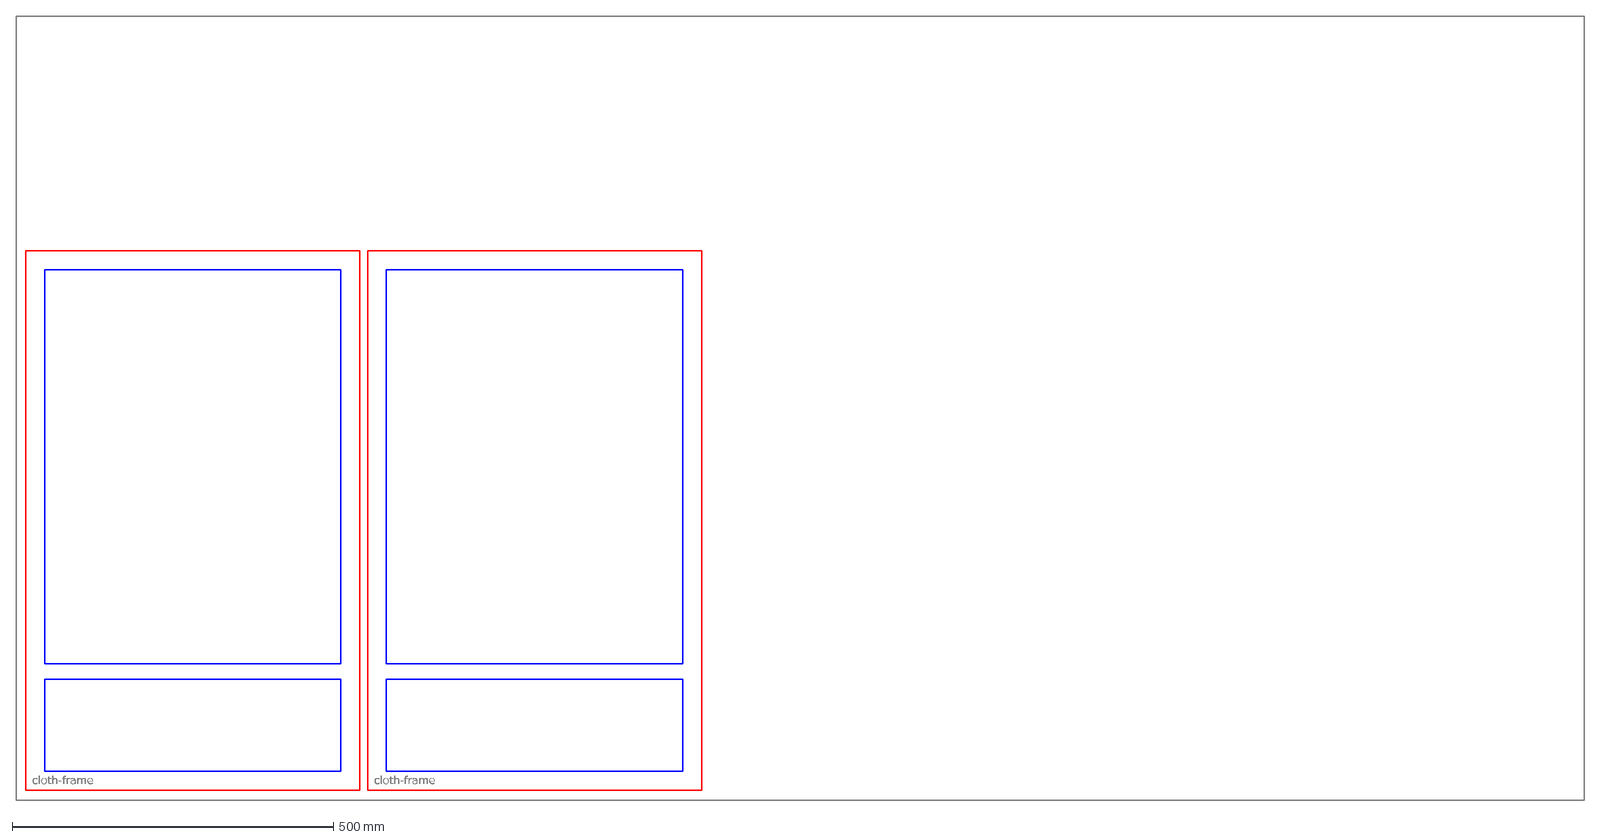
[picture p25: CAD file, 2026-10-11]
spinoffs/barkhorn/out/dxf/nest-mdf-6-cloth-1.dxf
cloth-frame

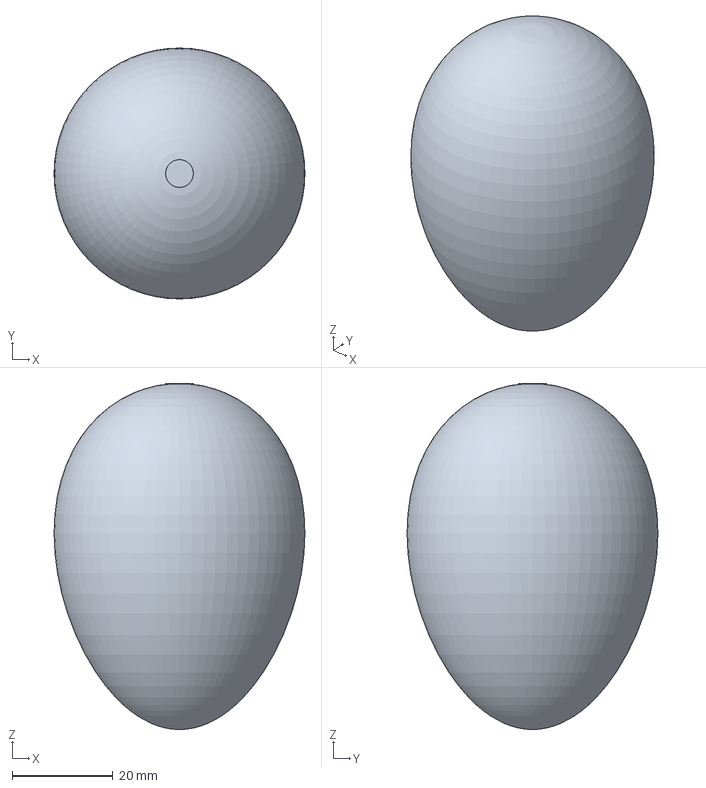
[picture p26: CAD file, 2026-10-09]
spinoffs/earnest/out/step/knob-white.step
49.9 x 49.9 x 68.8 mm

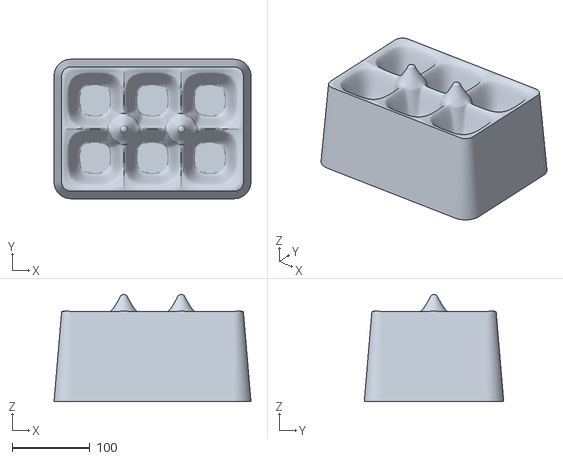
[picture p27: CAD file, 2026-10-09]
spinoffs/earnest/out/stl/crate-6.stl
253.6 x 179.6 x 138.0

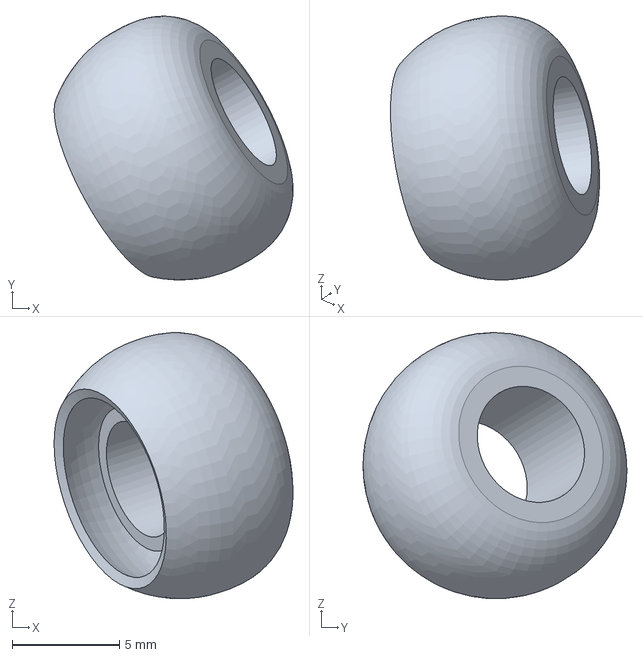
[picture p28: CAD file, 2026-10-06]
spinoffs/earwig/out/step/tip-r.step
11.1 x 12.3 x 12.4 mm

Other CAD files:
spinoffs/earworm/out/step/plug.step
studio/fabkit/example/out/dxf/left.dxf
fab/out-bookshelf/dxf/side.dxf
fab/out-bookshelf/step/amp-box-lid.step
fab/out-bookshelf/dxf/amp-box-floor.dxf
fab/out-bookshelf/dxf/amp-box-front.dxf
fab/out-bookshelf/dxf/amp-box-lid-underside.dxf
fab/out-bookshelf/dxf/amp-box-lid.dxf
fab/out-bookshelf/dxf/back-panel.dxf
fab/out-bookshelf/dxf/bottom-panel.dxf
fab/out-bookshelf/dxf/front-baffle.dxf
fab/out-bookshelf/dxf/gable-layer-01.dxf
fab/out-bookshelf/dxf/gable-layer-02.dxf
fab/out-bookshelf/dxf/gable-layer-03.dxf
fab/out-bookshelf/dxf/gable-layer-04.dxf
fab/out-bookshelf/dxf/gable-layer-06.dxf
fab/out-bookshelf/dxf/gable-layer-07.dxf
fab/out-bookshelf/dxf/sheet-1.dxf
fab/out-bookshelf/dxf/top-panel.dxf
fab/out-bookshelf/metal/wordmark-letters.dxf
fab/out-bookshelf/metal/wordmark-letters.stl
fab/out-bookshelf/step/amp-box-floor.step
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

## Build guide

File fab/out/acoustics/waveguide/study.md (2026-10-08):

# Waveguide study

Half-angles in degrees to -6 dB from the horizontal axis (the listener); DI in dB; peak: the vertical angle of the loudest direction (+ up). The mid: a piston of its Sd in an infinite baffle.

| f (Hz) | mid: H half-angle, DI | A: H / up / down, DI, peak | B: H / up / down, DI, peak | B6: H / up / down, DI, peak | C: H / up / down, DI, peak | C22: H / up / down, DI, peak | C22a8: H / up / down, DI, peak | C6: H / up / down, DI, peak |
|---|---|---|---|---|---|---|---|---|
| 1250 | >90, 4.4 | 79 / >90 / 68, 4.4, +70 | >90 / >90 / 71, 2.1, +60 | >90 / >90 / 71, 2.5, +60 | >90 / >90 / 65, 1.8, +45 | >90 / >90 / 63, 2.3, +45 | >90 / >90 / 63, 2.1, +45 | >90 / >90 / 67, 2.0, +50 |
| 2000 | 80, 6.6 | 74 / >90 / 74, 3.6, +30 | 52 / 63 / 27, 7.0, +20 | 53 / 64 / 27, 6.8, +20 | 40 / 49 / 46, 8.6, +15 | 40 / 50 / 47, 8.7, +15 | 40 / 50 / 46, 8.6, +15 | 41 / 50 / 45, 8.6, +15 |
| 3150 | 39, 11.0 | 43 / 57 / 36, 8.3, +20 | 42 / 41 / 34, 9.7, +15 | 41 / 42 / 34, 9.7, +15 | 42 / 35 / 31, 10.7, +15 | 41 / 34 / 30, 11.2, +10 | 41 / 35 / 30, 11.0, +10 | 42 / 36 / 32, 10.6, +15 |
| 5000 | 23, 14.8 | 37 / 36 / 30, 11.0, +10 | 37 / 24 / 29, 12.2, +5 | 37 / 24 / 28, 12.1, +5 | 35 / 17 / 28, 12.8, +0 | 32 / 17 / 27, 13.4, +0 | 32 / 18 / 27, 13.4, +0 | 36 / 19 / 28, 12.6, +5 |
| 8000 | 15, 19.0 | 34 / 22 / 23, 12.6, +5 | 36 / 16 / 23, 12.9, +0 | 34 / 13 / 24, 13.4, +0 | 38 / 25 / 19, 12.7, +0 | 31 / 16 / 19, 14.2, +0 | 31 / 19 / 20, 14.1, +0 | 36 / 12 / 21, 13.4, +0 |

- **A**: throat y ?, mouth 207.3 wide, s [11.9, 137.2], depths H 68.5 up 31.2 down 113.1, eave angle 19.2; axis below the vertical peak (dB): 1250 Hz 1.86, 2000 Hz 3.96, 3150 Hz 1.99, 5000 Hz 1.14, 8000 Hz 0.46
- **B**: throat y ?, mouth 235.9 wide, s [12.9, 171.1], depths H 65.5 up 29.5 down 138.1, eave angle 23.4; axis below the vertical peak (dB): 1250 Hz 4.5, 2000 Hz 1.49, 3150 Hz 0.85, 5000 Hz 0.12, 8000 Hz 0.0
- **B6**: throat y ?, mouth 266.2 wide, s [12.7, 169.0], depths H 76.3 up 30.4 down 143.2, eave angle 23.4; axis below the vertical peak (dB): 1250 Hz 4.07, 2000 Hz 1.66, 3150 Hz 0.79, 5000 Hz 0.16, 8000 Hz 0.0
- **C**: throat y ?, mouth 280.9 wide, s [13.0, 193.7], depths H 78.5 up 37.0 down 164.1, eave angle 23.1; axis below the vertical peak (dB): 1250 Hz 5.42, 2000 Hz 0.38, 3150 Hz 0.8, 5000 Hz 0.0, 8000 Hz 0.0
- **C22**: throat y ?, mouth 281.6 wide, s [12.7, 200.7], depths H 78.5 up 32.7 down 164.1, eave angle 23.1; axis below the vertical peak (dB): 1250 Hz 5.07, 2000 Hz 0.44, 3150 Hz 0.61, 5000 Hz 0.0, 8000 Hz 0.0
- **C22a8**: throat y ?, mouth 276.0 wide, s [12.9, 199.7], depths H 78.5 up 34.1 down 164.1, eave angle 23.1; axis below the vertical peak (dB): 1250 Hz 5.25, 2000 Hz 0.44, 3150 Hz 0.67, 5000 Hz 0.0, 8000 Hz 0.0
- **C6**: throat y ?, mouth 317.4 wide, s [12.8, 190.3], depths H 91.4 up 38.2 down 170.1, eave angle 23.1; axis below the vertical peak (dB): 1250 Hz 5.18, 2000 Hz 0.46, 3150 Hz 0.87, 5000 Hz 0.02, 8000 Hz 0.0

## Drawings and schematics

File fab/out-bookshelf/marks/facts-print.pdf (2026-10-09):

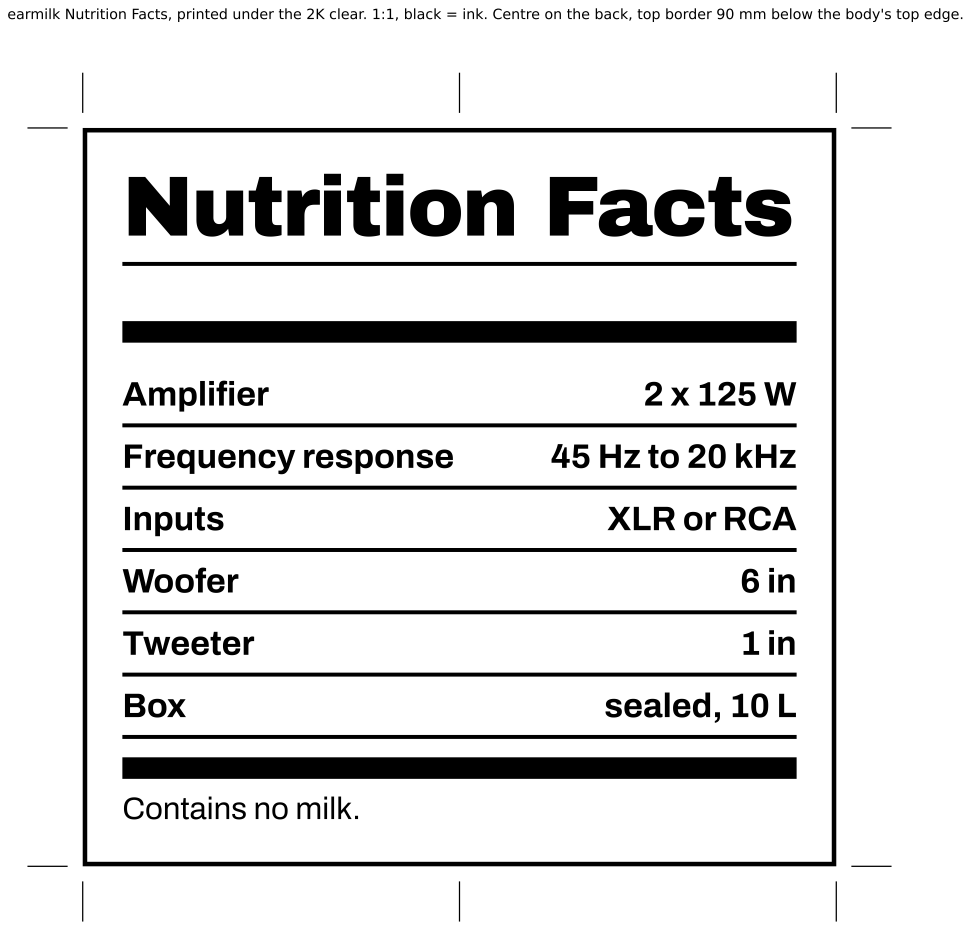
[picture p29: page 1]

earmilk Nutrition Facts, printed under the 2K clear. 1:1, black = ink. Centre on the back, top border 90 mm below the body's top edge.

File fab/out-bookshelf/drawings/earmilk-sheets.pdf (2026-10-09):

T

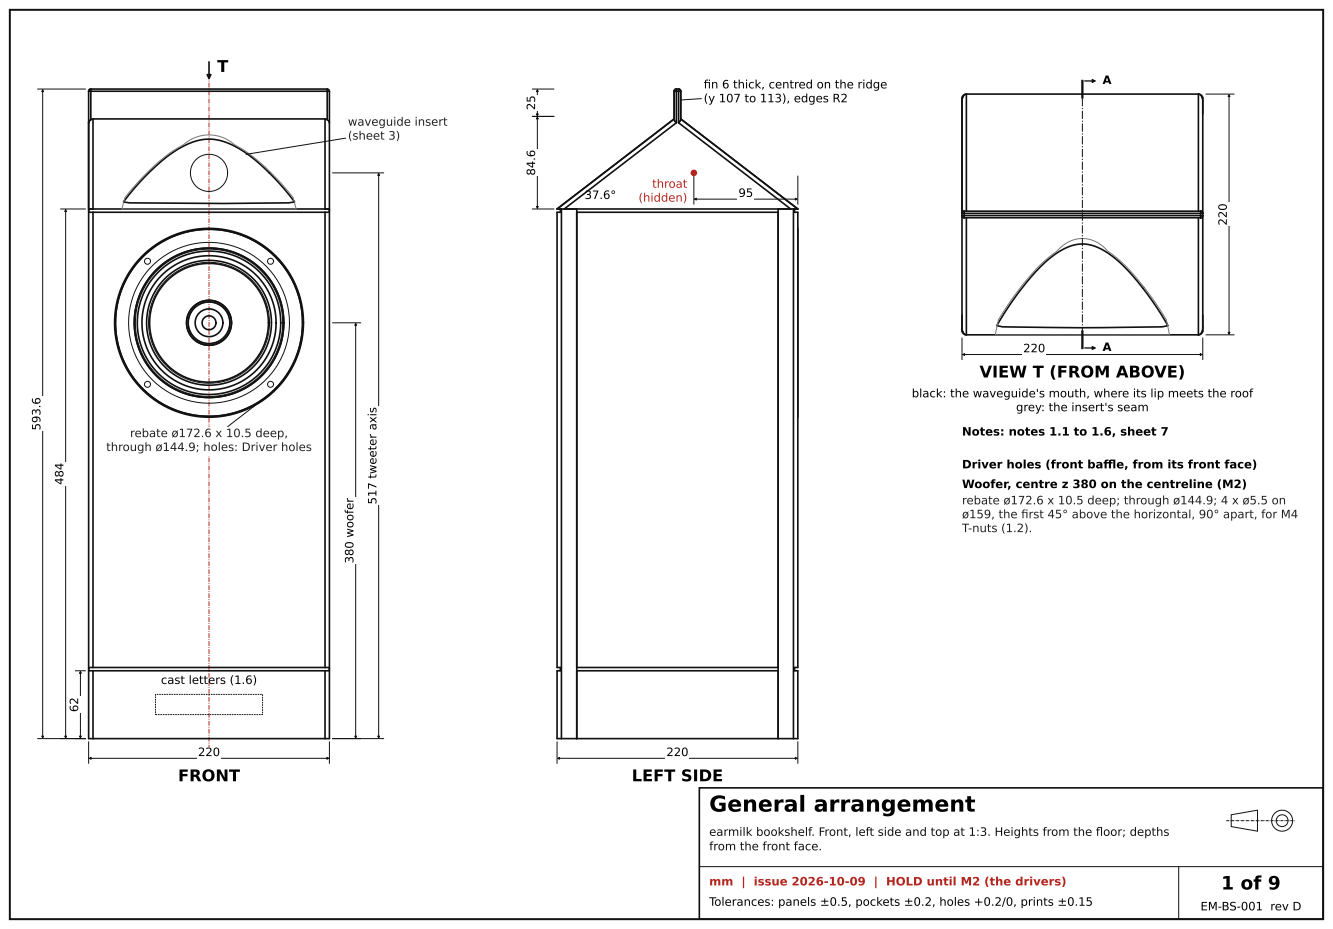
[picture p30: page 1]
General arrangement; FRONT; LEFT SIDE; 380 woofer; 517 tweeter axis; cast letters (1.6); throat; (hidden); rebate ø172.6 x 10.5 deep,; Notes: notes 1.1 to 1.6, sheet 7; waveguide insert (sheet 3)

fin 6 thick, centred on the ridge
(y 107 to 113), edges R2

VIEW T (FROM ABOVE)

black: the waveguide's mouth, where its lip meets the roof

grey: the insert's seam

through ø144.9; holes: Driver holes

Driver holes (front baffle, from its front face)

Woofer, centre z 380 on the centreline (M2)
rebate ø172.6 x 10.5 deep; through ø144.9; 4 x ø5.5 on
ø159, the first 45° above the horizontal, 90° apart, for M4
T-nuts (1.2).

earmilk bookshelf. Front, left side and top at 1:3. Heights from the floor; depths
from the front face.

mm | issue 2026-10-09 | HOLD until M2 (the drivers)
Tolerances: panels ±0.5, pockets ±0.2, holes +0.2/0, prints ±0.15

EM-BS-001 rev D

C

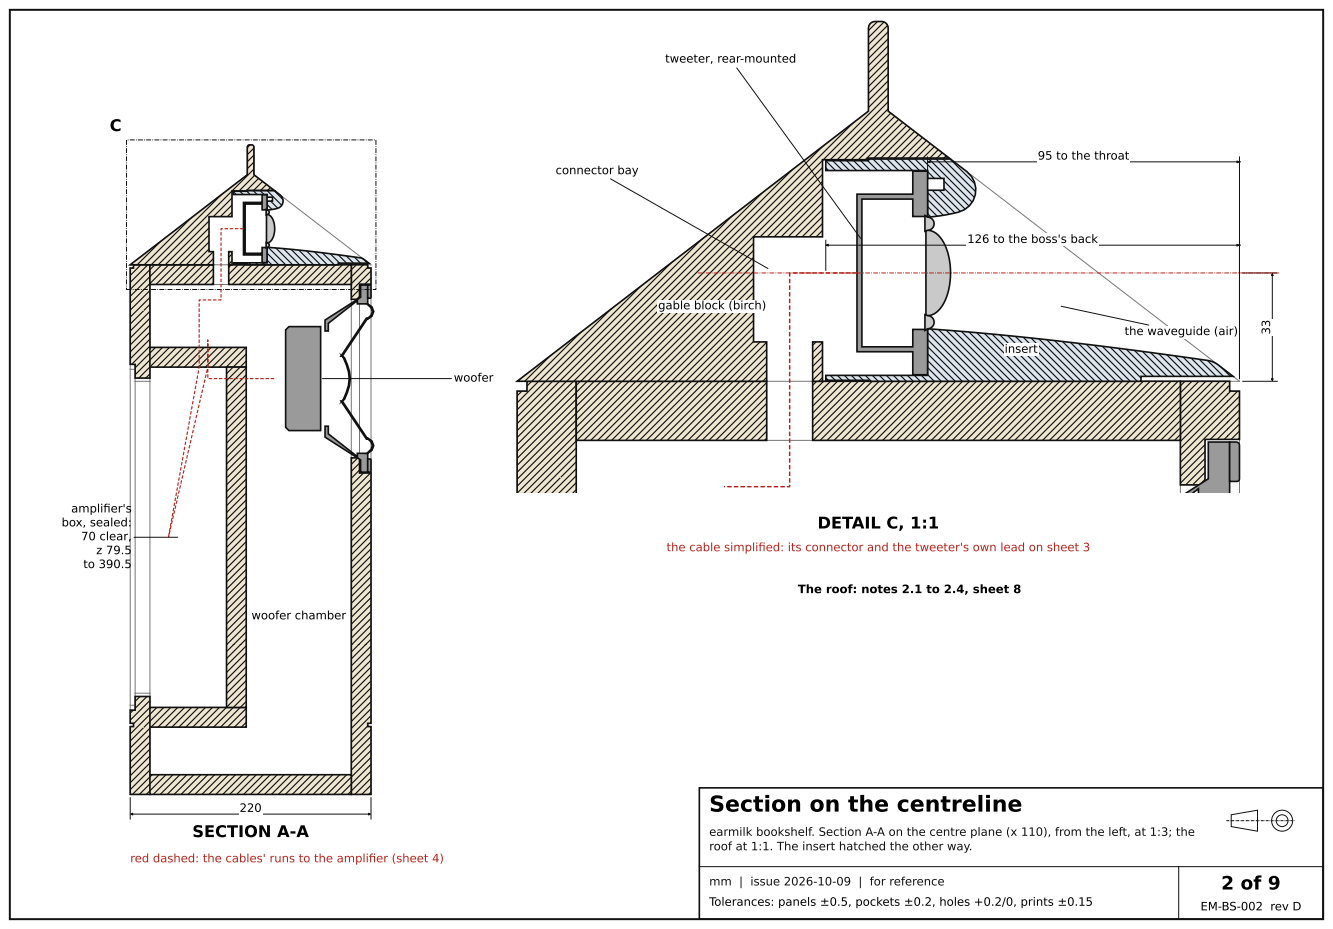
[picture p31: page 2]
Section; on the centreline; earmilk bookshelf. Section; A-A on the centre plane (x 110), from the left, at 1:3; the; mm | issue 2026-10-09 |; for reference; SECTION A-A; woofer chamber; DETAIL C, 1:1; woofer; amplifier's; box, sealed: 70 clear, z 79.5 to 390.5; connector bay; insert

tweeter, rear-mounted

95 to the throat

126 to the boss's back

gable block (birch)

the waveguide (air)

the cable simplified: its connector and the tweeter's own lead on sheet 3

The roof: notes 2.1 to 2.4, sheet 8

roof at 1:1. The insert hatched the other way.

red dashed: the cables' runs to the amplifier (sheet 4)

EM-BS-002 rev D

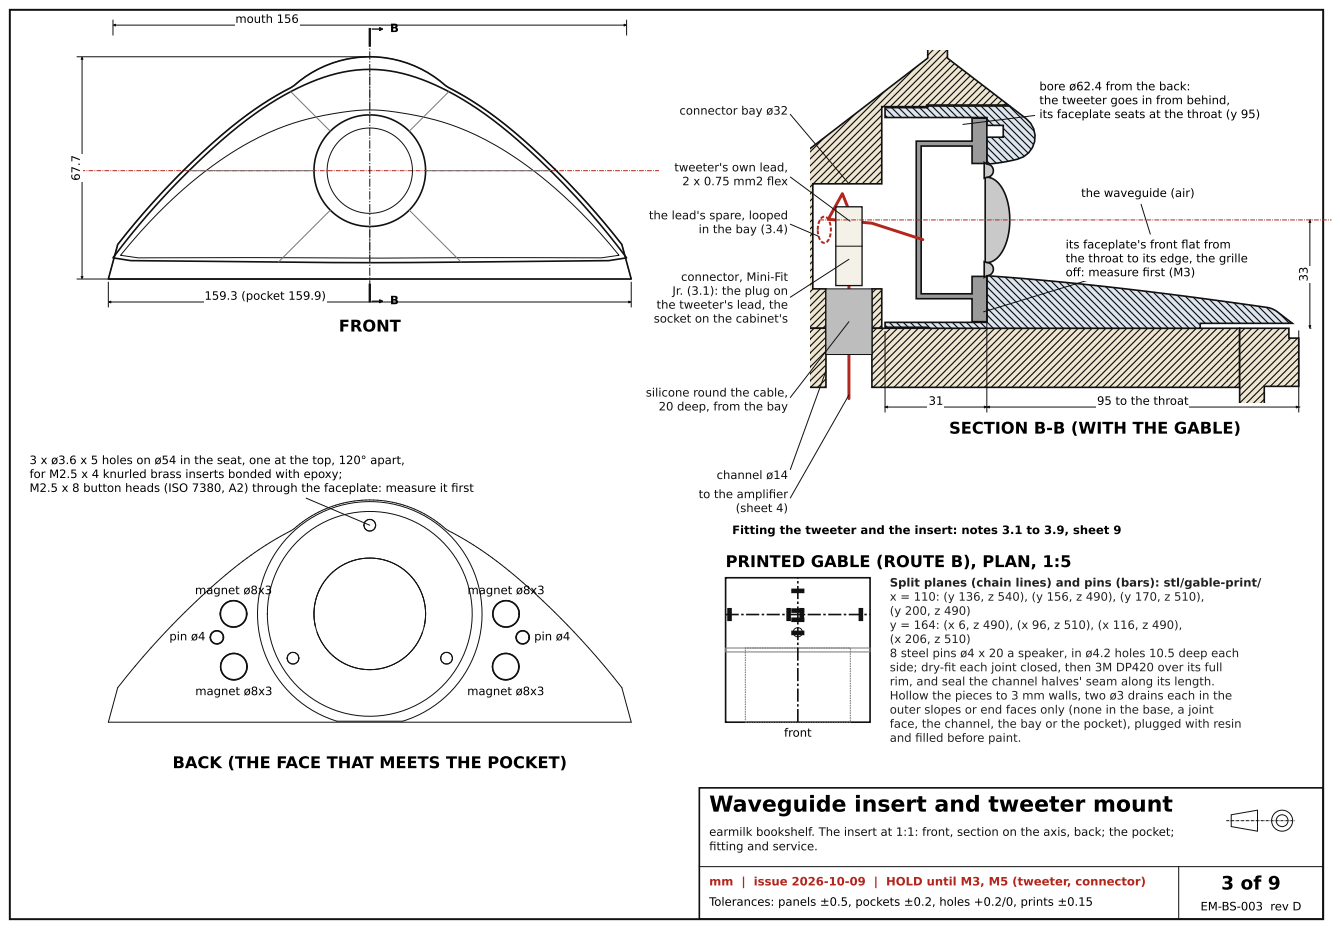
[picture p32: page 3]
95 to the throat; 159.3 (pocket 159.9); mouth 156; FRONT; magnet ø8x3; pin ø4; front; connector bay ø32; (sheet 4)

bore ø62.4 from the back:
the tweeter goes in from behind,
its faceplate seats at the throat (y 95)

tweeter's own lead,
2 x 0.75 mm2 flex

the waveguide (air)

the lead's spare, looped

in the bay (3.4)

its faceplate's front flat from
the throat to its edge, the grille
off: measure first (M3)

connector, Mini-Fit
Jr. (3.1): the plug on
the tweeter's lead, the
socket on the cabinet's

silicone round the cable,
20 deep, from the bay

SECTION B-B (WITH THE GABLE)

3 x ø3.6 x 5 holes on ø54 in the seat, one at the top, 120° apart,
for M2.5 x 4 knurled brass inserts bonded with epoxy;
M2.5 x 8 button heads (ISO 7380, A2) through the faceplate: measure it first

channel ø14
to the amplifier

Fitting the tweeter and the insert: notes 3.1 to 3.9, sheet 9

PRINTED GABLE (ROUTE B), PLAN, 1:5

Split planes (chain lines) and pins (bars): stl/gable-print/
8 steel pins ø4 x 20 a speaker, in ø4.2 holes 10.5 deep each
side; dry-fit each joint closed, then 3M DP420 over its full
rim, and seal the channel halves' seam along its length.
Hollow the pieces to 3 mm walls, two ø3 drains each in the
outer slopes or end faces only (none in the base, a joint
face, the channel, the bay or the pocket), plugged with resin
and filled before paint.

BACK (THE FACE THAT MEETS THE POCKET)

Waveguide insert and tweeter mount

earmilk bookshelf. The insert at 1:1: front, section on the axis, back; the pocket;
fitting and service.

mm | issue 2026-10-09 | HOLD until M3, M5 (tweeter, connector)

EM-BS-003 rev D

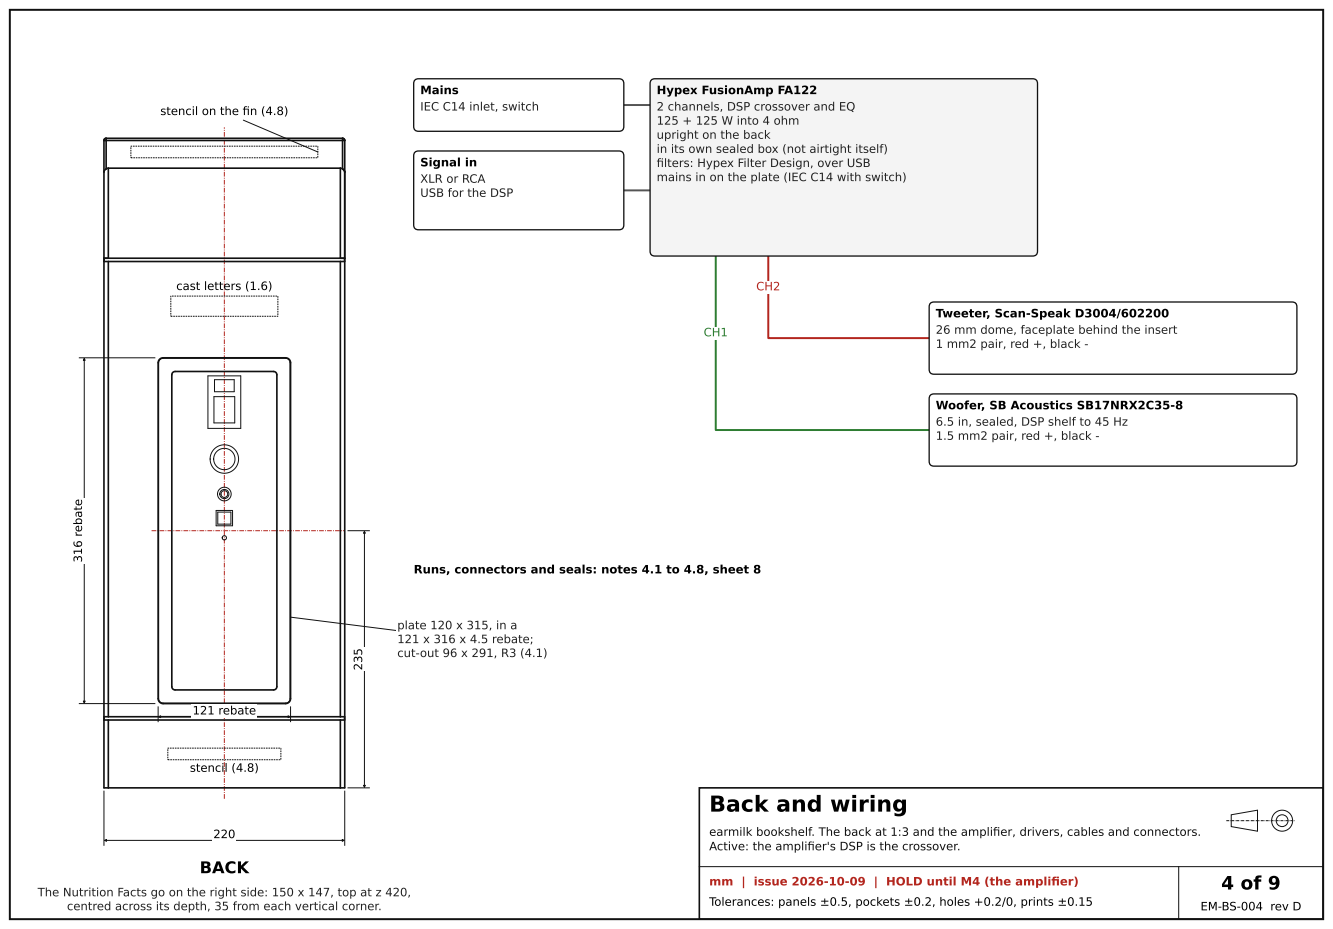
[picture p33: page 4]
121 rebate; 316 rebate; BACK; cast letters (1.6); stencil (4.8); plate 120 x 315, in a 121 x 316 x 4.5 rebate; cut-out 96 x 291, R3 (4.1)

Mains
IEC C14 inlet, switch

Hypex FusionAmp FA122
2 channels, DSP crossover and EQ
125 + 125 W into 4 ohm
upright on the back
in its own sealed box (not airtight itself)
filters: Hypex Filter Design, over USB
mains in on the plate (IEC C14 with switch)

stencil on the fin (4.8)

Signal in
XLR or RCA
USB for the DSP

Tweeter, Scan-Speak D3004/602200
26 mm dome, faceplate behind the insert
1 mm2 pair, red +, black -

Woofer, SB Acoustics SB17NRX2C35-8
6.5 in, sealed, DSP shelf to 45 Hz
1.5 mm2 pair, red +, black -

Runs, connectors and seals: notes 4.1 to 4.8, sheet 8

centred across its depth, 35 from each vertical corner. ²³⁵

Back and wiring

earmilk bookshelf. The back at 1:3 and the amplifier, drivers, cables and connectors.
Active: the amplifier's DSP is the crossover.

mm | issue 2026-10-09 | HOLD until M4 (the amplifier)

The Nutrition Facts go on the right side: 150 x 147, top at z 420,

EM-BS-004 rev D
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

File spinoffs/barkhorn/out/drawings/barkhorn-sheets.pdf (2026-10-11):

A

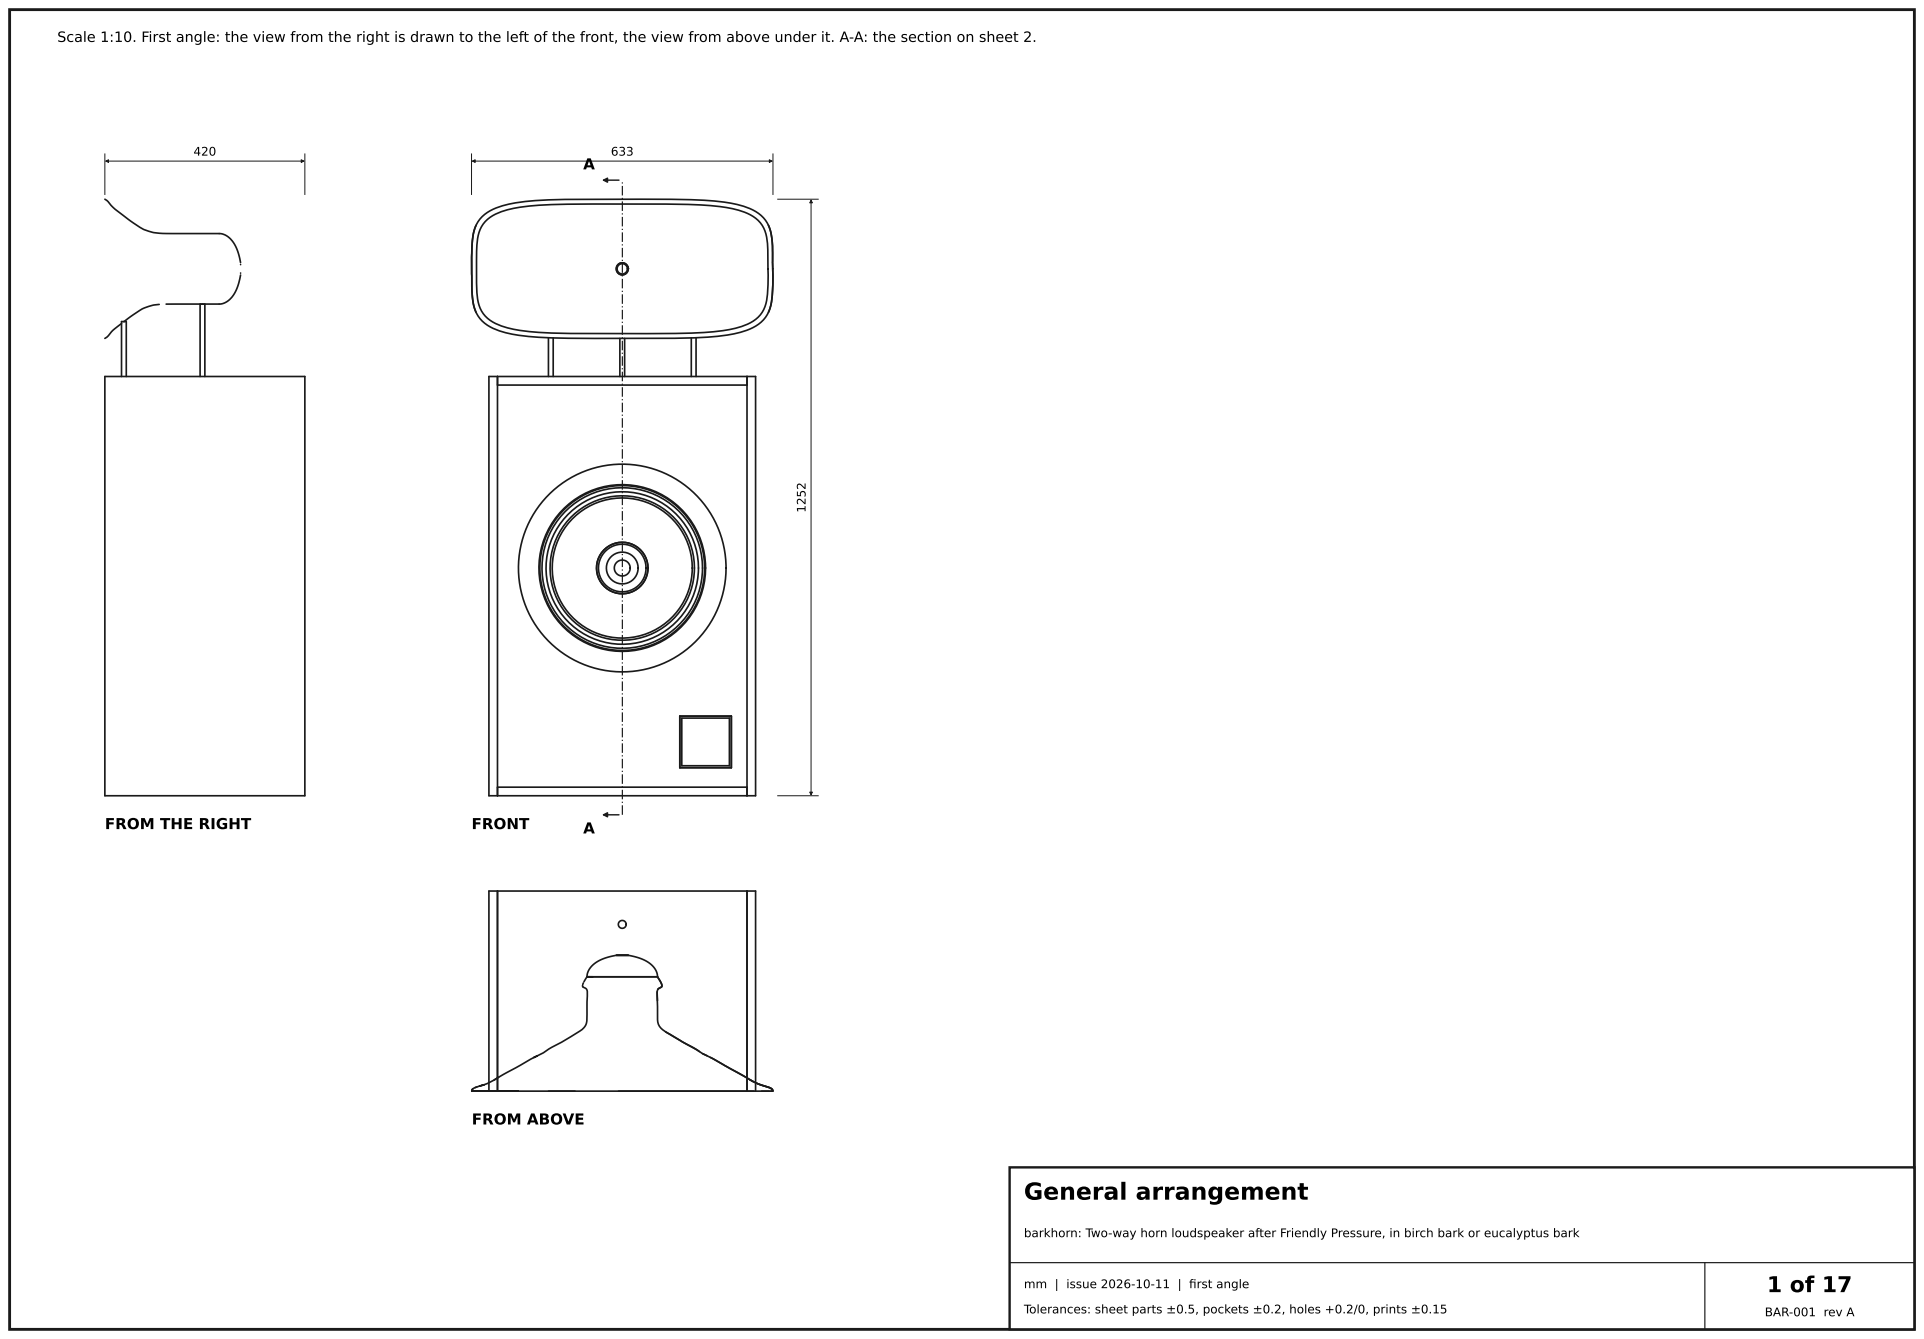
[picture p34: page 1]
FROM THE RIGHT; FRONT; FROM ABOVE; General arrangement; BAR-001 rev A

Scale 1:10. First angle: the view from the right is drawn to the left of the front, the view from above under it. A-A: the section on sheet 2.

barkhorn: Two-way horn loudspeaker after Friendly Pressure, in birch bark or eucalyptus bark

mm | issue 2026-10-11 | first angle

Tolerances: sheet parts ±0.5, pockets ±0.2, holes +0.2/0, prints ±0.15

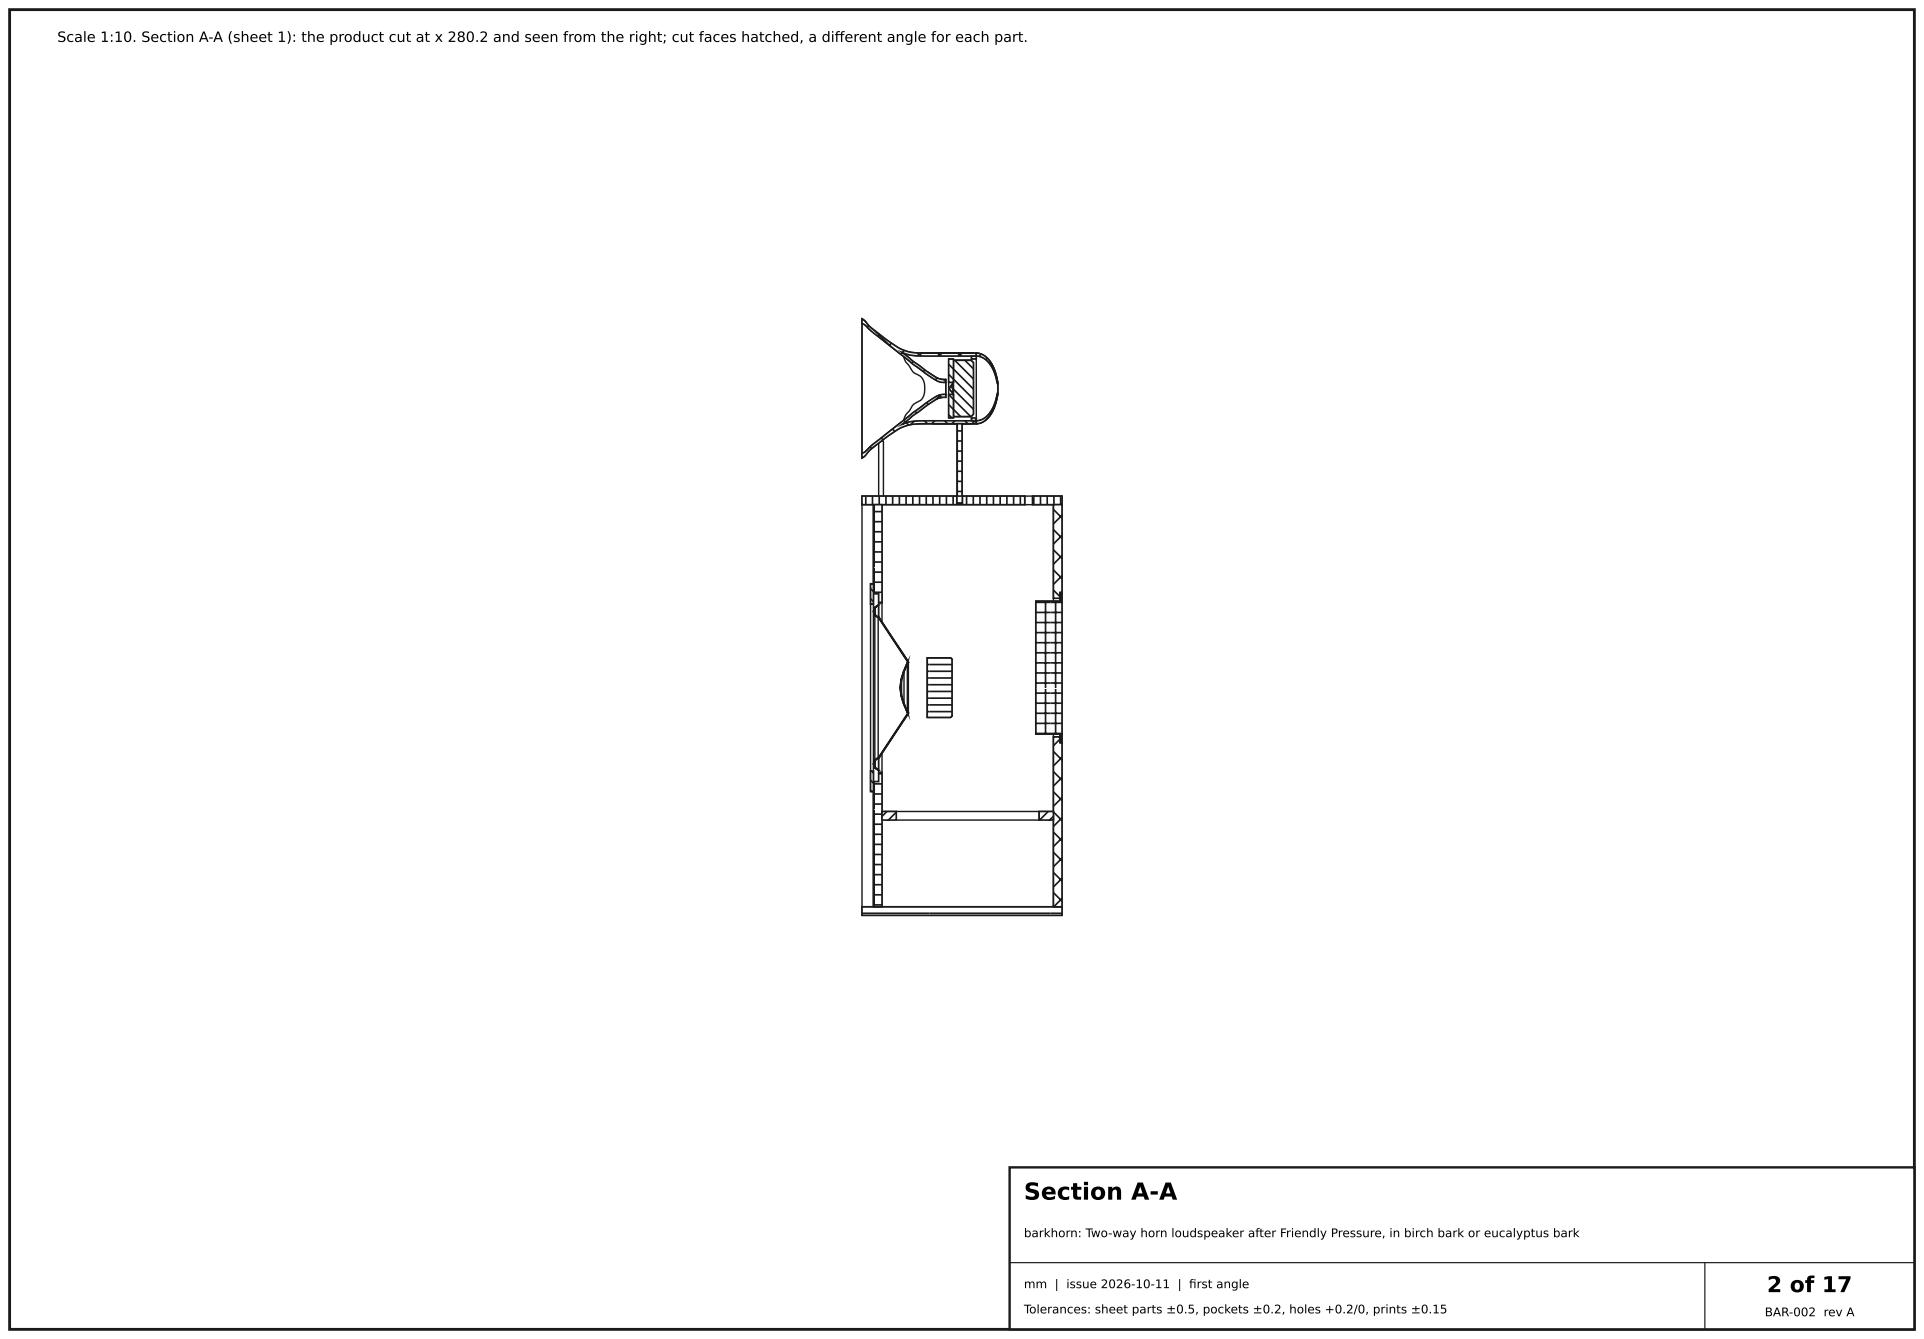
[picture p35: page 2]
Section A-A; BAR-002 rev A

Scale 1:10. Section A-A (sheet 1): the product cut at x 280.2 and seen from the right; cut faces hatched, a different angle for each part.

barkhorn: Two-way horn loudspeaker after Friendly Pressure, in birch bark or eucalyptus bark

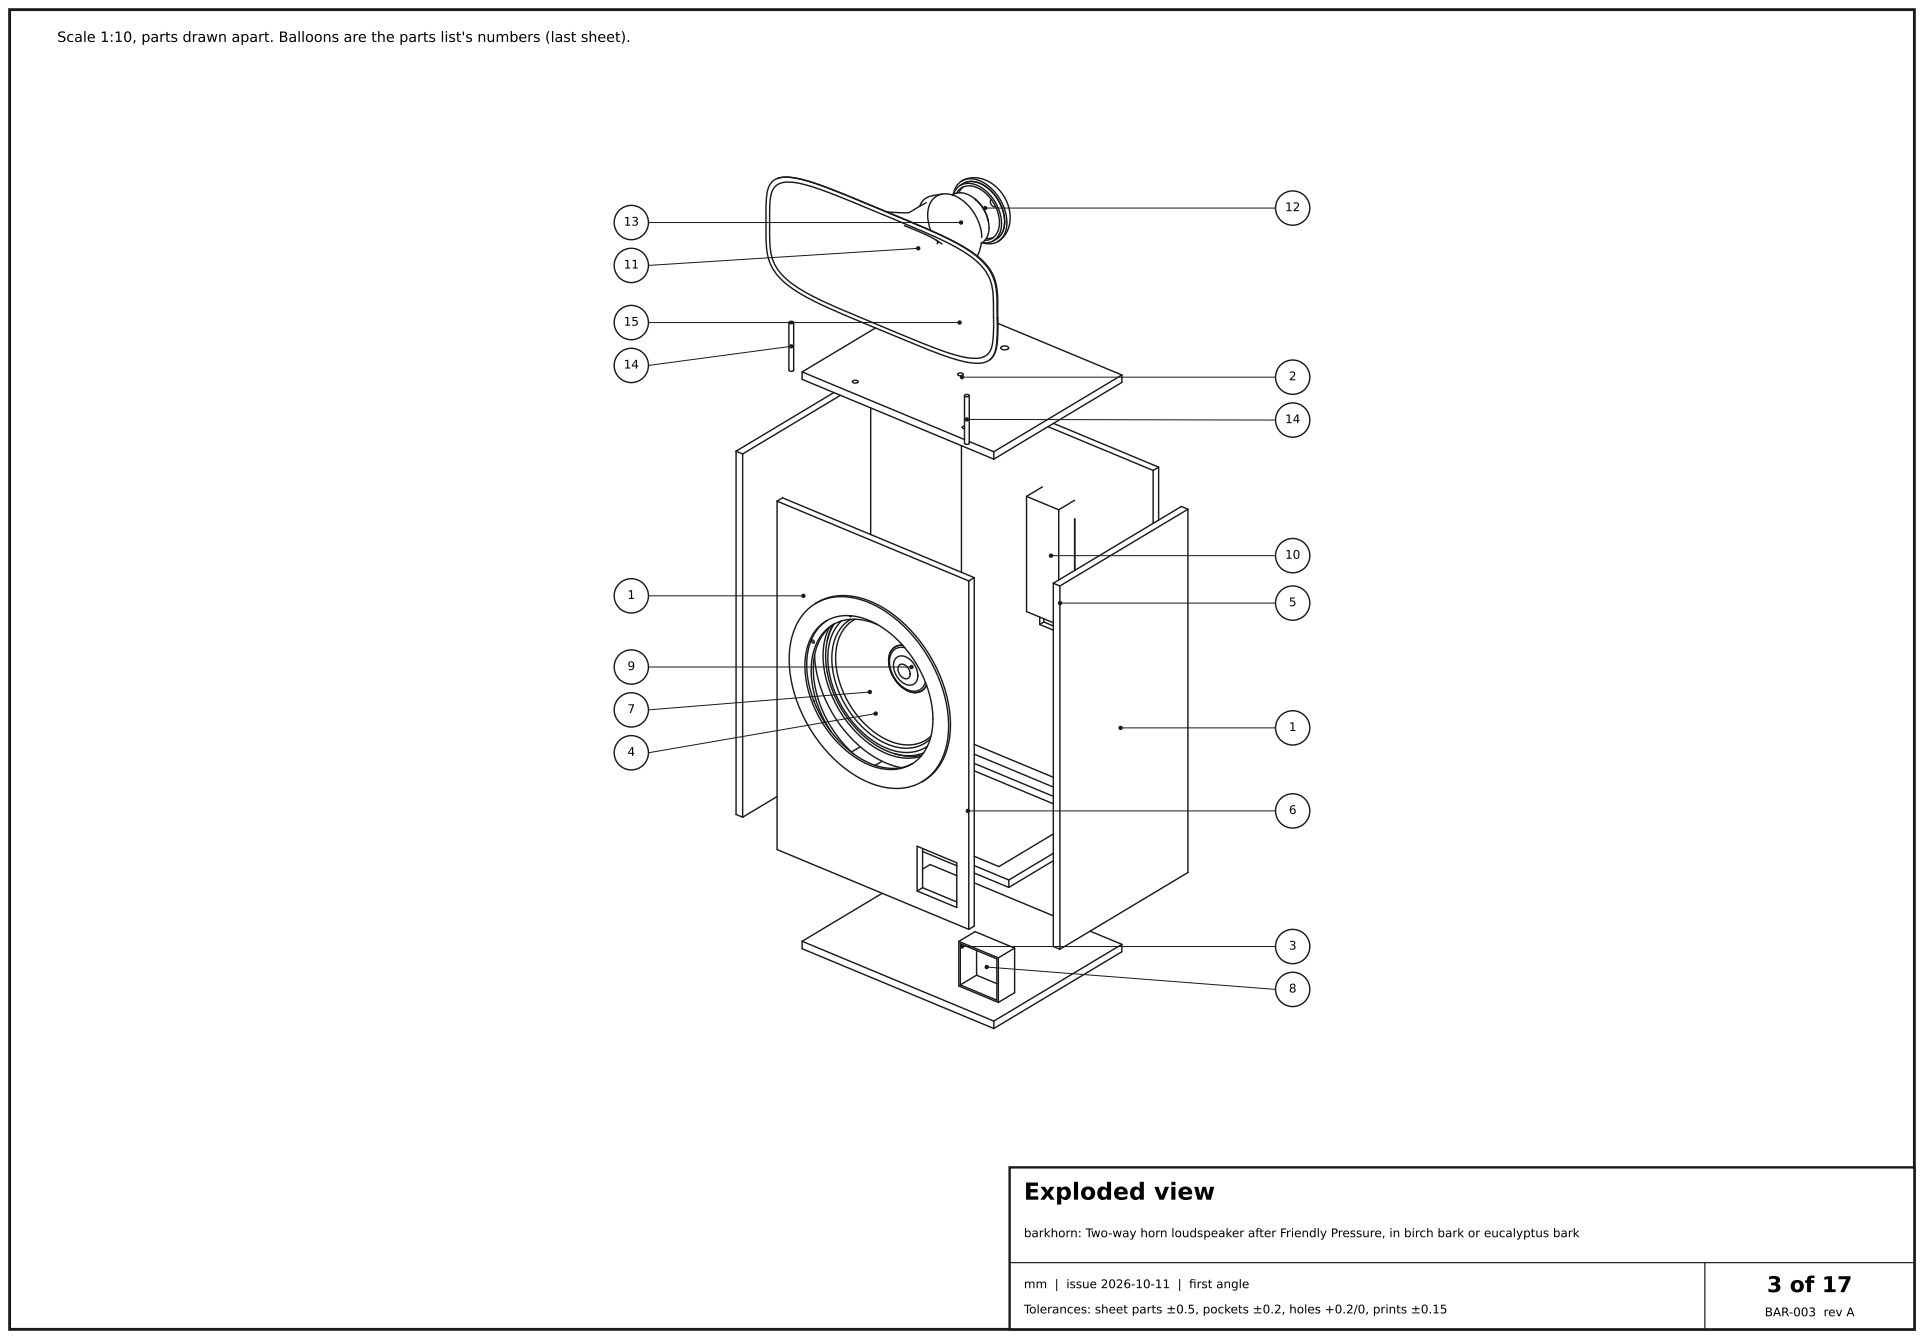
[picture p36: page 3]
Exploded view; BAR-003 rev A

Scale 1:10, parts drawn apart. Balloons are the parts list's numbers (last sheet).

barkhorn: Two-way horn loudspeaker after Friendly Pressure, in birch bark or eucalyptus bark

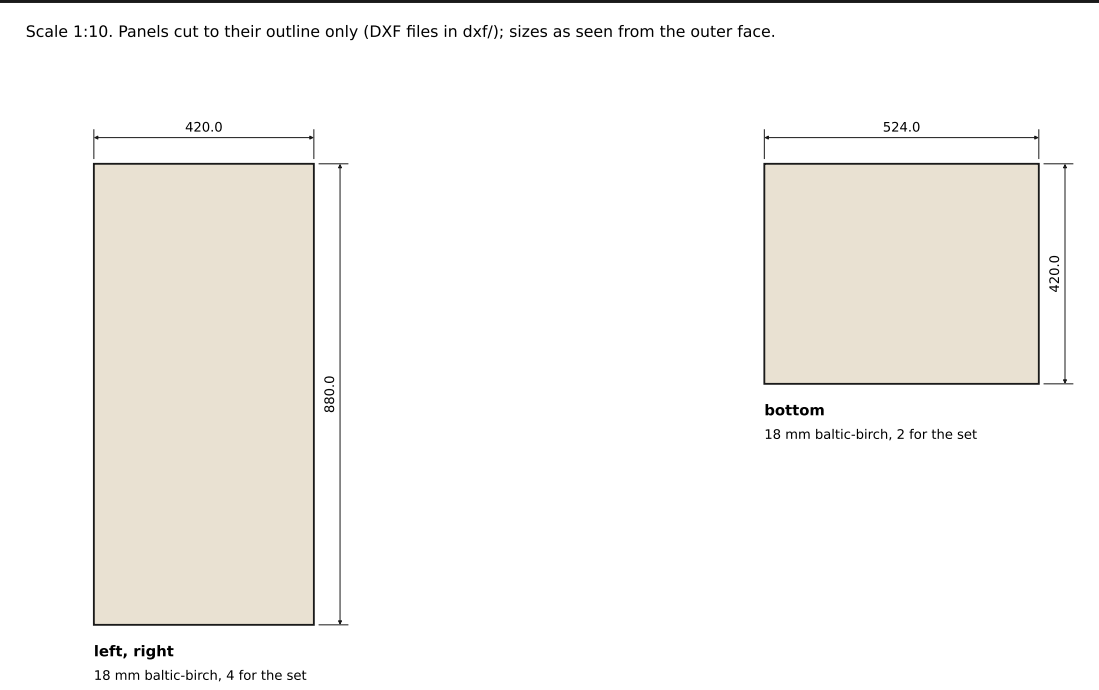
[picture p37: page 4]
left, right; bottom; BAR-004 rev A

Scale 1:10. Panels cut to their outline only (DXF files in dxf/); sizes as seen from the outer face.

18 mm baltic-birch, 2 for the set

18 mm baltic-birch, 4 for the set

Sheet parts: plain panels

barkhorn: Two-way horn loudspeaker after Friendly Pressure, in birch bark or eucalyptus bark

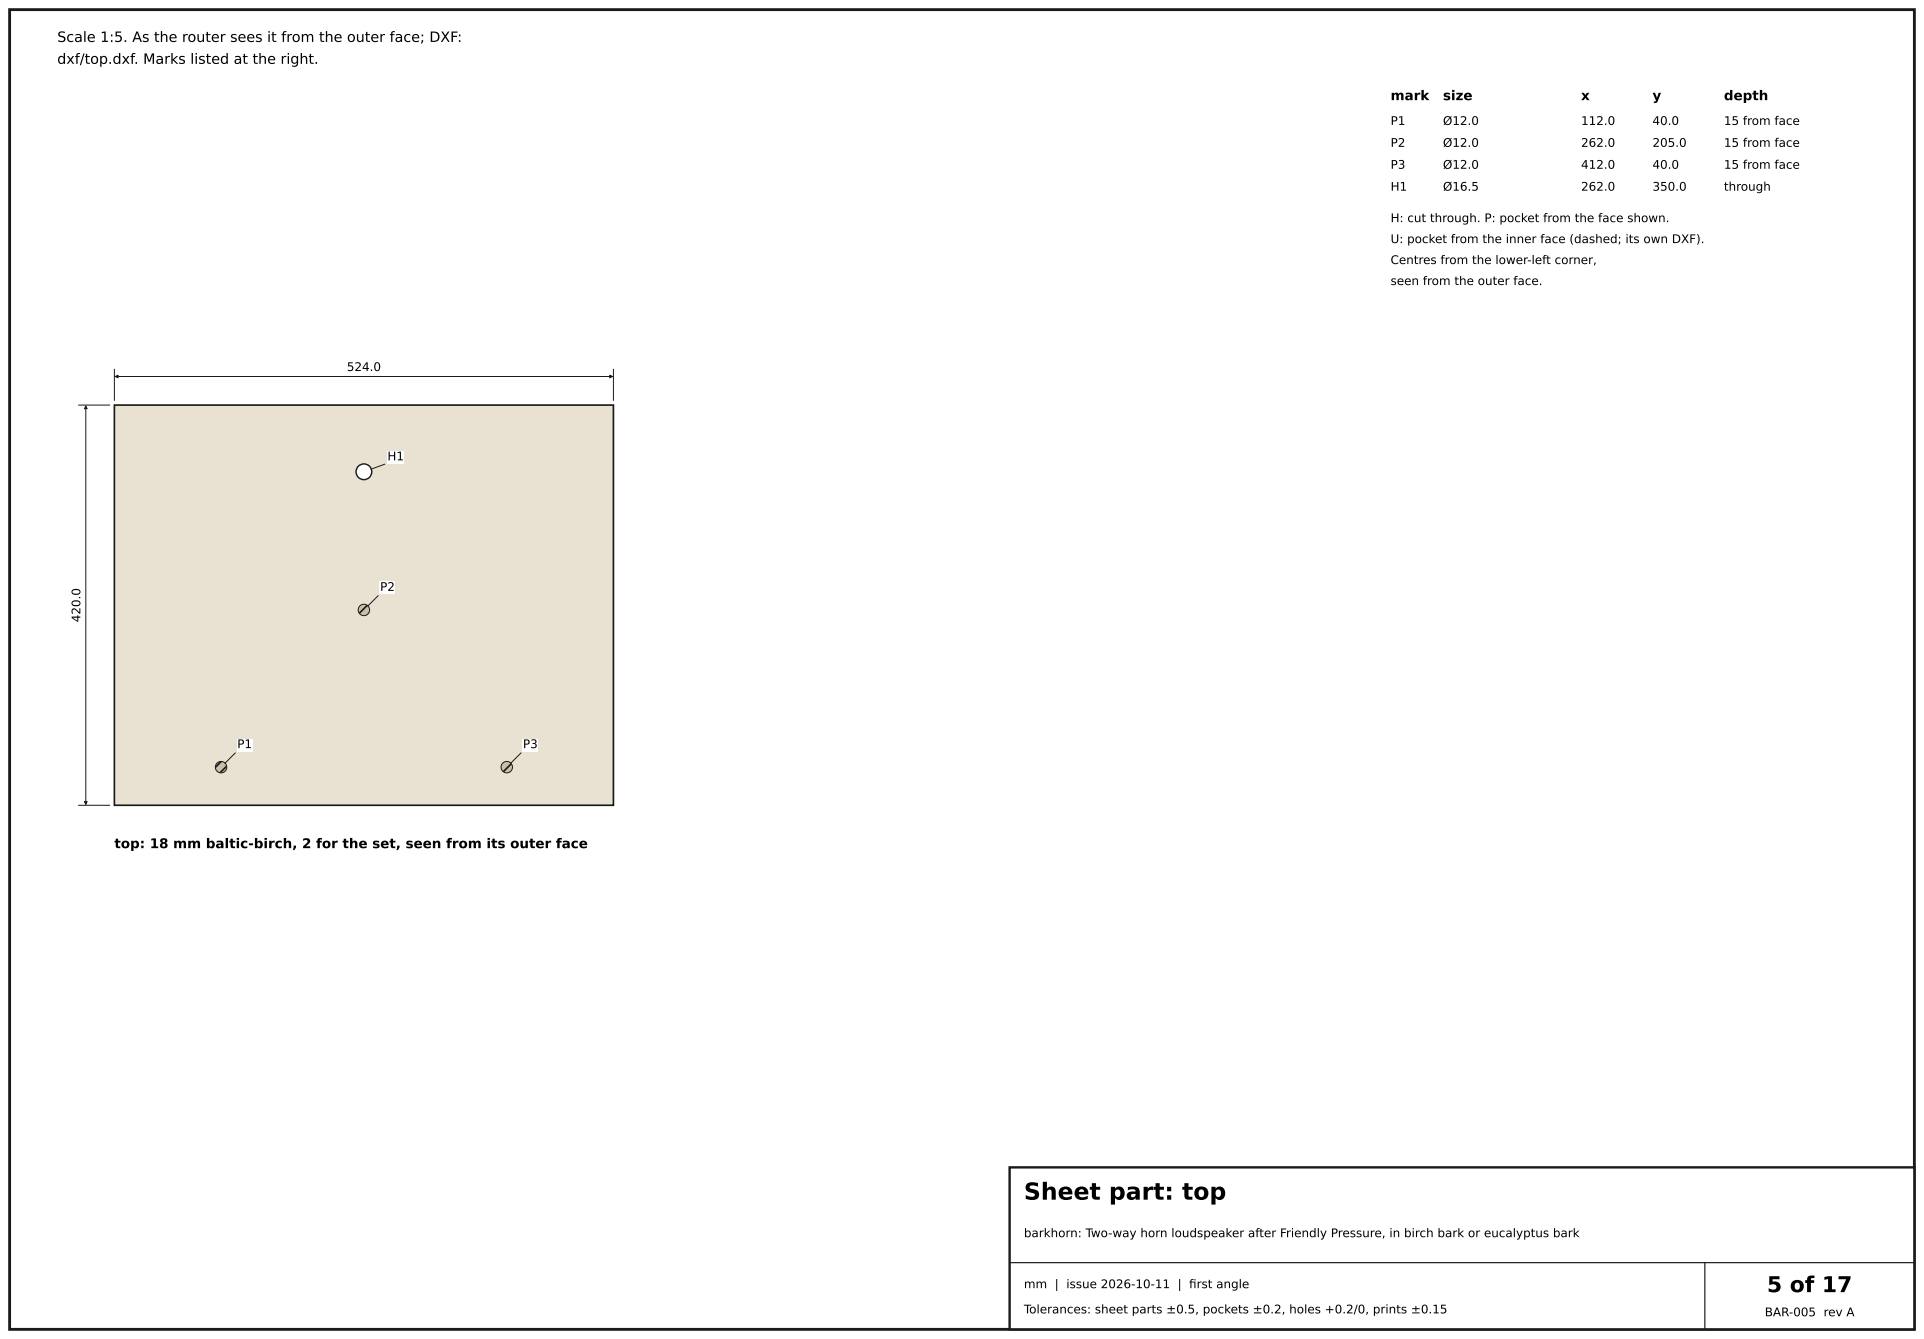
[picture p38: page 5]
mark size; depth; 15 from face; through; BAR-005 rev A

Scale 1:5. As the router sees it from the outer face; DXF:
dxf/top.dxf. Marks listed at the right.

H: cut through. P: pocket from the face shown.

U: pocket from the inner face (dashed; its own DXF).

Centres from the lower-left corner,

seen from the outer face.

top: 18 mm baltic-birch, 2 for the set, seen from its outer face

Sheet part: top

barkhorn: Two-way horn loudspeaker after Friendly Pressure, in birch bark or eucalyptus bark

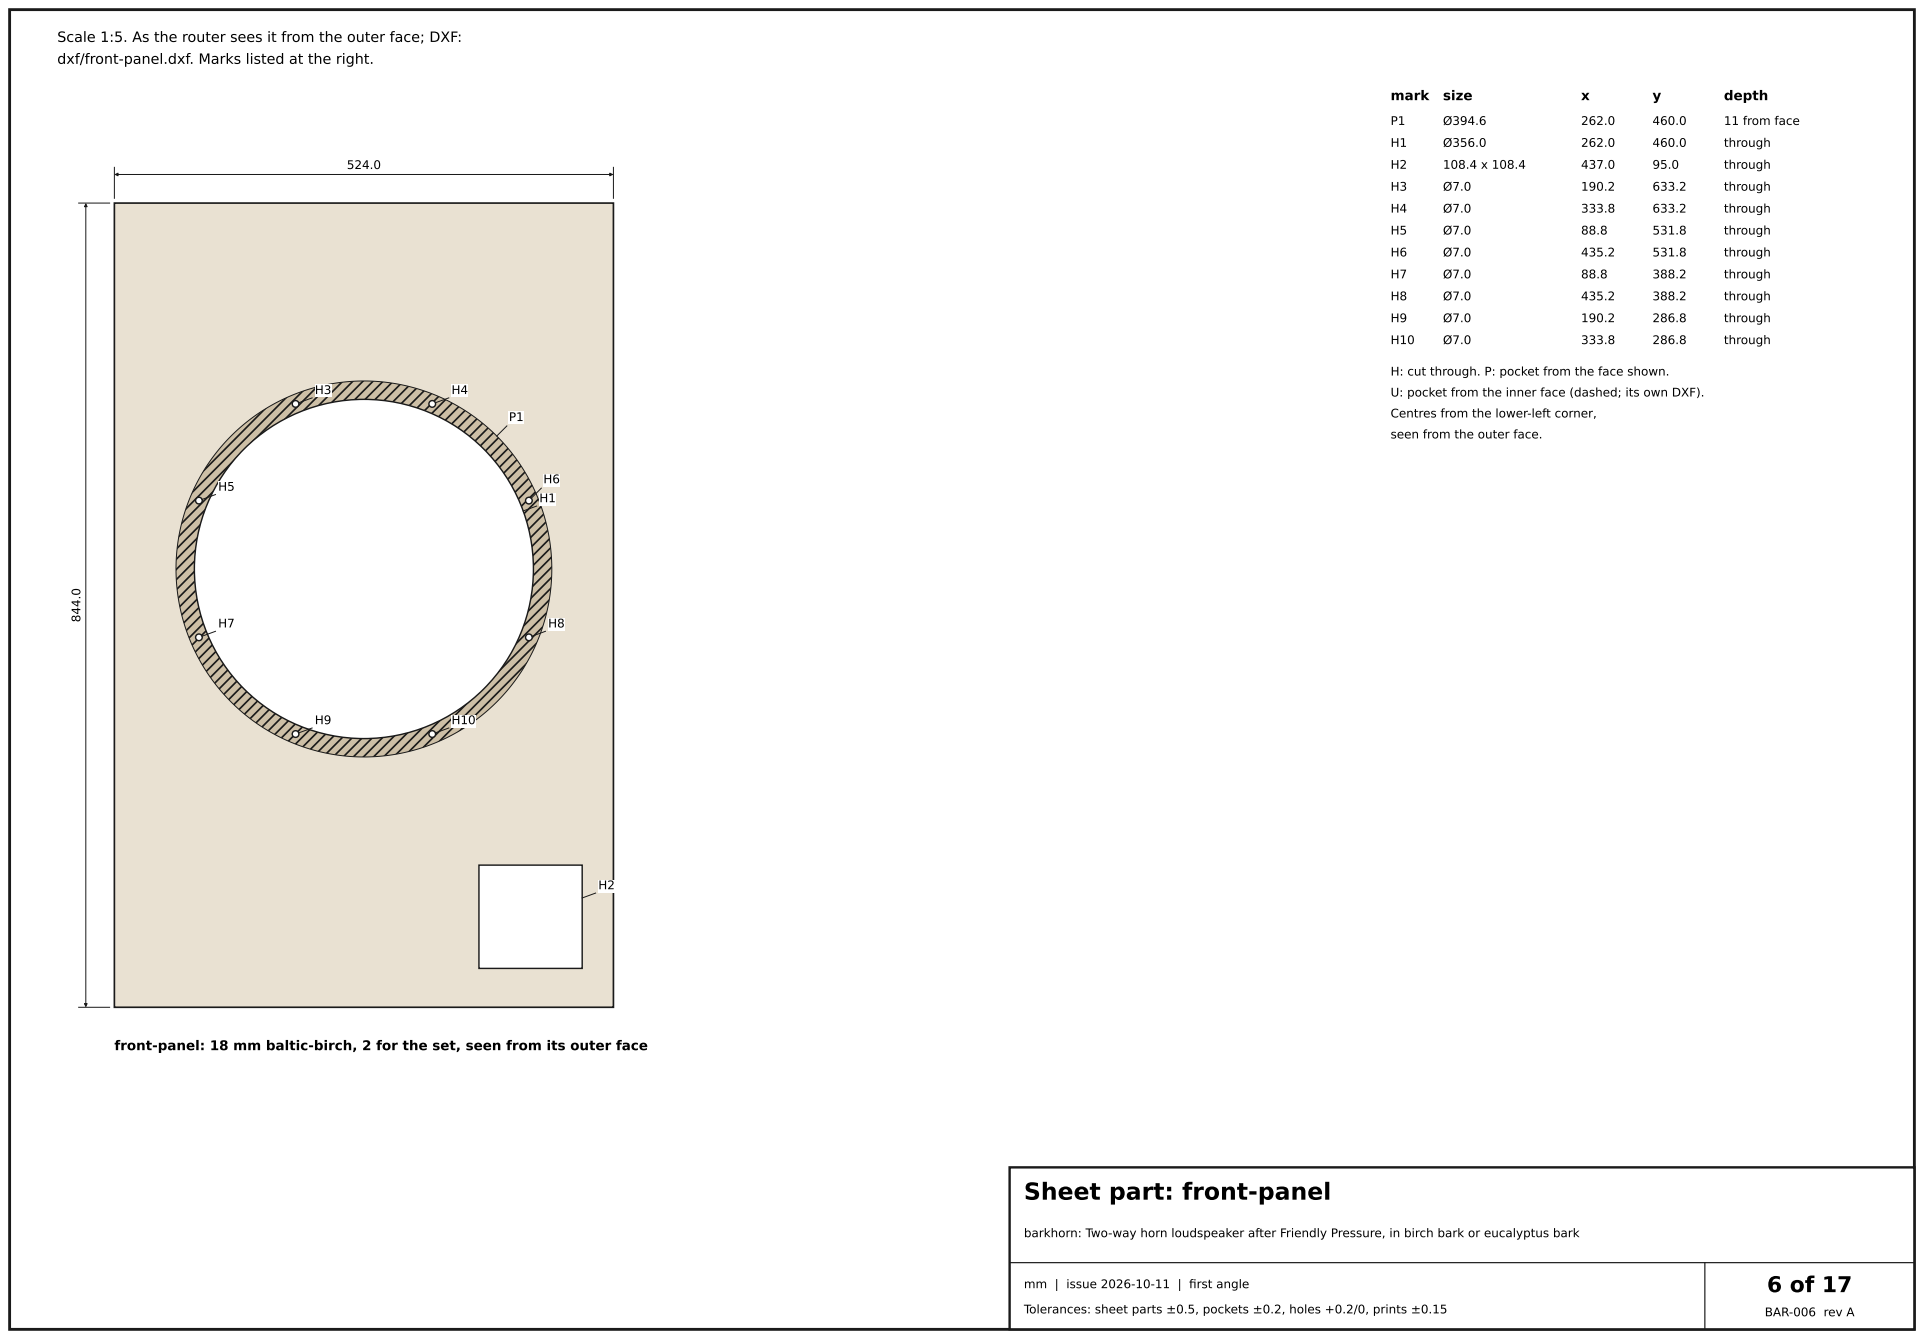
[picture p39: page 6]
mark size; depth; 11 from face; through; BAR-006 rev A

dxf/front-panel.dxf. Marks listed at the right.

H: cut through. P: pocket from the face shown.

U: pocket from the inner face (dashed; its own DXF).

Centres from the lower-left corner,

seen from the outer face.

front-panel: 18 mm baltic-birch, 2 for the set, seen from its outer face

Sheet part: front-panel

barkhorn: Two-way horn loudspeaker after Friendly Pressure, in birch bark or eucalyptus bark

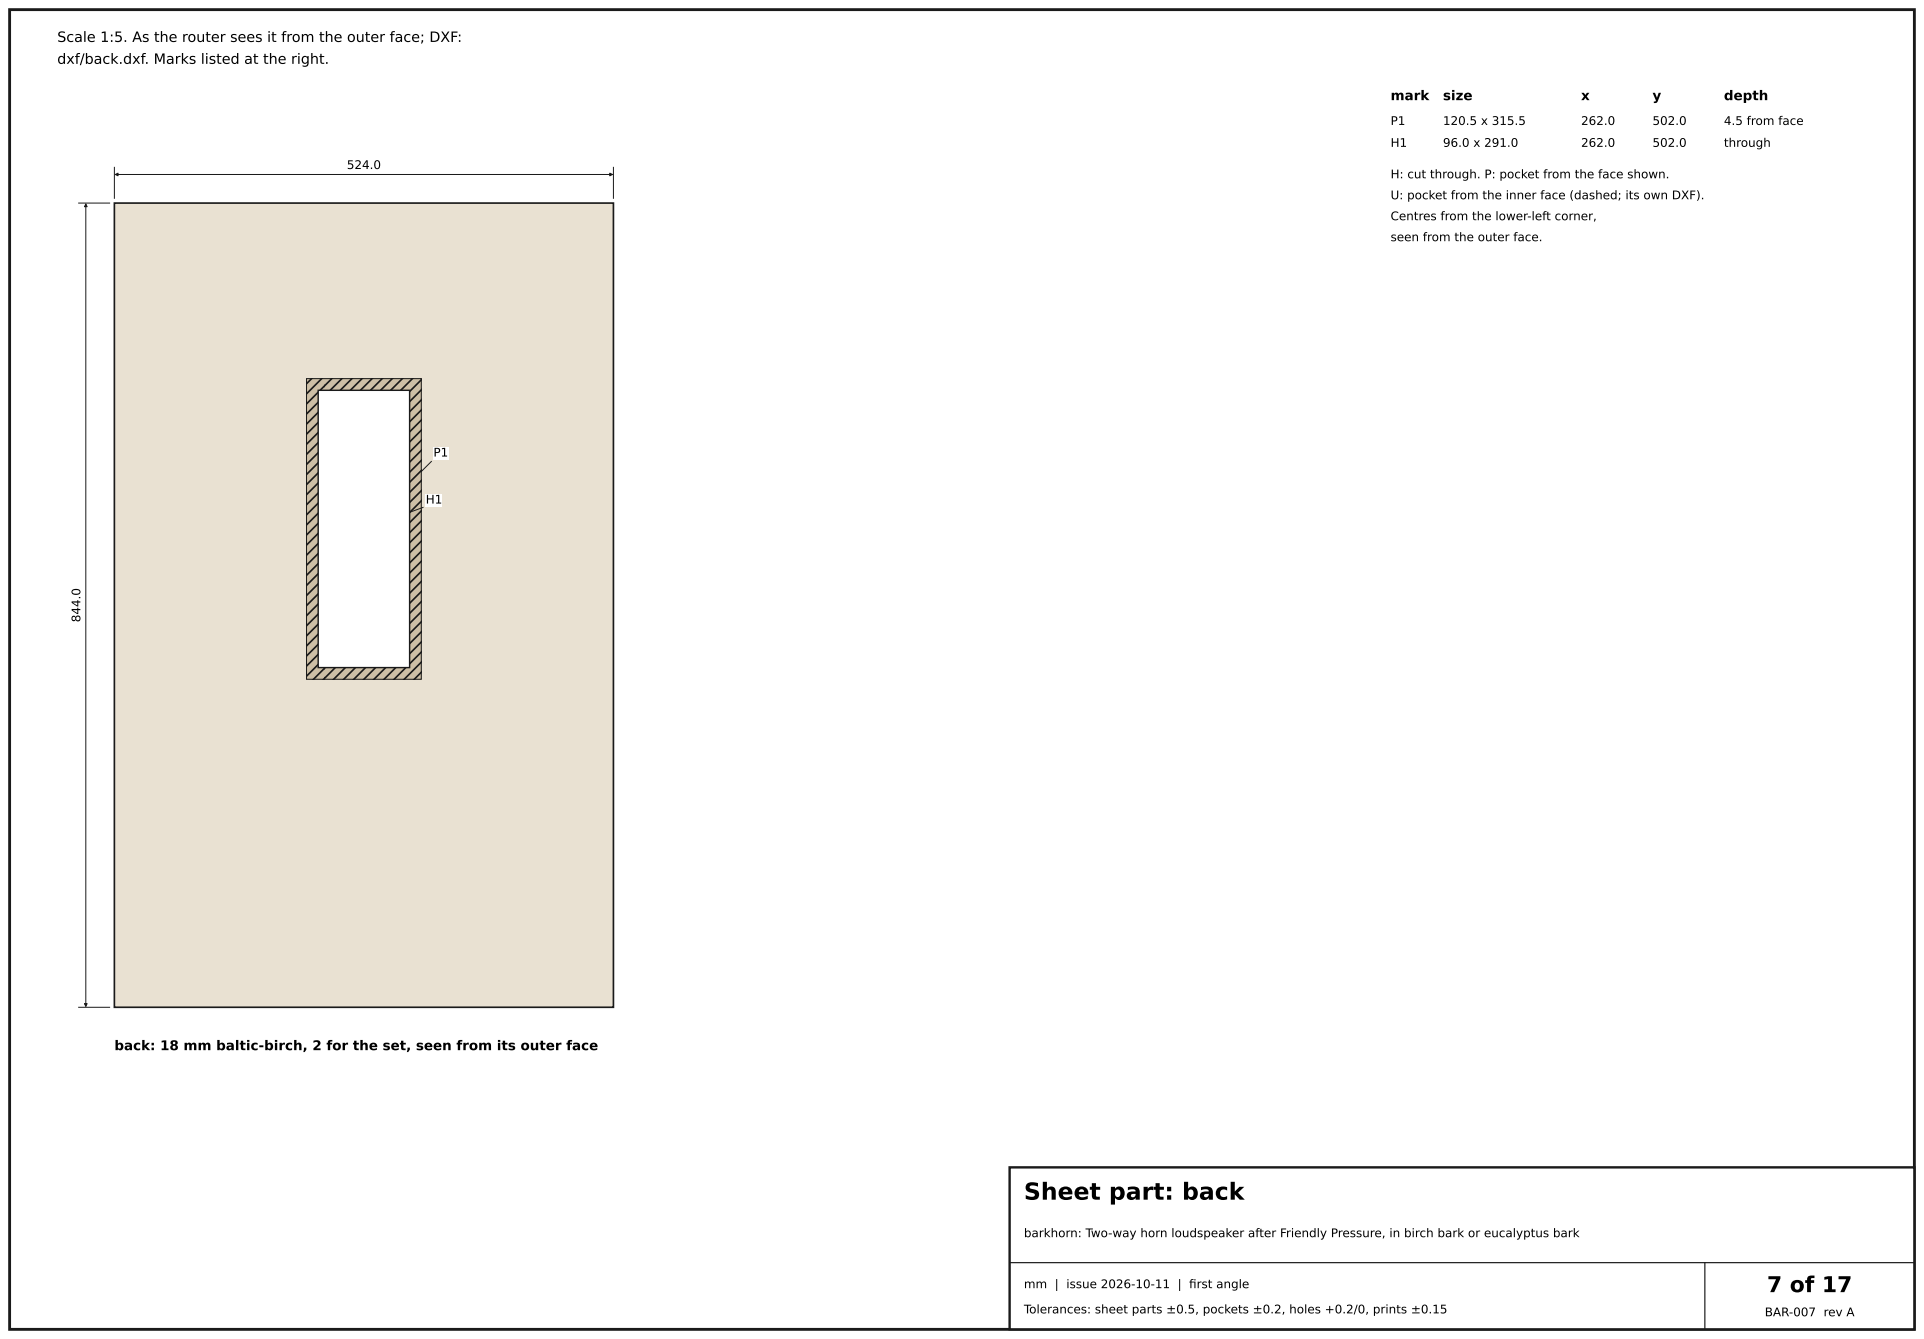
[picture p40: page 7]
mark size; depth; 4.5 from face; through; BAR-007 rev A

dxf/back.dxf. Marks listed at the right.

H: cut through. P: pocket from the face shown.

U: pocket from the inner face (dashed; its own DXF).

Centres from the lower-left corner,

seen from the outer face.

back: 18 mm baltic-birch, 2 for the set, seen from its outer face

Sheet part: back

barkhorn: Two-way horn loudspeaker after Friendly Pressure, in birch bark or eucalyptus bark

mark size; depth; through; BAR-008 rev A

dxf/brace.dxf. Marks listed at the right.

H: cut through. P: pocket from the face shown.

U: pocket from the inner face (dashed; its own DXF).

Centres from the lower-left corner,

seen from the outer face.

brace: 18 mm baltic-birch, 2 for the set, seen from its outer face

Sheet part: brace

barkhorn: Two-way horn loudspeaker after Friendly Pressure, in birch bark or eucalyptus bark


dxf/woofer-ring.dxf. Marks listed at the right.

H: cut through. P: pocket from the face shown.

U: pocket from the inner face (dashed; its own DXF).

Centres from the lower-left corner,

seen from the outer face.

woofer-ring: 6 mm mdf, 2 for the set, seen from its outer face

inner-face pockets: dxf/woofer-ring-underside.dxf (seen from that face)

Sheet part: woofer-ring

barkhorn: Two-way horn loudspeaker after Friendly Pressure, in birch bark or eucalyptus bark

mark size; depth; through; BAR-010 rev A

dxf/cloth-frame.dxf. Marks listed at the right.

H: cut through. P: pocket from the face shown.

U: pocket from the inner face (dashed; its own DXF).

Centres from the lower-left corner,

seen from the outer face.

cloth-frame: 6 mm mdf, 2 for the set, seen from its outer face (option: cloth)

Sheet part: cloth-frame (option: cloth)

barkhorn: Two-way horn loudspeaker after Friendly Pressure, in birch bark or eucalyptus bark

mark size; depth; slot 6.0 wide,; 394 off; DXF; through; 22-120 long; BAR-011 rev A

dxf/grille-lenticel.dxf. Marks listed at the right.

H: cut through. P: pocket from the face shown.

U: pocket from the inner face (dashed; its own DXF).
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

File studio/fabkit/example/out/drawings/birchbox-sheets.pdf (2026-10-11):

A

FROM THE RIGHT; FRONT; FROM ABOVE; General arrangement; BIR-001 rev A

Scale 1:5. First angle: the view from the right is drawn to the left of the front, the view from above under it. A-A: the section on sheet 2.

Birch Box: Two-way active bookshelf speaker (the kit's example)

mm | issue 2026-10-11 | first angle

Tolerances: sheet parts ±0.5, pockets ±0.2, holes +0.2/0, prints ±0.15

Section A-A; BIR-002 rev A

Scale 1:2. Section A-A (sheet 1): the product cut at x 115.0 and seen from the right; cut faces hatched, a different angle for each part.

Birch Box: Two-way active bookshelf speaker (the kit's example)

Exploded view; BIR-003 rev A

Scale 1:5, parts drawn apart. Balloons are the parts list's numbers (last sheet).

Birch Box: Two-way active bookshelf speaker (the kit's example)

left, right; top, bottom; BIR-004 rev A

Scale 1:5. Panels cut to their outline only (DXF files in dxf/); sizes as seen from the outer face.

18 mm baltic-birch, 4 for the set

Sheet parts: plain panels

Birch Box: Two-way active bookshelf speaker (the kit's example)

mark size; depth; 7.5 from face; 5 from face; through; BIR-005 rev A

Scale 1:2. As the router sees it from the outer face; DXF:
dxf/baffle.dxf. Marks listed at the right.

H: cut through. P: pocket from the face shown.

U: pocket from the inner face (dashed; its own DXF).

Centres from the lower-left corner,

seen from the outer face.

baffle: 18 mm baltic-birch, 2 for the set, seen from its outer face

Sheet part: baffle

Birch Box: Two-way active bookshelf speaker (the kit's example)

mark size; depth; 4.5 from face; through; BIR-006 rev A

Scale 1:2. As the router sees it from the outer face; DXF:
dxf/back.dxf. Marks listed at the right.

H: cut through. P: pocket from the face shown.

U: pocket from the inner face (dashed; its own DXF).

Centres from the lower-left corner,

seen from the outer face.

back: 18 mm baltic-birch, 2 for the set, seen from its outer face

Sheet part: back

Birch Box: Two-way active bookshelf speaker (the kit's example)

FRONT; FROM ABOVE; BIR-007 rev A

Three views each, hidden edges dashed; STL and STEP files in stl/ and step/. Numbers are the parts list's.

5. waveguide: resin-tough print, front face down; 202 cm3 each; 2 for the set; 1:2

oblate-spheroidal, r0 17.5, 90 degrees, mouth 74 across

FROM THE RIGHT

9. foot-1, foot-2, foot-3, foot-4: lathe, oak; 8 cm3 each; 8 for the set; 1:1

Printed and machined parts

Birch Box: Two-way active bookshelf speaker (the kit's example)

For 2; prices are budgets (bom.md says where each comes from).

no. | item | make | qty | what | size | each USD
1 | left, right | cut | 4 | 18 mm Baltic birch plywood, BB/BB | 260 x 400 | 7.54
2 | top, bottom | cut | 4 | 18 mm Baltic birch plywood, BB/BB | 194 x 260 | 3.66
3 | baffle | cut | 2 | 18 mm Baltic birch plywood, BB/BB | 194 x 364 | 5.12
4 | back | cut | 2 | 18 mm Baltic birch plywood, BB/BB | 194 x 364 | 5.12
5 | waveguide | print | 2 | Tough (ABS-like) SLA resin | 202 cm3 | 78.82
6 | woofer | buy | 2 | SB Acoustics SB17NRX2C35-8 6.5 in Norex (paper cone) | 171 frame, 144.9 cut-out, 75 deep | 76.70
7 | tweeter | buy | 2 | Scan-Speak Illuminator D3004/602200 26 mm dome | 62 faceplate | 165.00
8 | amp-plate | buy | 2 | Hypex FusionAmp FA122 DSP plate amplifier, 2 x 125 W into 4 ohm | 315 x 120 x 55 plate, 291 x 96 recess | 422.40
9 | foot-1, foot-2, foot-3, foot-4 | lathe | 8 | White oak, solid | 40 x 40 x 22 | 10.63
10 | woofer-fixings | buy | 2 | M4 x 20 low-profile button heads (A2) with M4 T-nuts, a driver's set of 4 | M4 | 4.00
11 | gasket | buy | 2 | 1.5 mm closed-cell foam gasket strip, 1 m | | 5.00
12 | damping | buy | 2 | Polyester fibre fill, 150 g | | 8.00
13 | amp-fixings | buy | 2 | Hypex 4.3 x 16 self-tapping pan heads and 3 mm EPDM tape, a plate's set | | 10.00
14 | cable | buy | 2 | Round-sheathed speaker cable 2 x 1.5 mm2, 1 m | | 2.00
15 | terminals | buy | 8 | 6.3 mm insulated push-on terminal | | 0.50

## Notes

1. Glue-up: sides to the bottom, then the baffle and back, then the top; wood glue, clamped 1 h each.
2. Fit the drivers on their gaskets with the T-nuts hammered in from inside before the back goes on.
3. The amplifier's screw holes are drilled from the plate in hand (Hypex does not publish the pattern).
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

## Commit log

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2026-10-01 Log critic round 1, add v2 renders with the fixes it asked for
    Round 1 scored 3 to 5 across the seven shots and agreed on grounding,
    flat materials and three compositions. v2 adds contact shadows, a
    stronger sun with fills cut back and warm floor bounce, coated-board
    sheen and rounded board edges, driver baskets with flange, screws and a
    glossy surround, a reflective tweeter faceplate, skirting and a chair
    for scale, windows moved so the sun lights the faces the camera sees, a
    raised camera on the back and crate shots, and a swap middle frame with
    the lid standing on the floor and the tube lifted clear of the gable.
    Prompt files bumped to v2 with the change lines.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
2026-10-01 Log critic round 2, add v3 renders with an occlusion pass and board detail
    Round 2 held at 4 to 5 and asked for light that visibly touches the
    object, paperboard that shows its folds, and three framings. v3 adds a
    screen-space ambient occlusion pass, glossier coated board with fold
    lines at the ridge and crimp lines on the fin, lighter shaded cones with
    highlights, reflective floors, a cool ambient in the old room, pint
    throats closed in the throat colour, crate boards with end grain, the
    removed sleeve standing behind the speaker in the swap's last frame,
    camera moves on the lineup, crate and close-up, and 2x supersampling.
    Prompt files bumped to v3 with the change lines.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
2026-10-01 Lock the amended look and render v4 of all seven shots
    Amendments of 2026-10-01 carried through: lids in the print colour on
    the white flavours, a printed base band carrying the wordmark on the
    front and the right side, nothing under the gable, an optional stand
    and an optional owner's panel. README gains a marked Amendments block,
    colorways.json carries the print layout as data the model reads, the
    geometry file documents the band, panel and stand, copy gains the panel
    and stand lines, and the shot briefs move to v4 with the camera notes
    from critic round 3 (hero corner line, close-up offset, swap horizon,
    larger desk set).
    Claude-Se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
2026-10-02 Carry the round 4 camera and placement notes into v5; canvas on the locked look
    Hero fill down and sun up with the chair clear of the left speaker; the old room's key raised so the fin's shadow lands on the slope; the close-up bowl shades by its normals and the top lip leaves the frame; the lineup from 11.5 m on a 140 mm lens; the crate camera higher and closer; the swap's lid clear of the standing tube. Copy mirrors the two canvas amendments. Round 5 is not run: the direction changed before it started.
    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
2026-10-02 Direction 2026-10-02: no sleeve, the colour a finish, a built-in plinth, a badge
    The carton is the cabinet, finished in the flavour's colours and fixed per speaker; the band and the stand become one 110 mm plinth with a shadow line; the wordmark is a cast metal badge on the plinth's front and an engraving on the birch back panel above the Nutrition Facts; the owner's panel is dropped. Marked amendments in the README, spec, copy and prompts; shot 07 retired, shot 02 pending a rebrief; the model gains a finish mode, the badge, the engraving and the exploration marks; the dated explorations keep the sleeve look.
    Claude-Session: https://c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
2026-10-02 Back: the birch field holds only the Nutrition Facts; shot 02 rebriefed
    The bare birch field is now the Facts panel plus a 26 mm margin; the wordmark is engraved on the finish above it, the port and the binding posts sit on the finish below, the post plate up to z 150 to clear the plinth's shadow line. The full-height field stays as an option with its bottom lifted so its margins match. Both rendered as explorations, the back shot at v9, the canvas at version 12. Shot 02 is rebriefed as the same pair in two homes, years apart.
    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
2026-10-02 v11: SHAKE WELL on the plinth, the Facts footnote inside its border, and the camera carries
    Only OPEN OTHER SIDE and SHAKE WELL stay; SHAKE WELL moves onto the plinth's back face, reversed in the body colour. The engraved panel is 266 x 260 so "Contains no milk." sits inside the border with 14 mm padding all round, and the bronze plate grows with it. The hero pair toed in from a lower, longer camera; the window mullion gone from both rooms; the close-up aimed clear of the top lip and the mid's flange; the crate camera lower and its base board's end-grain fringe fixed. No critic round: the cap for this look is reached. Canvas at version 14.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
2026-10-03 Path-traced pass, round 1: seven frames and the critic's verdict
    The v11 scenes rendered in Cycles (shot-NN-v11-pt.png) and one critic
    round on each. Scores 6, 5, 5, 4, 5, 5, 4: the hero's 6 is the highest
    yet. Every report asked for the same two things, a key the fill does not
    swamp and a surface with something to reflect, and found two bugs: the
    sun spilling over a ceiling-less wall in the hero, and the crate base
    rendering black where it shared the walls' planes. v12 follows.
    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
2026-10-03 Path-traced pass, round 2: closed rooms, studio sweep, real light units
    v12 of every shot, real-time and path-traced, with the critic's second
    round (5, 6, 5, 5, 5, 6, 5). The rooms are closed boxes so daylight is
    only what the window admits; the studio floor sweeps into a backdrop,
    its key is a softbox and its dome a gradient; light units are converted
    properly (sun as irradiance, area lamps x area x pi, points x 4pi, the
    dome / pi, the sun doubled for AgX); the lacquer gets a shader bevel and
    the bronze renders as a metal; the crate base sits inside its walls.
    Two bugs found on the way: the glTF importer builds unlit sky planes as
    emission for camera rays only, so the closed rooms had no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
2026-10-05 earworm in-ear, a softer earwig, and earmilk's pint tweeter and milk crate
    The owner's notes of 2026-10-04 and 2026-10-05:
    - earworm is now wired in-ear earphones: bullet earbuds (gunmetal cap,
    graphite shell, silicone tip), a worm burrowing into the back of each,
    a splitter, the saddle on the right branch as the remote, the plug. The
    worm's segments overlap like a jointed toy snake (the owner kept that
    texture). The over-ear renders move to renders/over-ear/.
    - earwig is a little less grotesque: shorter forceps with rounded tips,
    overlapping plates on the stem, a cream case, a sleek side-parted bob,
    taupe tips (a cream inner half round a dark tip read as an eyeball).
    - earmilk (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
    [baffle-l.step, baffle-l.stl, baffle-r.stl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]
2026-10-05 earmilk refinement round 1 and v15; spin-off round 2 fixes
    - All seven earmilk frames path-traced at v14 (renders/2026-10-05), each sent to a
    fresh critic: refinement round 1 logged for 01, 02a, 02b, 03, 04, 05 and 06
    (scores 4 to 5).
    - v15 briefs and scenes for every shot: the rooms' windows moved so the sun lands
    on the cabinets, a key for the bowl close-up that reaches the tweeter, a side key,
    darker sweep and metal-only reflector for the back, a high front-left softbox for
    the line-up, and a lower, squarer 85 mm camera for the crate with a grey wall.
    - Model bugs the critics found: the port's flange was a solid disc over the bore
    (now a ring with a rounded lip), and every dus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
    [bud-cap.step, bud-l.step, bud-mesh.step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]
2026-10-05 earmilk refinement round 2 and v16; earworm v3 and earwig v6 set up
    - All seven earmilk v15 frames path-traced (renders/2026-10-05) and sent to
    fresh critics: refinement round 2 logged (scores 4 to 5).
    - A render bug every round had reported: the cabinet's finish is built
    panel by panel, one mesh each, and Cycles' bevel only sees its own object,
    so the corners where front meets side were never eased. render/pathtrace.py
    now joins each cabinet's finish into one object before rendering.
    - v16 briefs and scenes for every shot: the hero half a stop down (its sunlit
    sides clipped) with the chair set down; a top softbox mirrored in the bowl
    close-up's red slope, lighting the bowl's flo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
2026-10-05 earmilk refinement round 3 (v16) and the spin-offs' last rounds
    - All seven earmilk v16 frames path-traced and sent to fresh critics:
    round 3 logged, the last in this batch (01 5, 02a 5, 02b 4, 03 4, 04 4,
    05 5, 06 5), with what a next pass should do and the owner's questions the
    rounds raised (letter metal on light plinths, Chocolate's pale throat, a lip
    at the bowl's mouth, shot 04's straight-on brief).
    - earworm in-ear v3 and earwig softer v6 rendered and judged: both looks have
    had their three rounds (earworm hero 4, detail 5; earwig hero 5, detail 6).
    - README: the eased-arris note says what v16 fixed.
    Claude-Session: ht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
2026-10-06 Critic rounds 1 to 3 on the owner's update: earmilk v17 to v20, earworm v4 to v6, earwig v7 to v9
    The owner's points of 2026-10-06 (dark letters on the light plinths, a
    polished lip at the scoop, a three-quarter back view, Chocolate's throat
    run dark; the earwig's tails hanging loose as a flexible exoskeleton, no
    hair, a wing-case lid) went through a new critic batch: three rounds per
    shot, each round logged in its critic/LOG.md.
    earmilk ended at 01 5, 02a 5, 02b 4, 03 5, 04b 5, 06 5 (round 1 was 4 to
    5). 04a and 05 stopped early: their critics asked for the three-quarter
    camera their briefs rule out. Two real faults found and fixed:
    - a grey ring round every driver: the shader's eased edge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
2026-10-08 Both sizes from one parameter file, the components modelled, the active crossover plan, critic rounds staged by script
    - fab/params.py: EARMILK_SIZE=bookshelf builds a 220 x 220 two-way beside the floorstander; outputs in fab/out-bookshelf
    - fab/components.py: the chosen drivers (Dayton RSS315HF-4, SB Satori MR16P-8 and TW29DN-B; SB17NRX2C35-8 and
    Scan-Speak D3004/602200 for the bookshelf) and the Hypex FusionAmp plates, modelled from their datasheets
    - fab/sheets.py: five A3 sheets from the CAD, including the tweeter insert's wiring and fixing
    - fab/dsp.py: a starting setup for the plate amplifier's DSP per size
    - fab/research: the amplifier and driver research
    - critic/round.py: stages a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
2026-10-08 Both sizes built and checked, the tweeter's wiring drawn and rendered, the engine's cutaways and exploded views
    - fab: the connector bay behind the insert's boss; the tweeter's lead, connector, grommet, gland, magnets and pins
    modelled; clearance checks on every build (they caught the bookshelf's brace through its amplifier box, now gone,
    and its boss in the top panel, now 60); the bookshelf's waveguide is BkD (crossover 2.4 kHz); the floorstander's
    C22 run densely, with polar maps for both (wg_polar.py); sheet 3 draws the tweeter's lead, connector, channel and
    grommet; fab/README.md and bom.csv rewritten for two active sizes
    - studio/engine: product.explode (offsets per part), produ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
    [amp-box-floor.dxf, amp-box-floor.step, amp-box-floor.stl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]
2026-10-08 Critic round e1 on six shots applied; the engine's colour zones cut at their boundary; a light meter
    - studio/engine: a colour zone now cuts the faces it crosses before colouring them, so the plinth's red wraps the
    rounded corners (a tall corner face took the body's white by its centre); named glints; meter.py reads the
    scene's true brightness by part or region three stops under and gives the exposure to a target
    - critic rounds e1 for 01 (and its e2), 02a, 04a, 04b saved and applied; 04b metered and corrected (e3);
    cards for 08b; the engine README
    - bookshelf decals from its own print files; the sideboard's turntable can move
    Cl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
2026-10-08 Critic rounds e1 on every shot applied; the engine reads critic values robustly; an exact light meter
    - studio/engine: values as critics write them (a signed number on a default, a trailing remark, a padded glint
    list) apply or are held back with the reason, never crash a render; faceted CAD surfaces (the waveguide) shade
    smooth by an angle rule, so a gloss coat no longer mirrors the facets; cut faces take a shader per rule (the
    printed insert plain grey, not wood grain); meter.py reads scene-linear EXR, exact from black cones to clipped
    whites
    - critic/PROMPT.md: "to" as plain JSON, remarks in "expected"
    - rounds e1 saved and applied for 02b, 03, 05, 08, 08b, 09, round e2 for 01; e3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
2026-10-08 The engine places glints from the true surface, probes reflections, tunes settings by proof, aims the sun through a window
    - Glints snap to the surface the camera sees at their point and take its own normal; a glint whose
    lamp would sit behind the floor or inside the product is skipped, and the critic's card says why.
    - probe.py: what a part mirrors into the camera (lamps, set, sky), by share, frame box and direction.
    - tune.py: one setting moved by the secant between proof renders until a critic's test passes.
    - autoexpose stays within 1 EV and refuses to clip the product's whites.
    - A panel light: an emissive, graduated rectangle the camera cannot see, for gloss to mirror.
    - sun.aim: the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
2026-10-08 The engine shades the waveguide from its true surface, finds the inside past loose parts, adds flags and multi-stop panels
    - fab/horn_grid.py writes the waveguide's analytic wall as a fine grid; the engine sets the insert's
    shading normals from it (normals_from), so a gloss coat no longer mirrors the ruled loft's facets.
    - Interior faces: covered faces within 12 mm; cables, plugs, grommets and glands no longer count as walls.
    - Flags and bounce cards for any set (center_m, size_m, normal); panels take several ramp stops.
    - autoexpose reads channel tests; tune takes its own tests; glint distance and size documented.
    - A hex colour may replace a kelvin value; the critic's card gets the rende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
2026-10-09 Sheet 3: the tweeter lead's and the connector bay's leaders no longer cross
    The lead's label now sits under the bay's, since its target is further in and lower; both sizes regenerated.
    Also critic round 4 for 04a, saved.
    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
2026-10-09 Engine: reflect-only flags are one-sided; a glint's occlusion test ignores the surface itself
    Two bugs a critic found by measuring 04b-e6. A reflect-only flag lying on the floor showed in the sweep's own gloss as
    a straight-edged patch (the floor looking up at the card's back): such flags are now one-sided by default, seen only
    from the side their normal faces, so the product's lacquer still mirrors them and the floor sees through. And a glint
    on a connector was always skipped for an occluder "0.00 m away": the bezel sits inside the amp module, so the
    occlusion ray left through the module's back face at once. The test now ignores hits within 2 mm of its start and
    faces seen from behind, and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
2026-10-09 The product's own materials are fixed, on the card and in the engine
    The 04a critic was offered materials.paint.coat_roughness and asked for a satin clear coat to blur the fin's print
    mirrored in the roof; tuned to the least that clears its test it needed 0.26, satin, on one frame of twelve, while
    the 10 and 01 critics took the clear coat as the product's finish. It is: the card now offers only the set's materials
    (oak, plaster, sweep) and says the product's are fixed like its geometry, and the engine holds back a round's change
    to a product preset with the reason. 04a goes back to the product's coat; whether the lacquer should be satin is an
    owner question.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
2026-10-09 critic: 09 round 5 (6.0, 7.5 if fixed); render.py evaluates the scene before reading parts' positions
    The masks-only pass read the parts' and the camera's matrices before any render had evaluated the scene, so 07-e6's
    exploded parts landed behind the camera in its report.
    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
2026-10-09 fab: the drawing check's fixes, round 1 (3.5/10)
    The tweeter goes in from behind through one 73.4 bore to the throat, its flange on the throat's seat with four M3
    heat-set inserts; the front dowels behind the insert's pocket (to 0.5 mm, so the sheets print what the router
    cuts); the lid's gland drawn from its front edge; the rebates 1.0 deeper for a flange gasket; the upper magnets
    level with the throat; the amplifier's box and the port in section A-A; the drivers' screw holes, the plate's
    4.5 rebate on EPDM, the fixings' positions and fits; the trim rings exported with a channel over the screw heads;
    the port 5 mm shorter; sheet 6 with the inner panels; tolerances in every title block; no t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
    [amp-box-floor.dxf, amp-box-floor.step, amp-box-front.dxf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]
2026-10-09 critic: 07 round 6 (5.5, 7.0 if fixed): the front the lit face, a kick for the insert, a strip for the motors
    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
2026-10-09 critic: 03 round 5 (5.5, 6.8 if fixed): a wider lens and the target up so the whole roof and fin are in frame
    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
2026-10-09 fab: the drawing check's round 2 fixes in the sources (the outputs regenerate next)
    The floorstander's tweeter is held by a printed retaining sleeve over its motor, screwed to the boss's back face
    outside the bore: no screw goes through the tweeter, whose own screws thread into its motor from the front (d1).
    The bookshelf's faceplate screws are M2.5 low heads into bonded knurled inserts (d2, d10). The insert's fit is
    toleranced and it is painted on its face only (d3); the trim rings take their bore from the surround (d4); the
    printed gable comes in six resin-sized pieces keyed by pins (d5); the pocket is dimensioned (d6); the lid's
    counterbore is in its DXF (d8); the pins are bonded (d9); th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
    [bom.csv]
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2026-10-09 Fab outputs for the drawing check's round 2 fixes: the tweeter's retaining sleeve (STL, STEP), the printed gable in six pieces, the rings' bores, the channel's silicone seal; sheet 3's notes and labe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
    [amp-box-floor.dxf, amp-box-floor.step, amp-box-floor.stl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]
2026-10-09 critic: 09 round 6 (6.0, 7.5 if fixed): a ramp the fronts mirror, a black card for the left fin, less fill, a smaller print, a rug
    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
2026-10-09 Drawings, round 3: the bookshelf insert round its boss, the gable printed in pieces, eight sheets at 2.5 mm
    The drawing check's round 3 (4.5): the bookshelf insert's outline grown 0.5 over its boss so it slides into its
    pocket (d1), its boss and bore shortened to keep 4 mm of gable over them (d4), the gable printed in four pinned
    pieces (d2); the floorstander's pocket bore deepened behind the sleeve's screw heads (d3) and the sleeve's screws
    turned off the insert's split (d5); one M16 gland per cable, fitted after the finish (d8); the trim rings' channels
    inside their width (d9); the plate's screws one value everywhere (d10); the connector in the bay and the silicone
    plug under it (d12); the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
    [amp-box-floor.dxf, amp-box-floor.step, amp-box-front.dxf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]
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2026-10-09 critic: 04b round 10 (5.5, 6.5 if fixed): the key up for a lacquer white, the contact's reach, the connectors off the clip, a kicker
    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
2026-10-09 critic: 09 round 7 (5.5, 7.4 if fixed): the pair larger in frame, the whites out of the shoulder, more sky, a strip for the roofs, the sheen down
    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
2026-10-09 Fab: the drawing check's round 5 (6.0): the gable's layers follow the ply, the T-nuts' birch checked, the sleeve's preload, the pocket's holes, the runs, the fixings on sheet 5
    d1, the blocker, stands: the bought parts are not measured yet, and the set says to
    measure first. The rest: the top panel's front edge marked; the divider sealed to the
    top panel; the printed parts' drain holes placed; the insert solid or hollow; the
    bookshelf's inserts sized; the plate's thickness in M5; a DATS for the port; inner
    panels at one fence setting; the floorstander's runs along the brace; a speaker's
    fixings on sheet 5 and five more lines in bom.csv; extension lines on the roof's dims.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
    [amp-box-floor.dxf, amp-box-floor.step, amp-box-front.dxf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]
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2026-10-09 Drawing check round 6: pin clearances, lid underside file, cable mounts and plan sections, printed gable plan, datasheet facts
    The round-6 reply (5.5) fixed throughout: every pinned joint's holes 0.5 deeper than half
    its pin; the amp lid's counterbores in their own DXF drawn turned over; the sleeve's flange
    85 with its screws on 78.8; the bookshelf's rear dowels under 8 of block; the mid chamber's
    top sealed by a PU fillet from the open front; ten cable-tie mounts a floorstander, stuck
    on before each panel goes in, drawn on sections A-A and E-E; sections D-D and E-E in plan
    on sheet 2; the printed gable's split planes and pins on sheet 3; hole angles on sheet 1;
    the divider's face named; fit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
    [amp-box-floor.dxf, amp-box-floor.step, amp-box-front.dxf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]
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2026-10-09 Engine: a glint whose mirror ray meets a part moves its lamp in front of it
    A glint skipped because its surface mirrors another part into the camera (01's
    cone mirroring its own surround 0.19 m off, its letters the floor 0.24 m off) now
    places its lamp at 60 % of that gap, its size scaled with the distance and its power
    with the square, so it looks the same from the point and, linked to its receivers,
    lights nothing else; only a gap under 5 cm still skips it. Behind
    EARMILK_GLINT_MOVE_IN=1 until the jobs already running finish on the old rule. The
    card names each moved lamp.
    Claude-Session: https://claude.ai/code/session_016Hs9fK3h2VwV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
2026-10-09 Critic card: the last rounds on the shot, so a round does not undo the one before unknowingly
    The card lists the last round's changes with its tests measured on the new frame,
    and every setting more than one of the last three rounds changed (05's sweep:
    lightened in round 6, darkened again in round 7), and asks a critic who reverses
    one to say why the trade is worth it.
    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
2026-10-09 Engine: a lamp's shadow on the set lightened alone; critic round 7 on shot 08 e10
    lights.NAME.shadow_on_set f splits a lamp in three: it lights the product as
    given, a copy at f of its power lights the set with the product's shadow, and
    another at the rest lights the set through the product (Cycles shadow linking), so
    the shadow on the floor is f as dark and nothing on the product changes. For 08's
    key, whose long shadow bands the copy floor. Round 7 judged 08 e10 6.0 (7.3 if fixed).
    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
2026-10-09 Drawing check round 8: the TW29DN-B from SB's drawing, a connector test bay, the divider cut short, closed STLs
    The floorstander's tweeter is drawn as SB draws it, one ø70 body 21.7 behind its
    faceplate, in a bore that centres it, the cap 18 long with 3 mm of wall for its
    screws and the lead 320; the bookshelf's D3004 gets a go or no-go for its depth and
    a check of its tabs; a printable test bay for the connector, both sizes; the
    divider cut 1 short instead of planed in place; every STL closed and checked; the
    print service's tolerance, the pocket's corners, the top panel's felt, the lid's
    second set-up on the part, the woofer ring's visible heads, and the README's
    figures. Sheet 7's headin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
    [amp-box-floor.dxf, amp-box-floor.step, amp-box-front.dxf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]
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
